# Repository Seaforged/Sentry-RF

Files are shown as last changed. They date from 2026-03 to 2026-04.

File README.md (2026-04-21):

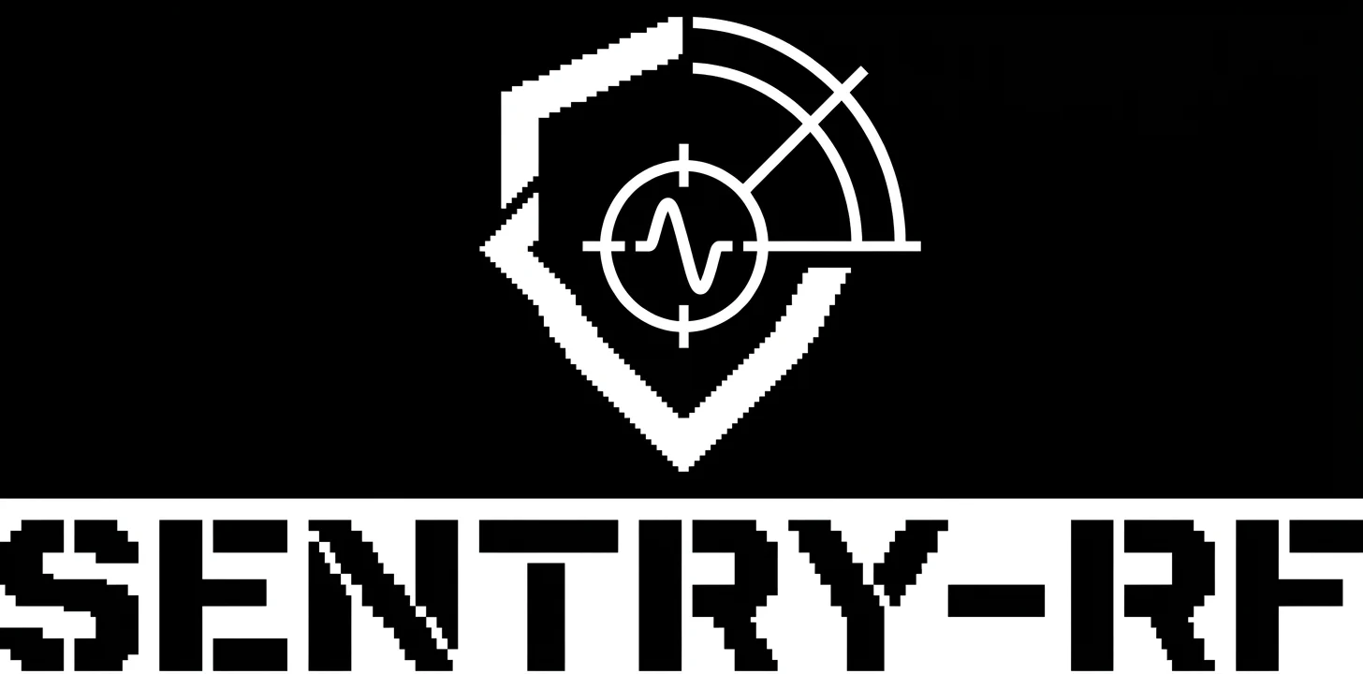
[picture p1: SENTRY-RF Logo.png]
SENTRY-RF


# SENTRY-RF

**Passive drone RF detection + GNSS jamming/spoofing monitor for ESP32-S3**




SENTRY-RF is an open-source counter-UAS trip-wire that detects drone control links and monitors GPS integrity using low-cost ESP32 hardware. No SDR required, no laptop required, no subscription. Built by [Seaforged](https://seaforged.io), a veteran-owned company.

---

## What It Does

**RF Drone Detection** — Passive scanning across 860–930 MHz (sub-GHz) and 2400–2500 MHz (2.4 GHz on LR1121 boards). Detects ExpressLRS, TBS Crossfire, SiK telemetry, mLRS, and other drone control links by matching FHSS patterns against known protocol signatures. Protocol-agnostic energy detection catches custom and encrypted links too.

**WiFi Remote ID** — Parses ASTM F3411 WiFi Beacon frames in real-time using the ESP32-S3's built-in WiFi in promiscuous mode. Identifies drones broadcasting FAA-mandated Remote ID with no extra hardware.

**GNSS Integrity Monitoring** — Reads u-blox M10 jamming indicators, spoofing detection state, and per-satellite C/N0 uniformity via UBX binary protocol. Emits standalone alerts on rising GNSS threat level (jam / spoof / position-jump / C/N0 uniformity anomaly); the candidate engine additionally uses GNSS anomalies as a confirm-score boost when RF detection has been active in the last 30 s. Position-jump detection compares consecutive NAV-PVT reports for >100 m teleports with tight hAcc — a signature of rebroadcast spoofing.

**Threat Classification** — Correlates RF detections with GNSS anomalies to produce actionable threat levels: `CLEAR → ADVISORY → WARNING → CRITICAL`. Buzzer alerts on WARNING+.

---

## Detection Performance (Bench Validated)

Tested against [Juh-Mak-In Jammer](https://github.com/Seaforged/Juh-Mak-In-Jammer) v2.0.0 drone signal emulator, April 2026:

| Protocol | Time to WARNING | Time to CRITICAL |
|---|---|---|
| ELRS 200Hz FCC915 | 3–12 s | 12–20 s |
| ELRS 25Hz FCC915 | ~71 s | — |
| TBS Crossfire FSK | ~34 s | — |
| SiK Telemetry | ~6 s | — |
| WiFi Remote ID | ~24 s | ~83 s |
| LoRaWAN (false positive test) | — stays ADVISORY | PASS |
| Meshtastic (false positive test) | — stays ADVISORY | PASS |

Field tested (v1.5.3, SX1262): 842m WARNING, 1022m ADVISORY against 158mW ELRS transmitter in suburban environment.

---

## Supported Hardware

| Board | Radio | Bands | Display | Status |
|---|---|---|---|---|
| **LilyGo T3S3** | Semtech SX1262 | 860–930 MHz | SSD1306 128×64 OLED | ✅ Field tested |
| **LilyGo T3S3 LR1121** | Semtech LR1121 | 860–930 MHz + 2400–2500 MHz | SSD1306 128×64 OLED | ✅ Bench validated |
| **Heltec WiFi LoRa 32 V3** | Semtech SX1262 | 860–930 MHz | SSD1306 128×64 OLED | ✅ Builds clean |

**GPS:** u-blox M10 module (HGLRC M100 Mini, FlyFishRC M10QMC, or similar) connected via UART. Auto-detects baud rate (115200/38400/9600).

**Optional:** QMC5883L compass for signal bearing, passive piezo buzzer for alerts, SD card for logging.

---

## Quick Start

### Prerequisites
- [PlatformIO](https://platformio.org/) (CLI or VS Code extension)
- One of the supported boards
- u-blox M10 GPS module + 4 jumper wires

### Build and Flash

```bash
git clone https://github.com/Seaforged/Sentry-RF.git
cd Sentry-RF

# Build for your board
pio run -e t3s3            # LilyGo T3S3 (SX1262)
pio run -e t3s3_lr1121     # LilyGo T3S3 LR1121 (dual-band)
pio run -e heltec_v3       # Heltec WiFi LoRa 32 V3

# Flash
pio run -e t3s3 --target upload

# Monitor serial output
pio device monitor
```

### GPS Wiring

| GPS Pin | T3S3 SX1262 | T3S3 LR1121 | Heltec V3 |
|---|---|---|---|
| TX → board RX | GPIO 44 | GPIO 43 | GPIO 46 |
| RX → board TX | GPIO 43 | GPIO 44 | GPIO 45 |
| VCC | 3.3V | 3.3V (QWIIC) | 3.3V |
| GND | GND | GND (QWIIC) | GND |

> **Note:** LR1121 QWIIC connector reverses data pins compared to the SX1262 sister board.

---

## OLED Display

7 screens, cycled via BOOT button press:

| Screen | Content |
|---|---|
| **Dashboard** | Threat level, GPS status, WiFi channel activity chart, peak RF signal, battery |
| **Sub-GHz Spectrum** | 860–930 MHz waterfall with peak frequency/power |
| **GPS** | Fix type, satellites, PDOP, coordinates, altitude, accuracy |
| **GNSS Integrity** | Jamming state, jamming indicator, spoofing detection, C/N0 deviation |
| **Threat Detail** | RF peak, GPS+jam+spoof status, buzzer state, bearing |
| **System** | Version, uptime, heap, buzzer/compass status |
| **2.4 GHz Spectrum** | 2400–2500 MHz waterfall (LR1121 boards only) |

See [`docs/OLED_Screen_Glossary.md`](docs/OLED_Screen_Glossary.md) for field-by-field reference.

---

## Architecture

- **FreeRTOS dual-core:** LoRa scanning on Core 1, GPS/WiFi on Core 0
- **Detection engine:** CAD (Channel Activity Detection) for LoRa preamble detection + RSSI sweep for energy detection + FHSS frequency-spread tracker for hopping signal classification
- **Protocol classifier:** Matches detected signals against 220+ drone protocol signatures
- **Ambient discrimination:** Learns background RF during warmup, filters LoRaWAN/Meshtastic/smart meter infrastructure from drone detections
- **Threat scoring:** Weighted combination of CAD confidence, frequency diversity, persistence, velocity, RSSI, and GNSS integrity

---

## Companion Projects

| Project | Description |
|---|---|
| [Juh-Mak-In Jammer](https://github.com/Seaforged/Juh-Mak-In-Jammer) | Drone signal emulator for testing SENTRY-RF. Emulates ELRS, Crossfire, SiK, mLRS, Remote ID, and infrastructure protocols. |
| **D-TECT-R** | Commercial counter-UAS product (separate from SENTRY-RF) |
| **TESTKIT-GPS** | GPS spoofing/jamming test tool using AntSDR E200 (planned) |

---

## Project Status

**v1.6.1-rc1** — Bench validated, April 2026.

Recent milestones:
- LR1121 dual-band board fully operational (CAD detection fix, 2.4 GHz bandwidth fix)
- FHSS frequency-spread tracker for hopping signal detection
- WiFi Remote ID detection via ESP32-S3 promiscuous scanning
- GPS auto-baud detection (115200/38400/9600)
- Boot-time antenna self-test with soft-warn
- 7-screen OLED UI with WiFi channel activity dashboard

Known limitations:
- mLRS detection stays at ADVISORY (narrow hop set, tuning gap)
- LR1121 ambient warmup list saturates in noisy RF environments
- 2.4 GHz CAD BW800 fix untested (needs 2.4 GHz transmitter)
- De-escalation after signal stops takes ~15 seconds (by design)

See [`docs/SENTRY-RF_Known_Issues_Tracker.md`](docs/SENTRY-RF_Known_Issues_Tracker.md) for full backlog.

---

## Documentation

| Document | Description |
|---|---|
| [`docs/OLED_Screen_Glossary.md`](docs/OLED_Screen_Glossary.md) | Field-by-field reference for every OLED display element |
| [`docs/Protocol_RF_Reference.md`](docs/Protocol_RF_Reference.md) | 220+ drone protocol signatures |
| [`docs/SENTRY-RF_Known_Issues_Tracker.md`](docs/SENTRY-RF_Known_Issues_Tracker.md) | Known issues and backlog |
| [`CLAUDE.md`](CLAUDE.md) | Claude Code project context |

---

## License

[MIT](LICENSE) — use it however you want.

## Contributing

Issues and PRs welcome. This is built in public by a veteran-owned company. If you see something that could be better, open an issue.

## Contact

- **Website:** [seaforged.io](https://seaforged.io)
- **GitHub:** [github.com/Seaforged](https://github.com/Seaforged)

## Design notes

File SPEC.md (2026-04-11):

# Spec: SENTRY-RF v1.6.0 — LR1121 Stabilization Release

**Status:** APPROVED 2026-04-10 — proceeding to PLAN phase
**Date:** 2026-04-10
**Author:** ND + Claude Code (agent-skills:spec-driven-development)

---

## Objective

Ship **SENTRY-RF v1.6.0** as a public release by end of day Sunday 2026-04-12, focused on stabilizing the T3S3 LR1121 board for first real-signal validation. The weekend "tester" is ND himself — goals are: (1) confirm the LR1121 board boots cleanly, renders all screens, and does not crash under load, and (2) observe and understand how the AAD detection engine reacts to real ELRS signals on both sub-GHz (915 MHz) and 2.4 GHz using a newly-acquired RadioMaster transmitter. A future external tester will receive the same build Monday or later.

**This is a stabilization release, not a feature release.** Everything on the "not yet built" list in `.mex/ROUTER.md` stays on the roadmap.

### Why this matters

- The LR1121 build has never been soak-tested or exercised against a real controlled RF signal — only bench ambient
- The 2.4 GHz CAD phase (added this week) has never seen a real 2.4 GHz ELRS signal
- The AAD detection engine's behavior on real signals has been validated on SX1262 (842m suburban field test) but not on the LR1121
- v1.5.3 on LR1121 has known-visible bugs (version string, unconfirmed spectrum rendering) that a first-time viewer will notice immediately

## Tech Stack

No changes from v1.5.3. See `.mex/context/stack.md` for the full list:
- C++ Arduino framework, PlatformIO, ESP32-S3
- RadioLib v7.6.0 (pinned — no upgrades this weekend)
- SparkFun u-blox GNSS v3, Adafruit SSD1306 + GFX
- FreeRTOS dual-core, 5 tasks pinned across Core 0 / Core 1

## Commands

All three targets must compile clean:
```
pio run -e t3s3 -e heltec_v3 -e t3s3_lr1121
```

LR1121-specific build / flash / monitor:
```
pio run -e t3s3_lr1121
pio run -e t3s3_lr1121 --target upload --upload-port COM14
pio device monitor -b 115200 -p COM14
```

Soak test (existing script, new application to LR1121):
```
cd C:\Projects\sentry-rf
python soak_test.py COM14 120   # 2-hour soak on LR1121
```

Signal response test (manual — RadioMaster TX + ND observation):
```
# Terminal 1:
python field_logger.py COM14

# Meanwhile: power up RadioMaster ELRS 915 MHz, observe serial + OLED
# Repeat for ELRS 2.4 GHz
```

## Project Structure

No structural changes. Existing layout stays:
- `include/` — board config, sentry config, task config, detection types
- `src/` — main, cad_scanner, rf_scanner, detection_engine, gps_manager, wifi_scanner, display, alert_handler, buzzer_manager
- `docs/` — gets a new `DETECTION_ENGINE_WALKTHROUGH.md` this weekend
- `test/lr1121_hello/` — existing hello sketch, left alone

See `.mex/context/architecture.md` for the FreeRTOS task layout.

## Code Style

No changes from v1.5.3. See `.mex/context/conventions.md`. Key reminders:
- No hardcoded pins — everything via `board_config.h`
- All three targets must compile clean before any commit
- Board-specific code wrapped in `#ifdef BOARD_T3S3 / BOARD_HELTEC_V3 / BOARD_T3S3_LR1121`
- LR1121 RSSI uses `LR1121_RSSI::getInstantRSSI()`, not bare `getRSSI()`

## Testing Strategy

Three test levels for this release:

### 1. Build verification (5 min, every commit)
`pio run -e t3s3 -e heltec_v3 -e t3s3_lr1121` must succeed with zero errors. This is the baseline gate.

### 2. Boot and render verification (10 min, after every LR1121 flash)
Flash, power cycle, manually verify:
- Serial banner prints `SENTRY-RF v1.6.0` within 2 seconds
- OLED splash → dashboard transition within 60 seconds (warmup)
- All 7 screens cycle cleanly via short BOOT button press
- Spectrum screens (sub-GHz and 2.4 GHz) show visible bars, not blank
- System screen has no text/page-dot collision
- No error messages on OLED, no crashes in serial
- First `[CAD]` line shows `score=5` (baseline after warmup)

### 3. Signal response and soak (weekend, manual, ND-driven)
- **Saturday afternoon:** RadioMaster ELRS 915 MHz within ~1-5m of antenna → observe serial + OLED while the detection engine escalates from CLEAR through ADVISORY → WARNING → CRITICAL. Turn TX off, observe cooldown. Capture serial log for the walkthrough document.
- **Saturday evening:** Same exercise at ELRS 2.4 GHz. This is the first-ever real 2.4 GHz ELRS signal test on this codebase.
- **Sunday morning:** 2-hour LR1121 bench soak with no drones present — no crashes, no false positives above ADVISORY, memory stable (monitor heap via serial).
- **Sunday afternoon:** Multi-environment walk — bench → backyard → rural road → suburban — with the RadioMaster running. Confirm detection works end-to-end.

**Test recording:** All serial sessions captured with `field_logger.py` for reference in the walkthrough doc and release notes.

## Boundaries

### Always
- Run `pio run -e t3s3 -e heltec_v3 -e t3s3_lr1121` before every commit
- Connect the antenna before powering on any board (non-negotiable; RF damage)
- Use the mex workflow — read `.mex/ROUTER.md` at the start of each session, update on GROW
- Commit after every working increment, not at the end of a sprint
- Tag known-good states as we go (e.g., `v1.6.0-rc1` before the soak test)

### Ask first
- Anything that touches `sentry_config.h` constants (AAD gates, scoring weights, thresholds) — these are field-calibrated and we don't tune them without data
- Adding a new `#ifdef` guard (risk of board-specific drift)
- Changing the FreeRTOS task layout (priorities, cores, stack sizes)
- Modifying the Detection Engine scoring math

### Never
- Add BLE Remote ID, 2.4 GHz protocol classification, operational modes, or any other "not yet built" item from ROUTER
- Upgrade RadioLib mid-weekend
- Push to origin without an explicit "push it" from ND
- Use `--no-verify` or `--force` on git operations
- Remove failing tests or soak data to make things look clean

## Success Criteria

v1.6.0 ships if and only if **all** of these are true by Sunday evening:

1. **Clean build:** `pio run -e t3s3 -e heltec_v3 -e t3s3_lr1121` — zero errors, zero warnings introduced this release
2. **Version sanity:** `grep -r "v1.2.0-FIX4\|v1.5.3" src/ include/` returns nothing (after the fix); `version.h` reads `1.6.0`; boot banner prints `SENTRY-RF v1.6.0`
3. **Boot behavior on LR1121:** Serial banner within 2 seconds of USB plug-in on a fresh flash, no template placeholders, no error dumps
4. **All 7 OLED screens render** on the LR1121 with no visible text collisions or blank chart areas. Verified by ND's eyes, captured in photos for the release notes
5. **Boot self-test catches a missing antenna** (Tier 2 work item below) — remove the SMA antenna, power on, confirm OLED shows `ANTENNA CHECK` or equivalent, confirm scan task does not start
6. **Real signal response on sub-GHz** — RadioMaster ELRS 915 MHz at close range drives the LR1121 from CLEAR → CRITICAL within 15 seconds. Cooldown returns to CLEAR within 15 seconds after TX off
7. **Real signal response on 2.4 GHz** — RadioMaster ELRS 2.4 GHz at close range produces visible detection in the serial log (CAD taps increment, or persDiv rises). **No target timing number** — document actual observed timing for future calibration. The 2.4 GHz CAD phase has never seen a real ELRS 2.4 signal; this is a first-light test, not a benchmark.
8. **2-hour soak on the LR1121** — zero cycles above WARNING with no drone present, zero crashes, heap stable within ±5% of start
9. **`docs/DETECTION_ENGINE_WALKTHROUGH.md` exists** — annotated serial log from the real-signal tests, explaining what each `[CAD]` field means and how the AAD gates fire in practice
10. **v1.6.0 tagged, release notes written, pushed to origin** — public GitHub release with the walkthrough doc and field test summary linked

If any of 1-9 fail, do NOT do 10. Ship when green, not when the calendar says so.

## Work Items (prioritized)

### TIER 1 — Small, low-risk (Saturday morning, before RadioMaster arrives)
- [ ] **T1.1 Version audit** — grep for `v1.2.0-FIX4` and stale v1.5.x references in `src/` and `include/`, remove. Bump `version.h` to `1.6.0`. (~15 min)
- [ ] **T1.2 Serial boot banner sanity** — flash LR1121, confirm banner prints cleanly within 2s of USB plug-in. Fix if not. (~15 min)
- [ ] **T1.3 Visual verification of spectrum bar rendering** — power on LR1121, cycle to Sub-GHz and 2.4 GHz spectrum screens, confirm bars are visible (not blank). Photograph for release notes. (~15 min)
- [ ] **T1.4 System screen collision check** — cycle to Screen 5 on the LR1121, confirm "Buz: ... Cmp: ..." line does not overlap the page dots. (~5 min)
- [ ] **T1.5 GPS + buzzer bring-up** — with the newly-wired GPS + buzzer, confirm `[GPS] Fix:3` in serial within 60s outdoors, and buzzer self-test tone on boot. (~30 min)
- [ ] **T1.6 All-three build gate** — `pio run -e t3s3 -e heltec_v3 -e t3s3_lr1121`. (5 min)

### TIER 2 — Stabilization (Saturday afternoon)
- [ ] **T2.1 Boot self-test: antenna check (ALL 3 boards)** — at the end of `scannerInit()`, sweep 10 test frequencies across 860-928 MHz and read RSSI. If all ≤ threshold (config constant, default -125 dBm), display `ANTENNA CHECK` on OLED and halt the scan task. If any > threshold, proceed normally. Implement once in `rf_scanner.cpp`, wire into all three board targets (SX1262 T3S3, Heltec V3, LR1121). Test SX1262 first (known-working baseline from the 30-min soak), then Heltec, then LR1121. Document the threshold as a config constant. (~3-6 hrs)
- [ ] **T2.2 Human-readable error messages on init failure** — replace `RADIO HW FAIL: -12` with a table lookup that maps common RadioLib error codes to operator-friendly text. (~1-2 hrs)
- [ ] **T2.3 Boot banner print order cleanup** — ensure `SENTRY-RF v1.6.0` prints BEFORE any init errors, so tester sees the version even on a failed boot. (~30 min)

### TIER 3 — Real-signal validation (Saturday afternoon → Sunday evening)
- [ ] **T3.1 Sub-GHz 915 MHz ELRS response test** — flash LR1121, power up RadioMaster ELRS 915, capture serial log with `field_logger.py`. Observe: time-to-ADVISORY, time-to-WARNING, time-to-CRITICAL, peak score, peak `persDiv`, cooldown-to-CLEAR. Compare against SX1262 baseline (6.4s WARNING / 11.2s CRITICAL). (~1-2 hrs)
- [ ] **T3.2 2.4 GHz ELRS response test (FIRST EVER)** — flash LR1121, power up RadioMaster ELRS 2.4 GHz, capture serial log. Observe: does the 2.4 GHz CAD phase produce hits? Does `div` increase? Does `persDiv` activate? Pass criterion is "detection is visible in serial log," tighter timing metrics are nice-to-have. (~1-2 hrs)
- [ ] **T3.3 Multi-environment walk** — with RadioMaster running, walk bench → backyard → rural → suburban, observe detection stability. No specific range goal (that's a post-stabilization exercise). (~1-2 hrs)
- [ ] **T3.4 2-hour LR1121 bench soak** — no drones present. Zero escalations above ADVISORY target. Use existing `soak_test.py COM14 120`. (~2 hrs, mostly waiting)

### TIER 4 — Tester enablement + release (Sunday afternoon / evening)
- [ ] **T4.1 `docs/DETECTION_ENGINE_WALKTHROUGH.md`** — annotated walkthrough of a real sub-GHz ELRS session. Show the serial log, explain each `[CAD]` field (cycle, conf, taps, div, persDiv, vel, sustainedCycles, score), map the AAD gates to observed behavior, explain why score stays at 5 until sustainedCycles hits 5, show the ambient warmup, show the diversity gate firing. Uses logs captured in T3.1/T3.2. (~2-3 hrs)
- [ ] **T4.2 Release notes for v1.6.0** — public-facing. Headline: first LR1121 stabilization release. Include: what was fixed, what was added (dual-band CAD, boot self-test), what's known-limited (2.4 GHz timing not yet calibrated), what's next on the roadmap. Link to the walkthrough doc. Include signal-response metrics from T3.1. (~1 hr)
- [ ] **T4.3 Update `.mex/ROUTER.md` Current Project State** — mark v1.6.0 as shipped, move completed items out of "not yet built", update "Known issues". (~15 min)
- [ ] **T4.4 Tag `v1.6.0`, create GitHub release, push to origin** — only if all Success Criteria are met. (~30 min)

### TIER 5 — Explicitly cut from this release (stays on roadmap)
- SD card fix (hardware limitation)
- BLE Remote ID scanning (feature, roadmap Phase D1)
- 2.4 GHz protocol classification (feature, roadmap Phase C1)
- Per-band diversity tracking (refactor, roadmap Phase C2)
- Dual-band correlation engine (feature, roadmap Phase D2)
- Operational modes COVERT / HIGH_ALERT (feature, roadmap Phase E1)
- Tester-oriented quickstart doc (ND is the weekend tester, defer until external tester confirmed)

## Resolved Questions (2026-04-10)

1. **2.4 GHz timing target:** No target number. Document actual observed timing; future release will calibrate against it.
2. **Boot self-test scope:** All three boards (SX1262 T3S3, Heltec V3, LR1121). Test order: SX1262 → Heltec → LR1121 to build on a known-good baseline.
3. **Walkthrough doc location:** `docs/DETECTION_ENGINE_WALKTHROUGH.md` in the SENTRY-RF repo, linked from the v1.6.0 release notes.
4. **Soak script compatibility:** Serial format is identical to SX1262, so `soak_test.py` should work as-is. Verify during T3.4; if it fails, it's a script bug not a firmware bug.

## Verification (before proceeding to PLAN phase)

- [ ] This spec covers all six core areas (Objective, Stack, Commands, Structure, Code Style, Testing Strategy, Boundaries)
- [ ] ND has reviewed and approved the spec
- [ ] Success criteria are specific and testable
- [ ] Boundaries (Always / Ask First / Never) are defined
- [ ] The spec is saved to `SPEC.md` in the repository root
- [ ] Open questions have proposed answers or are marked for resolution

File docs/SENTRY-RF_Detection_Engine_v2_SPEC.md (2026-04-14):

<!-- ACTIVE SPEC — supersedes SENTRY-RF_Detection_Engine_v2_Redesign.md and SENTRY-RF_Architecture_Checklist.md -->
<!-- Last updated: April 14, 2026 | Current phase: COMPLETE -->

# SENTRY-RF Detection Engine v2.0 — Unified Implementation Spec
## Candidate-Centric Evidence Fusion: The Build Contract

**Status:** ACTIVE — supersedes all prior detection engine planning documents  
**Supersedes:** `SENTRY-RF_Detection_Engine_v2_Redesign.md`, `SENTRY-RF_Architecture_Checklist.md`  
**Use `SENTRY-RF_Session_Handoff.md` for:** onboarding/context only  
**Authors:** Claude (technical lead) + Codex (adversarial review) + ND (project owner)  
**Last updated:** April 13, 2026  
**Current codebase:** v1.8.0 — commit 61dae2e  

---

## Part 1 — Why This Redesign Exists

The v1.8.0 detection engine uses **global counters**. Every piece of evidence — CAD taps, RSSI peaks, protocol matches, Remote ID, GNSS anomalies — feeds into one shared fast score and one shared confirm score. This causes three failures:

**1. Unrelated evidence summation.**  
A single infrastructure LoRa tap (fast=10) plus a real WiFi RID broadcast (confirm=30) equals WARNING. These are completely unrelated events that happened to occur in the same scan window. They should never promote each other.

**2. Brittle confirmation timing.**  
Confirm evidence only exists on the exact RSSI sweep cycle (`freshRssi=true`) and vanishes on non-sweep cycles. One good sweep should provide confirmation that persists for several seconds across multiple scan cycles — not disappear the moment the next non-sweep cycle runs.

**3. No candidate association.**  
The engine cannot say "this RSSI peak at 919 MHz corroborates this CAD tap at 919.2 MHz." It just sums everything globally. There is no concept of a specific detection event that evidence must attach to in order to promote.

**The fix: candidate-centric evidence fusion.**  
Sub-GHz CAD creates a detection candidate. Subsequent evidence — RSSI, protocol match, 2.4 GHz CAD, Remote ID, GNSS anomaly — must be *explicitly associated* with that candidate to promote it. Evidence decays with configurable TTLs measured in wall-clock milliseconds, not scan cycles.

---

## Part 2 — Architecture

```
┌─────────────────────────────────────────────────────────┐
│                      SCAN LAYER                          │
│  cadSubGHzFskScan() → CadBandSummary + anchor           │
│  cad24Scan()        → CadBandSummary + anchor (timer)   │
│  scannerSweep()     → ScanResult sub-GHz (timer)        │
│  scannerSweep24()   → ScanResult24 2.4 GHz (timer)      │
│  wifiScanTask()     → RID evidence (async)               │
│  gpsTask()          → GNSS integrity (async)             │
└───────────────────────────┬─────────────────────────────┘
                             │
                             ▼
┌─────────────────────────────────────────────────────────┐
│                   CANDIDATE ENGINE                        │
│                                                          │
│  DetectionCandidate[MAX_CANDIDATES=6]                    │
│                                                          │
│  ┌────────────────────────────────────────────────┐     │
│  │ candidate 0 (sub-GHz, SEEDING → TRACKING)       │     │
│  │   anchor:    919.2 MHz / SF6                    │     │
│  │   freqRange: [918.5, 920.1 MHz]                 │     │
│  │   cadConf:   {score=40, lastSeen=Xms, live}     │     │
│  │   fhssSub:   {score=15, lastSeen=Xms, live}     │     │
│  │   sweepSub:  {score=5,  lastSeen=Xms, live}     │     │
│  │   protoSub:  {score=15, lastSeen=Xms, live}     │     │
│  │   rid:       {score=0,  dead}                   │     │
│  │   → fast=55, confirm=20 → WARNING               │     │
│  └────────────────────────────────────────────────┘     │
│                                                          │
│  ┌────────────────────────────────────────────────┐     │
│  │ candidate 1 (confirmer role only)               │     │
│  │   cad24: {score=10, lastSeen=Xms, live}         │     │
│  │   → attaches to candidate 0 (temporal match)    │     │
│  └────────────────────────────────────────────────┘     │
│                                                          │
│  chooseBestCandidate() → ThreatDecision                  │
└───────────────────────────┬─────────────────────────────┘
                             │
                             ▼
┌─────────────────────────────────────────────────────────┐
│                     THREAT FSM                            │
│  Fast up: direct jump to evidence-warranted level        │
│  Slow down: one step per COOLDOWN_MS                     │
│  emitThreatTransition(prev, next, nowMs) on change       │
└─────────────────────────────────────────────────────────┘
```

### Main Loop Execution Order (mandatory)

The following order is required in `src/main.cpp`. Deviating from this order breaks the fast-alert guarantee.

```
1. cadSubGHzFskScan()              → produces CadBandSummary + anchor
2. detectionEngineIngestCadSubGHz() → refreshes candidate fast evidence
3. detectionEngineAssess()          → produces ThreatDecision, updates FSM
4. publish threat to systemState    → OLED, LED, buzzer, log see result

[on timer] sub-GHz sweep ingest
[on separate timer] LR1121 2.4 GHz CAD ingest
[on separate timer] LR1121 2.4 GHz sweep ingest
```

**The 2.4 GHz scan must never run before the first assess of the same cycle.** It is a confirmer. It never drives the fast-alert path.

---

## Part 3 — Data Structures

These structs are the exact contract CC must implement. Do not deviate without ND sign-off.

### 3.1 EvidenceTerm

```cpp
struct EvidenceTerm {
    uint8_t  score;        // Current score value (0 = dead)
    uint32_t lastSeenMs;   // millis() when last refreshed
    uint32_t ttlMs;        // Evidence expires when (millis() - lastSeenMs) > ttlMs
    bool     ready;        // Per-evidence readiness gate (see Part 6)
};
```

An EvidenceTerm is **live** when: `ready == true && score > 0 && (millis() - lastSeenMs) <= ttlMs`

### 3.2 CandidateState

```cpp
enum CandidateState : uint8_t {
    CAND_EMPTY,      // Slot is free
    CAND_SEEDING,    // Just created, first CAD anchor seen
    CAND_TRACKING,   // Active, live fast evidence
    CAND_CONFIRMED   // ThreatDecision is WARNING or CRITICAL
};
```

### 3.3 DetectionCandidate

```cpp
struct DetectionCandidate {
    CandidateState      state;
    bool                active;
    uint8_t             bandMask;        // 1=subGHz, 2=2.4GHz, 3=both
    float               anchorFreq;      // MHz — frequency of best CAD tap at creation
    float               minFreqSeen;     // MHz — lowest frequency associated so far
    float               maxFreqSeen;     // MHz — highest frequency associated so far
    const DroneProtocol* protoHint;      // nullptr until protocol matched; NEVER store stale pointer
    uint32_t            firstSeenMs;
    uint32_t            lastSeenMs;
    EvidenceTerm        cadConfirmed;    // Confirmed CAD taps (consecutiveHits >= 2)
    EvidenceTerm        cadPending;      // Pending CAD taps (single hit)
    EvidenceTerm        fskConfirmed;    // Confirmed FSK taps
    EvidenceTerm        fhssSub;         // FHSS velocity / spread evidence
    EvidenceTerm        sweepSub;        // RSSI sweep corroboration
    EvidenceTerm        protoSub;        // Protocol signature match
    EvidenceTerm        cad24;           // 2.4 GHz CAD corroboration
    EvidenceTerm        proto24;         // 2.4 GHz protocol match
    EvidenceTerm        rid;             // WiFi Remote ID
    EvidenceTerm        gnss;            // GNSS anomaly temporal correlation
};
```

**Critical implementation note on `protoHint`:**  
Always initialize to `nullptr`. When `resetCandidate()` is called, set `protoHint = nullptr` immediately. Never read `protoHint` without checking `!= nullptr` first. A reset candidate with a stale non-null `protoHint` silently influences scoring — this is a subtle bug CC must be guarded against explicitly.

### 3.4 CadEvidenceAnchor (add to CadBandSummary)

```cpp
struct CadEvidenceAnchor {
    bool    valid;
    float   frequency;        // MHz of best tap
    uint8_t sf;               // Spreading factor of best tap
    bool    isFsk;
    uint8_t consecutiveHits;  // Hits on this tap in last cycle
};
```

Add to `CadBandSummary`:
```cpp
CadEvidenceAnchor anchor;
uint32_t          capturedMs;    // millis() when summary was produced
bool              warmupReady;   // ambient filter has run >= MIN_AMBIENT_CYCLES
bool              hwFault;       // cadHwFaultFlag debounced true
```

### 3.5 ThreatDecision

```cpp
struct ThreatDecision {
    ThreatLevel level;
    uint8_t     fastScore;
    uint8_t     confirmScore;
    float       anchorFreq;     // MHz of driving candidate
    uint8_t     bandMask;       // bands contributing to decision
    bool        hasCandidate;   // false = RID-only ADVISORY
};
```

---

## Part 4 — Configuration Constants

Add all of the following to `include/sentry_config.h`. These are the values as of April 13, 2026. Do not hardcode any of these inline in .cpp files.

```cpp
// --- Candidate engine sizing ---
#define MAX_CANDIDATES              6
#define CAND_AGE_OUT_MS             12000   // Evict if all evidence dead > 12s

// --- Association windows ---
#define CAND_ASSOC_SUB_MHZ          1.0f    // Sub-GHz evidence must be within ±1 MHz of anchor
#define CAND_ASSOC_24_MHZ           4.0f    // 2.4 GHz evidence association window ±4 MHz
#define CAND_ASSOC_SUB_TTL_MS       6000    // Sub-GHz evidence attaches only if candidate seen within 6s
#define CAND_ASSOC_24_TTL_MS        5000    // 2.4 GHz evidence attaches only if candidate seen within 5s

// --- Evidence TTLs (milliseconds) ---
#define TTL_CAD_CONFIRMED_MS        2500
#define TTL_CAD_PENDING_MS          2500
#define TTL_FSK_CONFIRMED_MS        2500
#define TTL_FHSS_SUB_MS             3000
#define TTL_SWEEP_SUB_MS            4500
#define TTL_PROTO_SUB_MS            6000
#define TTL_CAD24_MS                5000
#define TTL_PROTO24_MS              5000
#define TTL_RID_MS                  10000
#define TTL_GNSS_MS                 8000

// --- Scoring policy thresholds ---
#define POLICY_ADVISORY_FAST        15
#define POLICY_WARNING_FAST         40
#define POLICY_WARNING_CONFIRM      5
#define POLICY_CRITICAL_FAST        40
#define POLICY_CRITICAL_CONFIRM     30
#define POLICY_RID_ONLY_ADVISORY    30      // RID confirm score for ADVISORY without RF candidate

// --- Fast score component caps ---
#define FAST_SCORE_CAD_PER_TAP      10
#define FAST_SCORE_CAD_CAP          40
#define FAST_SCORE_FSK_PER_TAP      15
#define FAST_SCORE_FSK_CAP          30
#define FAST_SCORE_DIVERSITY_BONUS  20
#define FAST_SCORE_FHSS_CLUSTER     15
```

---

## Part 5 — Candidate Creation Rules

A candidate **may only be created** by `detectionEngineIngestCadSubGHz()` when ALL of the following are true:

- `summary.anchor.valid == true`
- `summary.hwFault == false`
- At least one is true:
  - `confirmedCadCount > 0`
  - `confirmedFskCount > 0`
  - `strongPendingCad > 0`
  - `persistentDiversityCount > 0`
  - `diversityVelocity >= DIVERSITY_VELOCITY_FHSS_MIN`

A candidate **must never be created** by:
- 2.4 GHz CAD
- Sweep-only evidence
- Remote ID
- GNSS

This keeps the fast-trigger path identical across SX1262, Heltec V3, and LR1121.

---

## Part 6 — Association Rules

These rules determine whether a piece of evidence attaches to an existing candidate. Evidence that fails association is discarded (or, for RID/GNSS, generates a standalone ADVISORY only).

### Sub-GHz evidence (CAD, sweep, protocol)

Attaches to a candidate only if **all** are true:
- `candidate.active == true`
- `millis() - candidate.lastSeenMs <= CAND_ASSOC_SUB_TTL_MS`
- Evidence frequency is in the same regional band as the candidate (US 902–928 MHz or EU 860–870 MHz)
- **And at least one** of:
  - `fabs(freq - candidate.anchorFreq) <= CAND_ASSOC_SUB_MHZ`
  - `freq` falls within `[candidate.minFreqSeen - 1.0, candidate.maxFreqSeen + 1.0]`
  - Candidate has live `fhssSub` evidence AND freq is in the same regional band (FHSS association by band)

When evidence attaches, update `candidate.minFreqSeen` and `candidate.maxFreqSeen` to expand the range if needed.

### 2.4 GHz evidence (CAD, sweep, protocol)

Attaches to a sub-GHz candidate only if **all** are true:
- At least one active sub-GHz candidate exists
- `millis() - candidate.lastSeenMs <= CAND_ASSOC_24_TTL_MS`
- **And one** of:
  - Exactly one live sub-GHz candidate exists (unambiguous association)
  - One candidate's fast score exceeds the next-best candidate's fast score by at least 15 (clear leader)

2.4 GHz evidence **never creates a candidate**. It is confirmer-only.

### Remote ID and GNSS

Attach only if:
- Exactly one live candidate exists

If RID or GNSS cannot be uniquely attached to a single candidate, they may generate a standalone RID-only ADVISORY (if `ridScore >= POLICY_RID_ONLY_ADVISORY`) but **must not promote any RF candidate to WARNING or CRITICAL**.

---

## Part 7 — Evidence Readiness Gates

These gates determine whether each evidence type is allowed to contribute to scoring. This replaces the old global warmup cap.

| Evidence | Ready When |
|---|---|
| `cadConfirmed` | Always (cycle 1) |
| `cadPending` | Always (cycle 1) |
| `fskConfirmed` | Always (cycle 1) |
| `fhssSub` | `persistentDiversityCount > 0` OR `diversityVelocity >= DIVERSITY_VELOCITY_FHSS_MIN` |
| `fhssCluster` | `diversityCount >= 8` AND `fastConfirmedCadCount >= 1` |
| `sweepSub` | `ambientFilterReady()` OR peak matches a known protocol family OR candidate already has live fast evidence |
| `protoSub` | Always when `match.protocol != nullptr` |
| `bandEnergy` | `ambientFilterReady()` only; attach as candidate-confirm only |
| `cad24` | Only as confirmer on existing live sub-GHz candidate |
| `proto24` | Only as confirmer on existing live sub-GHz candidate |
| `rid` | Always (independent hardware) |
| `gnss` | GPS has valid 3D fix |

### Progressive ambient tagging (B.5 — must happen BEFORE shadow mode)

During warmup, after each `recordAmbientTap()` call: immediately scan all live candidate taps and mark any tap at that frequency as `isAmbient`. Do not wait until warmup ends to do a batch tag. This prevents warmup-period infrastructure taps from being inherited as evidence into the candidate engine.

---

## Part 8 — Candidate Lifecycle

### States

| State | Meaning | Entry Condition |
|---|---|---|
| `CAND_EMPTY` | Slot free | Initial / after eviction |
| `CAND_SEEDING` | Just created | First valid sub-GHz CAD anchor |
| `CAND_TRACKING` | Active | Any live fast evidence |
| `CAND_CONFIRMED` | Promoted | `ThreatDecision.level >= WARNING` |

### Age-out and eviction

- A candidate is aged out when **all evidence terms are dead** for `> CAND_AGE_OUT_MS`
- Eviction order when all slots full: **oldest inactive candidate first**, then **lowest total live score**
- Caveat: do not evict the only `CAND_CONFIRMED` candidate unless it has been dead for `> CAND_AGE_OUT_MS`

### Required lifecycle helpers (implement in `src/detection_engine.cpp`)

```
resetCandidate()           — zero all fields, protoHint = nullptr
findCandidateForBandFreq() — returns best matching candidate or nullptr
allocCandidate()           — finds empty slot or evicts per eviction rules
refreshEvidence()          — updates score + lastSeenMs on a term if association passes
evidenceLive()             — returns bool: ready && score > 0 && not expired
ageOutCandidates()         — marks CAND_EMPTY on fully-expired candidates
computeFastScore()         — returns uint8_t: sum of live fast terms, capped
computeConfirmScore()      — returns uint8_t: sum of live confirm terms
chooseBestCandidate()      — returns ThreatDecision from highest-scoring live candidate
```

---

## Part 9 — Scoring Policy

Scoring uses **candidate-attached evidence only**. Global scores do not exist in v2.0.

### Fast score (per candidate)

```
fast = cadConfirmed.score
     + cadPending.score
     + fskConfirmed.score
     + (fhssSub live     ? FAST_SCORE_DIVERSITY_BONUS : 0)
     + (fhssCluster live ? FAST_SCORE_FHSS_CLUSTER    : 0)
```

Component values:
- Confirmed CAD taps: `FAST_SCORE_CAD_PER_TAP` per tap, cap `FAST_SCORE_CAD_CAP`
- Confirmed FSK taps: `FAST_SCORE_FSK_PER_TAP` per tap, cap `FAST_SCORE_FSK_CAP`
- `fhssSub` live when sustained diversity is present:
  `persistentDiversityCount > 0` OR
  `diversityVelocity >= DIVERSITY_VELOCITY_FHSS_MIN`
- Live `fhssSub`: `+FAST_SCORE_DIVERSITY_BONUS`
- Live `fhssCluster`: `+FAST_SCORE_FHSS_CLUSTER`
  with `diversityCount >= 8` AND `fastConfirmedCadCount >= 1`

### Confirm score (per candidate)

```
confirm = sweepSub.score
        + protoSub.score
        + bandEnergy.score
        + cad24.score
        + proto24.score
        + rid.score
        + gnss.score
```

Component values:

| Evidence | First attach | Persistent (re-attaches) |
|---|---|---|
| `sweepSub` (RSSI corroboration) | 5 | 10 |
| `protoSub` (protocol match) | 15 | 15 |
| `cad24` (2.4 GHz corroboration) | 10 | 10 |
| `proto24` (2.4 GHz protocol) | 15 | 15 |
| `rid` (WiFi Remote ID) | 30 | 30 |
| `gnss` (anomaly correlation) | 25 | 25 |

### Threat policy

```
ADVISORY:   fast >= POLICY_ADVISORY_FAST
WARNING:    fast >= POLICY_WARNING_FAST  &&  confirm >= POLICY_WARNING_CONFIRM
CRITICAL:   fast >= POLICY_CRITICAL_FAST &&  confirm >= POLICY_CRITICAL_CONFIRM
RID-only:   confirm(rid) >= POLICY_RID_ONLY_ADVISORY  (no fast evidence required)
```

**All fast and confirm evidence must come from the SAME candidate.** Fast score from candidate 0 cannot combine with confirm score from candidate 1.

### FSM behavior

- **Fast up:** Direct jump to the level warranted by current evidence (no step-by-step escalation)
- **Slow down:** One step per `COOLDOWN_MS`
- **Transitions:** `emitThreatTransition(prevThreat, currentThreat, millis())` — this is the single emit point for buzzer, LED, display updates, and log entries on state change

---

## Part 10 — Phase Plan

Phases must be executed in this exact order. Do not skip phases or combine them out of sequence.

---

### Phase A — Foundation Fixes
**Risk:** Zero — corrective only, no behavior change  
**Acceptance:** All three targets build clean. Serial output identical to pre-A.

**A.1 — Fix escalation emitter** (`src/detection_engine.cpp`)  
Save `prevThreat` before computing `desired`. Add `emitThreatTransition(prev, next, nowMs)` helper. Replace all inline transition emit code with single call to this helper. No-op if `prev == next`.

**A.2 — Replace sweepTimeMs validity check** (`src/main.cpp`)  
Replace `localResult.sweepTimeMs > 0 ? &localResult : nullptr` with `localResult.valid ? &localResult : nullptr`. If `ScanResult` lacks a `valid` field, add `bool valid = false;` to the struct and set `valid = true` only on successful sweep completion.

**A.3 — Initialize logSnapshot safely** (`src/main.cpp`)  
Change declaration to `SystemState logSnapshot = {};`. Skip `loggerWrite()` if mutex was not acquired.

**A.4 — Add all configuration constants** (`include/sentry_config.h`)  
Add the full block from Part 4 above. Build to verify no name collisions with existing constants.

---

### Phase B — Enriched CAD Summaries
**Risk:** Low — additive struct extension, no logic change  
**Acceptance:** Build clean. Anchor frequency visible in `[CAD]` serial debug output. Existing threat behavior unchanged.

**B.1 — Add `CadEvidenceAnchor` and new fields to `CadBandSummary`** (`include/cad_scanner.h`)  
Add the structs defined in Part 3.4 above.

**B.2 — Implement `chooseAnchor()`** (`src/cad_scanner.cpp`)  
Priority: best confirmed non-ambient tap → strongest pending tap → first active tap. Helpers: `tapEligibleAsAnchor()`, `betterAnchor()`, `chooseAnchor()`.

**B.3 — Populate anchor in `fillBandSummary()`** (`src/cad_scanner.cpp`)  
Call `chooseAnchor()` in both LR1121 and SX1262 `cadFskScan()` paths. Keep all legacy aggregate fields intact.

---

### Phase B.5 — Progressive Ambient Tagging During Warmup
**Risk:** Low — changes warmup behavior, not detection policy  
**Acceptance:** Cold boot, 5 runs each board. Zero false WARNING/CRITICAL in first 60 seconds. Check `[AMBIENT]` serial output shows infrastructure taps tagged progressively, not in a batch at warmup end.

**B.5.1 — Move ambient tagging to per-cycle** (`src/cad_scanner.cpp` near line 1117)  
After each `recordAmbientTap(freq)` call, immediately iterate all live taps and set `isAmbient = true` on any tap matching that frequency. Do not wait for warmup to end.

**B.5.2 — Remove post-warmup batch reset** (`src/cad_scanner.cpp`)  
Delete or disable the block that clears all taps/proto arrays when warmup ends. Infrastructure taps should be progressively marked ambient throughout warmup, not wiped in batch.

**B.5.3 — Verify no regression** in Phase A/B serial output before continuing.

---

### Phase C — Shadow-Mode Candidate Engine
**Risk:** Low — new code runs in parallel, actual threat output unchanged  
**Acceptance:** See shadow-mode acceptance criteria in Part 11.

**C.1 — Add candidate structs and TTL config** (`include/detection_engine.h`, `include/sentry_config.h`)  
Implement `EvidenceTerm`, `DetectionCandidate`, `ThreatDecision`, `CandidateState` per Part 3.

**C.2 — Implement candidate lifecycle helpers** (`src/detection_engine.cpp`)  
Implement all helpers listed in Part 8. Pay special attention to `protoHint = nullptr` in `resetCandidate()`.

**C.3 — Shadow-mode evaluation in `detectionEngineAssess()`**  
After the existing scorer runs:
- Ingest current CAD summary into candidate engine
- Compute candidate-based `ThreatDecision`
- Log: `[CAND] fast=%d conf=%d level=%s anchor=%.1fMHz ttMs=%lu`
- Log mismatches: `[CAND-DELTA] legacy=%s candidate=%s`
- **Do NOT change actual threat output**

**C.4 — Bench validation (required before Phase D)**  
Run each scenario and collect serial logs:
- SX1262: 10 min clean bench
- LR1121: 10 min clean bench
- SX1262: 3 runs JJ ELRS (time to ADVISORY, WARNING)
- LR1121: 3 runs JJ ELRS (time to ADVISORY, WARNING)
- Both boards: cold boot x5 (watch first 60s)

Bring logs to Claude before proceeding to Phase D.

---

### Phase D — Candidate Engine Cutover
**Risk:** Medium — this changes actual threat behavior. Run full validation before AND after.  
**Acceptance:** See Part 11. Both boards must pass before this phase is complete.

**D.1 — Cut over CAD ingest to per-candidate** (`src/detection_engine.cpp`, `src/main.cpp`)  
`detectionEngineIngestCadBandSummary()` refreshes candidate fast evidence.
`detectionEngineIngestCad24BandSummary()` refreshes cad24 on existing
candidates only (never creates). Aggregate CAD/FSK counters may remain wired
to the legacy comparison scorer until Phase G, but they must not drive the
real FSM or candidate scoring.

**D.2 — Cut over sweep ingest to candidate confirmation** (`src/detection_engine.cpp`)  
First corroborating sweep: `sweepSub.score = 5`, `sweepSub.ttlMs = TTL_SWEEP_SUB_MS`. Protocol match: `protoSub.score = 15`. Persistent sweep: upgrade score in-place.

**D.3 — Replace `assessThreat()` with `chooseBestCandidate()`**  
`chooseBestCandidate()` becomes the real threat decision path. Keep
`lastFastScore`, `lastConfirmScore` for display/logging. Legacy global scoring
may remain comparison-only for regression alarming until Phase G, but it must
not commit `currentThreat` or emit real transitions.

**D.4 — Run full validation suite** (see Part 11).

---

### Phase E — Per-Evidence Readiness Cleanup
**Risk:** Medium — changes cold-start behavior  
**Acceptance:** Cold boot x5 each board, zero false WARNING/CRITICAL in first 60 seconds.

**E.1 — Apply readiness gates per Part 7**  
Implement per-evidence `ready` flag logic. Remove any remaining global
warmup-cap references from the candidate path. The legacy `assessThreat()`
comparison path may retain private warmup housekeeping until it is removed in
Phase G, but it must not influence candidate scoring or the real FSM.

**E.2 — Verify Phase B.5 ambient tagging is working correctly**  
By this phase, progressive ambient tagging (B.5) should have already eliminated the batch-reset problem. This phase verifies it holds under the candidate engine.

---

### Phase F — LR1121 2.4 GHz Off Critical Path
**Risk:** Low — scheduling change only  
**Acceptance:** LR1121 ADVISORY latency matches SX1262 within 2 seconds on the same JJ trace.

**F.1 — Split `cadFskScan()` into `cadSubGHzFskScan()` + `cad24Scan()`** (`src/cad_scanner.cpp`, `include/cad_scanner.h`)  
Sub-GHz scan returns immediately → ingest → assess → threat decision. 2.4 GHz scan runs on `LR24_CAD_PERIOD_MS` timer.

**F.2 — Wall-clock scheduling in `main.cpp`**  
Replace `cycleCount % RSSI_SWEEP_INTERVAL` with `millis() >= nextSubGHzSweepMs`. Add `nextLr24CadMs`, `nextLr24SweepMs` timers.

**F.3 — Verify LR1121 non-sweep cycle time ~= SX1262 (~1500ms)**

---

### Phase G — Diagnostics and Cleanup
**Risk:** Zero — additive  
**Acceptance:** Build clean with zero new warnings. Legacy scoring code gone.

**Status: COMPLETE — April 14, 2026**
Legacy `assessThreat()` removed. Candidate engine is now the sole decision
path for `currentThreat` and FSM transitions. `[CAND-DELTA]` logging removed.
`legacyThreat`, `lastThreatEventMs`, `cleanSinceMs`, `freshRssiThisCycle`, and
the `*ThisCycle` aggregate counters removed along with their populate shim
`detectionEngineIngestCad()` and the dead backward-compat wrappers
`detectionEngineSetCadFsk()` / `detectionEngineUpdate()`.

**G.1 — Expose candidate diagnostics to `SystemState`** ✅
Added `fastScore`, `confirmScore`, `anchorFreq`, `bandMask`, `hasCandidate`,
`candidateCount` to `SystemState`. Mirrored from `ThreatDecision` inside
`detectionEngineAssess()` via new accessors (`detectionEngineGetAnchorFreq()`,
etc). Shown on OLED threat screen as a `CAND:` line when a candidate is
active (replaces the `LAST: Xs ago` fallback line). Already logged via
`[CAND]` serial line.

**G.2 — Delete legacy code** ✅
Removed `assessThreat()` (173 lines), `legacyThreat`, `lastThreatEventMs`,
`cleanSinceMs`, `freshRssiThisCycle`, and the eight `*ThisCycle` aggregate
counters. Removed `detectionEngineIngestCad()`, `detectionEngineSetCadFsk()`,
`detectionEngineUpdate()`. Removed 20 legacy weight and threshold constants
from `sentry_config.h` (`WEIGHT_DIVERSITY_PER_FREQ` through
`WEIGHT_FAST_DETECT`, `SCORE_ADVISORY/WARNING/CRITICAL`,
`FAST_DETECT_MIN_*`, `FAST_ADVISORY_THRESH`, `FAST_WARNING_THRESH`,
`CONFIRM_WARNING_THRESH`, `CONFIRM_CRITICAL_THRESH`, `CONFIRM_ADVISORY_THRESH`,
`WEIGHT_FAST_PERSISTENT_DIV`, `WEIGHT_FAST_FHSS_VELOCITY`). Kept the five
`WEIGHT_CONFIRM_*` constants that the candidate engine actively consumes.
Kept `CadFskResult` — it's the live data-transfer struct between
`cadFskScan()` and the candidate engine, not a legacy artifact.

**G.3 — Fix version string** ✅
`include/version.h` — bumped `FW_VERSION` from `"1.6.0"` to `"1.9.0-rc1"`
with a phase-completion note.

**G.4 — Spec doc updated** ✅
Phase marker moved from `F` to `COMPLETE`, this section stamped with the
completion status.

---

## Part 11 — Acceptance Criteria

### Shadow-mode acceptance (Phase C → D gate)

All of the following must be true before cutting over:

| Scenario | Requirement |
|---|---|
| Clean bench, 10 min, all 3 boards | Zero WARNING/CRITICAL |
| Cold boot x5 each board | Zero false WARNING/CRITICAL in first 60s |
| JJ ELRS ADVISORY | ≤ 4 seconds |
| JJ ELRS WARNING | ≤ 10 seconds |
| JJ ELRS CRITICAL | Only when confirm evidence is attached to same candidate as fast evidence |
| LR1121 vs SX1262 on same JJ trace | ADVISORY within 2s wall-clock |
| Multiple unrelated evidence sources | Do NOT promote each other unless association rules pass |

The metric "better than legacy on >80% of cycles" is explicitly **not** an acceptance gate. One false CRITICAL in a 10-minute run fails the run.

### Final acceptance (Phase D complete)

| Metric | Target |
|---|---|
| SX1262 ADVISORY latency | ≤ 4 seconds |
| SX1262 WARNING latency | ≤ 10 seconds |
| LR1121 ADVISORY latency | ≤ 4 seconds (after Phase F) |
| FP: no drone, 30 min | Zero WARNING/CRITICAL |
| FP: dense LoRa bench | Zero WARNING/CRITICAL (candidate isolation) |
| Board parity | Within 2s wall-clock |
| Cold-boot false alerts | Zero in first 60 seconds |

### COM14 (LR1121) bench acceptance note

The LR1121's higher sensitivity detects persistent sub-GHz bench emitters
(observed at 902.3, 912.2, 914.7 MHz) that survive warmup ambient tagging.
These produce intermittent false ADVISORY in cold-boot captures, typically
at 40-60 seconds post-warmup. This is a test environment condition, not a
code defect. The SX1262 (COM9) passes 5/5 across all Phase E runs.

Phase E acceptance is declared on the basis of:

- 5/5 COM9 cold-boot PASS
- Zero false WARNING or CRITICAL on either board
- Correct `[CAND-DELTA] legacy=ADVISORY candidate=CLEAR` chronic-noise
  filter operation on COM14 throughout (candidate engine correctly
  suppresses the aggregate 2.4 GHz diversity the legacy scorer fires on)

LR1121 field validation (with appropriate antenna and no bench emitters)
is required before deployment. The bench emitters observed during Phase E
testing cannot be replicated in code — they are real RF sources that a
production deployment would not see, and any gate tight enough to block
them would also block real low-power FHSS signals.

---

## Part 12 — What Remains Outside This Redesign

These items are known but explicitly out of scope for v2.0:

- **Buzzer and LED alert methods** — GPIO 16 passive piezo (KY-006), LED system
- **GNSS jamming/spoofing host-side algorithms** — beyond the GNSS evidence term in this engine
- **LR1121 2.4 GHz image recalibration latency** — `setBandwidth(812.5, true)` triggers ~1250ms recal; investigate but not blocking
- **LR1121 RSSI sweep GFSK params** — board-specific calibration (freqDev, rxBw) needed vs SX1262 defaults
- **Heltec V4 node integration** — distributed sensing, after v2.0 stable
- **TESTKIT-GPS / AntSDR E200** — spoofing/jamming test signal generation
- **MemPalace** — ChromaDB + MCP cross-project memory system

---

## Part 13 — Known Active Issues (as of April 13, 2026)

| Issue | Severity | Resolution |
|---|---|---|
| GPS_MIN_CNO = 6 | 🔴 MUST FIX before field deployment | Raise to 15–20 |
| LR1121 bench FP on dense LoRa | 🟡 Known | Candidate isolation (Phase D) |
| Version string bug main.cpp:422 | 🟡 Minor | Phase G.3 |
| 2.4 GHz cycle slow (~3900ms) | 🟡 Known | Phase F (moves off critical path) |
| CC work unvalidated until flashed | ⚠️ Process | Hardware flash required before trusting any sprint |

---

## Part 14 — How We Work

| Role | Responsibility |
|---|---|
| **Claude** | Architecture decisions, sprint planning, CC prompt generation, pre-flash review |
| **Claude Code (CC)** | Code implementation, file editing, git operations |
| **ND** | Final decisions, all hardware interaction, serial capture, field testing |
| **Codex/ChatGPT** | Adversarial reviews at major milestones |

**CC work is not validated until flashed.** Commits after compile-only verification are treated as unproven. Hardware validation is mandatory before trusting any sprint output.

**Git:** Author `ND <ndywoo10@gmail.com>`. Always build all three targets before committing.

**Targets:** `t3s3`, `heltec_v3`, `t3s3_lr1121`

---

*This document is the single source of truth for SENTRY-RF Detection Engine v2.0.*  
*All prior planning documents are superseded.*  
*Last updated: April 13, 2026 — Claude + Codex + ND*

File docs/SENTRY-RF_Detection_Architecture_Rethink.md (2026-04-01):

# SENTRY-RF Detection Architecture Rethink
## The Right Discriminator for FHSS Drone Detection

**Date:** April 1, 2026  
**Status:** Architecture proposal for review before implementation

---

## The Problem We Keep Solving Wrong

Across Sprints 1A through 2B-fix, we've iterated through dozens of threshold combinations trying to distinguish drone LoRa signals from ambient LoRa infrastructure on a busy bench. Every approach follows the same pattern:

1. Find a metric (hit count, persistence, rolling buffer, live taps)
2. Set a threshold that catches drones
3. Discover that ambient LoRa also exceeds the threshold
4. Add another filter or raise the threshold
5. Discovery that drones now fall below the threshold
6. Repeat

**This cycle will never end because we're measuring the wrong feature.**

All our metrics count *how many* detections occur. But both drones and infrastructure produce LoRa CAD hits — the *count* overlaps. What distinguishes them is *where* those hits occur across the frequency band.

---

## The Key Insight: Frequency Spread

A drone FHSS link (ELRS 200 Hz, 80 channels) produces CAD hits scattered across **dozens of distinct frequencies** within any 5-second window. A LoRaWAN gateway produces CAD hits on **2-3 fixed frequencies**. A Meshtastic node produces hits on **1 frequency**.

The discriminator isn't how many hits — it's **how many DISTINCT frequencies** produced hits within a time window.

| Source | Hits in 5s | Distinct frequencies | Spread pattern |
|---|---|---|---|
| ELRS drone (200 Hz, 80ch) | 3-8 | 3-8 different | Scattered across 902-928 MHz |
| LoRaWAN gateway (8ch, 1/15s) | 0-2 | 1-2 fixed | Clustered on fixed channels |
| Meshtastic node | 0-1 | 1 fixed | Single frequency |
| 3 ambient sources combined | 1-4 | 2-4 fixed | Few distinct, repeating |

**A drone with 3 CAD hits on 3 different frequencies is fundamentally different from infrastructure with 3 CAD hits on 1-2 frequencies, even though the hit count is identical.**

---

## Proposed Architecture: Frequency Diversity Scoring

Replace the current `recentHitCount` (total hits in 30s) with a **frequency diversity score** that counts distinct frequencies with CAD hits in a sliding window.

### Data Structure

```
FrequencySlot {
    float frequency;      // Center frequency of the hit
    uint8_t sf;           // Spreading factor
    unsigned long lastHitMs;  // When this frequency was last hit
    bool active;          // Is this slot occupied?
}

FrequencyDiversityTracker {
    FrequencySlot slots[32];  // Track up to 32 distinct frequencies
    int slotCount;            // Number of active slots
    
    void recordHit(float freq, uint8_t sf);  // Add/update a slot
    int countActiveFrequencies(unsigned long windowMs);  // Count distinct freqs hit within window
    void prune(unsigned long maxAge);  // Remove expired slots
}
```

### Recording Logic

When a non-ambient CAD hit occurs at frequency F:
1. Check if F is already in the tracker (within ±200 kHz)
2. If yes: update `lastHitMs` (same frequency hit again — doesn't increase diversity)
3. If no: add a new slot (new frequency — increases diversity)

### Threat Assessment

```
diversityCount = tracker.countActiveFrequencies(5000);  // Distinct freqs in last 5s

// FHSS signature: hits on 3+ distinct frequencies in 5 seconds
// Infrastructure: hits on 1-2 frequencies (gateway channels repeat)
if (diversityCount >= 4) → CRITICAL (definitive FHSS pattern)
if (diversityCount >= 2) → WARNING (possible FHSS, strong evidence)
if (diversityCount >= 1) → ADVISORY (single CAD hit, monitoring)
if (diversityCount == 0) → use RSSI-only path (existing logic)
```

### Why This Works Against Ambient LoRa

- **LoRaWAN gateway on 8 channels, transmitting 1/15s per channel:** In any 5-second window, produces 0-2 CAD hits on 0-2 frequencies. `diversityCount` stays at 0-2. Never reaches 3.
- **Meshtastic node on 1 channel:** Produces hits on 1 frequency. `diversityCount` = 1 max. ADVISORY only.
- **3 ambient sources combined:** Produces hits on 3-4 distinct frequencies, BUT those frequencies are the same every time. Over 5 seconds, `diversityCount` = 3-4. This COULD trigger WARNING.

**The ambient protection:** The ambient warmup filter already tags known ambient frequencies. The diversity tracker should **exclude ambient-tagged frequencies** from the diversity count. If 3 of 4 distinct frequencies are ambient-tagged, `diversityCount` = 1, not 4.

- **ELRS drone (200 Hz, 80 channels):** CAD hits scattered across many frequencies. Even with 0.3% per-channel catch rate, in 5 seconds (5 cycles × 121 channels = 605 CAD checks), expected distinct frequency hits = ~1.8 per cycle. Over 5 cycles: `diversityCount` = 5-10 distinct frequencies. Easily clears the threshold.

### The 5-Second Window

Why 5 seconds, not 30? Because FHSS is a *fast* phenomenon. A drone hops to a new channel every 5-7ms. Within 5 seconds, it has visited every channel dozens of times. Infrastructure signals don't gain diversity over time — a gateway on 8 channels has 8 distinct frequencies whether you measure over 5 seconds or 5 minutes. The short window prevents ambient accumulation while still capturing the FHSS spread pattern.

---

## What Changes vs Current Architecture

| Component | Current | Proposed |
|---|---|---|
| Primary discriminator | recentHitCount (total hits in 30s) | diversityCount (distinct frequencies in 5s) |
| mediumConfidence | rssiPersistentUS AND recentHits OR bandEnergy | diversityCount >= 2 |
| highConfidence | rssiPersistentUS AND recentHits >= 3 OR confirmed taps | diversityCount >= 4 |
| RSSI role | Required for WARNING/CRITICAL corroboration | Optional — diversity alone is sufficient for WARNING |
| Ambient protection | Ambient taps excluded from hit count | Ambient frequencies excluded from diversity count |
| Time window | 30 seconds (ambient accumulates) | 5 seconds (ambient doesn't accumulate) |
| False alarm on LoRa-rich bench | Likely after 60s+ (ambient hits accumulate) | Unlikely (ambient diversity stays low after warmup) |

### What Stays the Same

- CAD fishing-pole scan engine (cadFskScan, tap tracking, persistence)
- RSSI sweep and peak extraction
- Ambient warmup filter and auto-learning
- WiFi Remote ID scanner
- GNSS integrity monitoring
- Rapid-clear path
- Centralized sentry_config.h
- Radio mode switching (SPI opcode 0x8A)

### What Gets Replaced

- `recentHitTimestamps[]` ring buffer → `FrequencyDiversityTracker`
- `recentHitCount` field in CadFskResult → `diversityCount` field
- `assessThreat()` confidence logic → diversity-based thresholds
- Standalone `rssiPersistentUS` as WARNING trigger → diversity handles WARNING independently

---

## RSSI's New Role

RSSI persistence stops being a WARNING gate and becomes a **CRITICAL accelerator**:

- diversityCount >= 2 alone → WARNING (CAD-only, fast)
- diversityCount >= 4 alone → CRITICAL (strong FHSS evidence)
- diversityCount >= 2 AND rssiPersistentUS → CRITICAL (two sensors agree, faster)
- rssiPersistentUS alone → ADVISORY (energy detected but unconfirmed modulation)

This means WARNING can be achieved with CAD alone (no RSSI sweep needed), which is the fast path. RSSI adds confidence for faster CRITICAL escalation but isn't required.

---

## Expected Performance

**WARNING time:** The diversity tracker sees its first distinct-frequency hit within 1-2 CAD cycles (~1-2s). The second distinct frequency hit within the next 1-2 cycles. `diversityCount >= 2` at ~2-4 seconds.

**CRITICAL time:** `diversityCount >= 4` requires 4 distinct frequencies in 5 seconds. At ~1.8 hits per cycle across distinct frequencies, this is reached in ~3-4 cycles = ~3-4 seconds for diversity-only CRITICAL. With RSSI corroboration, possibly faster.

**Baseline:** Ambient LoRa with warmup filter produces 0-2 non-ambient distinct frequencies in any 5-second window. The 5-second window prevents accumulation. ADVISORY max.

**Rapid-clear:** When drone leaves, diversity count drops to 0 within 5 seconds (the window). Rapid-clear fires within 4 clean cycles after that. Total: ~9 seconds from drone departure to CLEAR.

---

## Risk Assessment

**Risk 1: Ambient produces 3+ distinct non-ambient frequencies in 5 seconds.**
Mitigation: Increase threshold to 4 for WARNING. Or extend the warmup to catch more ambient frequencies. This is testable on the bench.

**Risk 2: Drone at long range produces only 1-2 distinct frequency hits in 5 seconds.**
Mitigation: Keep the RSSI persistence path as a backup — diversityCount >= 1 AND rssiPersistentUS → WARNING. The diversity path is the fast path; RSSI is the long-range backup.

**Risk 3: Multiple drones on different protocols look like one high-diversity source.**
This is actually fine — multiple drones IS a higher threat and should escalate faster.

---

## Implementation Plan

This is a single focused sprint. The changes are in 3 files:

1. **cad_scanner.cpp:** Replace `recentHitTimestamps[]` with `FrequencyDiversityTracker`. Record non-ambient CAD hits as frequency slots. Expose `diversityCount` in CadFskResult.

2. **detection_engine.cpp:** Rewrite `assessThreat()` confidence logic to use `diversityCount` instead of `recentHitCount`. Remove the tangled web of conditions that accumulated across 6 sprints.

3. **sentry_config.h:** Add diversity thresholds: `DIVERSITY_WINDOW_MS = 5000`, `DIVERSITY_WARNING = 2`, `DIVERSITY_CRITICAL = 4`.

**Estimated effort:** 1 sprint (CC session), ~30 minutes of coding + testing.

**What this eliminates:** The entire mediumConfidence/highConfidence condition maze that's been the source of every regression. Instead of 6+ boolean conditions ORed together, the threat assessment becomes a simple numeric comparison on a single metric that directly measures the FHSS signature.

---

*The fishing pole catches fish. The problem was never the fishing pole — it was that we were counting fish instead of counting how many different spots in the lake had fish. FHSS means "frequency hopping" — the hopping IS the signature.*

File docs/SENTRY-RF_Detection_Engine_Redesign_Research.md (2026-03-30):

# SENTRY-RF Detection Engine Redesign: Research & Specification Document

## Executive Summary

This document provides the technical foundation for redesigning SENTRY-RF's sub-GHz detection engine from an RSSI energy-based system to a **modulation-aware matched detection** architecture. The core change: use the SX1262's built-in Channel Activity Detection (CAD) as the primary LoRa drone detector, FSK packet detection for FSK-based drone protocols, and retain RSSI energy scanning for spectrum awareness and unknown protocol anomaly detection.

### Why This Redesign Is Necessary

The current RSSI-only detection engine cannot distinguish between LTE cell tower band-edge energy and drone control signals in the 869–886 MHz overlap zone. After 10+ iterations of statistical and behavioral filtering (ambient baseline, spectral width, frequency diversity, protocol novelty), none achieved zero false positives without also suppressing real drone detection. The fundamental problem: **RSSI energy detection has no knowledge of signal modulation — it treats all RF energy identically regardless of source.**

### The Solution

The SX1262 hardware contains a **correlation-based LoRa detector (CAD)** that identifies LoRa chirp spread spectrum modulation patterns. LTE OFDM, GSM, power line noise, and other non-LoRa interference will never trigger CAD because they use fundamentally different modulation. Similarly, the SX1262's FSK receive mode can detect FSK-modulated packets that match specific baud rate and deviation parameters. Together, these modulation-aware detectors provide high-confidence drone classification that energy detection cannot achieve.

---

## Part 1: Protocols in the 860–930 MHz Band

### 1.1 Drone Control Protocols (Detection Targets)

#### ExpressLRS (ELRS) 900 MHz
- **Frequency bands:** 868 MHz (EU, 50 channels, 860–886 MHz) and 915 MHz (US/FCC, 80 channels, 902–928 MHz)
- **Modulation (SX127x hardware):** LoRa at ALL packet rates (50 Hz, 100 Hz, 150 Hz, 200 Hz). Uses SF6–SF12 with BW500.
  - 200 Hz: SF6 BW500 (sensitivity -108 dBm)
  - 150 Hz: SF7 BW500 (sensitivity -112 dBm)  
  - 100 Hz: SF8 BW500 (sensitivity -115 dBm)
  - 50 Hz: SF9 BW500 (sensitivity -120 dBm)
  - 25 Hz: SF10 BW500 (sensitivity -123 dBm)
  - D50 Hz: SF12 BW500 redundant transmit mode (sensitivity -128 dBm)
- **Modulation (LR1121 hardware):** FSK at high packet rates (K1000, K500). LoRa at lower rates. FSK uses custom parameters.
- **Frequency hopping:** FHSS with pseudo-random sequence seeded by bind phrase
- **Hop rate:** Equal to packet rate (e.g., 200 Hz = 200 hops/sec, 5 ms per channel)
- **Packet size:** 8 bytes payload, very short air time
- **Channel spacing:** ~520 kHz (868 EU), ~325 kHz (915 US)
- **TX power:** Configurable, 10 mW to 1 W typical

**CAD detection strategy:** CAD at SF6/BW500 catches 200 Hz mode (most common for FPV). CAD at SF7/BW500 catches 150 Hz. CAD at SF9/BW500 catches 50 Hz (long range). Prioritize SF6/BW500 and SF7/BW500 as these are the most commonly used modes.

#### TBS Crossfire
- **Frequency band:** 868 MHz (EU) and 915 MHz (US), 100 channels, 260 kHz spacing
- **Modulation:**
  - 50 Hz mode: **LoRa** (SF6 BW500) — detectable by CAD
  - 4 Hz mode: **LoRa** (higher SF, long range) — detectable by CAD
  - 150 Hz mode: **FSK** at 85.1 kbaud — NOT detectable by CAD, requires FSK packet detection
- **Hop rate:** 150 channels/sec at 150 Hz mode
- **TX power:** Up to 2 W (33 dBm)
- **Encryption:** Yes, Crossfire is the only hobby RC protocol with data encryption

**Detection strategy:** CAD catches 50 Hz and 4 Hz LoRa modes. FSK packet detection at 85.1 kbaud catches 150 Hz mode.

#### mLRS
- **Frequency band:** 868/915 MHz and 433 MHz
- **Modulation:** LoRa at all packet rates (19 Hz, 31 Hz, 50 Hz)
  - 19 Hz: SF11 BW500 (SX127x compatibility mode)
  - 31 Hz: SF7 BW500 (SX126x mode, higher performance)
  - 50 Hz: SF6 BW500
- **Hardware:** STM32 + SX1262/SX127x based

**Detection strategy:** CAD at SF6/BW500 and SF7/BW500 catches most modes. SF11/BW500 for 19 Hz mode if needed.

#### FrSky R9 System
- **Frequency band:** 868/915 MHz
- **Modulation:** **FSK only** — no LoRa modulation used
- **Baud rate:** Proprietary FSK parameters (approximately 50 kbaud)
- **TX power:** Up to 1 W

**Detection strategy:** FSK packet detection only. CAD will NOT detect FrSky R9. RSSI energy detection is the fallback. In the 902–928 MHz US band, there is no cell tower overlap, so RSSI-based detection works without the false positive problem.

#### ImmersionRC Ghost
- **Frequency band:** 2.4 GHz only
- **Not relevant to sub-GHz detection** — handled by 2.4 GHz scanner (LR1121 / WiFi)

#### TBS Tracer
- **Frequency band:** 2.4 GHz only
- **Not relevant to sub-GHz detection** — handled by 2.4 GHz scanner (LR1121 / WiFi)

### 1.2 Non-Drone LoRa Signals (Must NOT Trigger Drone Alerts)

#### LoRaWAN (IoT sensors, smart meters)
- **Modulation:** LoRa at SF7–SF12, **BW125** (not BW500)
- **US channels:** 903.9, 904.1, 904.3, 904.5, 904.7, 904.9, 905.1, 905.3 MHz (8 uplink), 904.6 MHz (downlink)
- **EU channels:** 868.1, 868.3, 868.5 MHz (3 uplink)
- **Duty cycle:** Very low — transmits briefly then silent for seconds/minutes
- **CAD differentiation:** LoRaWAN uses BW125. Drone protocols use BW500. **CAD configured for BW500 will NOT trigger on BW125 LoRaWAN signals.** The chirp bandwidth mismatch causes correlation failure.

#### Meshtastic
- **Modulation:** LoRa, configurable SF and BW
- **Common settings:** LongFast = SF11 BW250, MediumSlow = SF11 BW500, ShortFast = SF7 BW250
- **CAD differentiation:** Most Meshtastic presets use BW250, not BW500. CAD at BW500 won't trigger on BW250 signals. Exception: MediumSlow (SF11 BW500) would match a CAD scan at SF11/BW500 — but we don't need to CAD at SF11 for drone detection since no drone protocol uses SF11/BW500.

#### Reticulum
- **Modulation:** LoRa, typically SF7–SF10 at BW125 or BW250
- **CAD differentiation:** BW125/BW250 won't trigger CAD at BW500.

### 1.3 Interference Sources (Must Be Rejected)

#### LTE Cell Towers (Band 5, Band 8)
- **US Band 5 downlink:** 869–894 MHz (25 MHz wide)
- **EU Band 8 downlink:** 925–960 MHz (partial overlap at top of scan range)
- **Modulation:** OFDM (Orthogonal Frequency Division Multiplexing)
- **Bandwidth:** 10 MHz or 20 MHz per carrier
- **CAD rejection:** OFDM is not LoRa chirp spread spectrum. CAD will ALWAYS return "channel clear" for LTE signals regardless of signal strength. This is the definitive solution to the cell tower false positive problem.

#### Power Lines / Distribution Stations
- **Characteristics:** Broadband electromagnetic interference, harmonics of 50/60 Hz
- **Spectrum signature:** Wideband energy spread across many MHz, no narrowband structure
- **Rejection:** Spectral width classifier (existing) + CAD returns "clear" (no LoRa modulation)

#### Other ISM Devices (garage doors, weather stations, industrial sensors)
- **Modulation:** Typically OOK (On-Off Keying) or simple FSK at low baud rates
- **CAD rejection:** OOK is not LoRa. Simple FSK at non-matching baud rates won't decode as drone FSK.

---

## Part 2: SX1262 CAD Technical Specification

### 2.1 How CAD Works

Channel Activity Detection performs a correlation operation on received samples, looking for LoRa chirp preamble patterns (and on SX1262, the full packet). The CAD operation:

1. Radio is configured with target frequency, SF, and BW
2. Radio enters CAD mode via `SetCad()` command
3. Radio listens for one symbol period (T_symbol + 32/BW milliseconds)
4. Hardware correlator compares received samples against ideal LoRa preamble waveform
5. CadDone interrupt fires, CadDetected flag indicates result

### 2.2 CAD Timing

| SF | BW (kHz) | Symbol Time (ms) | CAD Time (ms) | Notes |
|----|---|---|---|---|
| SF6 | 500 | 0.128 | ~0.19 | Fastest, catches ELRS 200Hz / CRSF 50Hz |
| SF7 | 500 | 0.256 | ~0.32 | Catches ELRS 150Hz |
| SF8 | 500 | 0.512 | ~0.58 | Catches ELRS 100Hz |
| SF9 | 500 | 1.024 | ~1.09 | Catches ELRS 50Hz long-range |
| SF7 | 125 | 1.024 | ~1.28 | Would catch LoRaWAN — DO NOT USE for drone detection |

### 2.3 CAD Parameters on SX1262

RadioLib exposes CAD via:
```cpp
int16_t state = radio.startChannelScan();  // Non-blocking CAD start
// ... wait for interrupt or poll ...
int16_t result = radio.getChannelScanResult();  // Returns RADIOLIB_LORA_DETECTED or RADIOLIB_CHANNEL_FREE

// Or blocking version:
int16_t result = radio.scanChannel();  // Blocks until CAD completes
```

CAD configuration parameters (SetCadParams):
- `cadSymbolNum`: Number of symbols for CAD detection (1, 2, 4, 8, 16). More symbols = higher Pd but longer time.
- `cadDetPeak`: Peak detection threshold. Higher = fewer false positives but lower Pd.
- `cadDetMin`: Minimum detection threshold.
- `cadExitMode`: What to do after CAD — return to standby or enter RX.

Recommended starting parameters for drone detection:
- `cadSymbolNum = LORA_CAD_02_SYMBOL` (2 symbols — fast, sufficient for strong drone signals)
- `cadDetPeak = SF + 13` (Semtech recommended default)
- `cadDetMin = 10` (Semtech recommended default)

### 2.4 CAD Probability of Detection (Pd) and False Alarm (Pfa)

From Semtech AN1200.48 and academic literature:
- At SNR > 0 dB: Pd > 99%, Pfa < 1%
- At SNR = -5 dB: Pd > 95%, Pfa < 1% (LoRa can decode below noise floor)
- At SNR = -10 dB: Pd drops to ~80%, Pfa < 1%
- Pfa for non-LoRa signals (LTE, FSK, noise): effectively 0% — the correlation never matches

### 2.5 CAD Limitations

- **SF and BW must match the target signal.** CAD at SF6/BW500 will NOT detect a signal at SF7/BW500 or SF6/BW125. This is both a limitation and an advantage — it provides built-in protocol discrimination.
- **CAD detects LoRa modulation, not specific protocols.** It cannot tell ELRS from Meshtastic if both use the same SF/BW. Differentiation comes from the SF/BW combination chosen for CAD.
- **CAD takes time.** Each CAD operation takes ~0.2 to ~1.1 ms depending on SF. Scanning many channels and multiple SF values multiplies this.
- **CAD requires the signal to be present during the CAD window.** For FHSS signals, the drone must be transmitting on the scanned channel at the exact moment CAD runs. Probability of catching a single hop is low, but scanning multiple channels per sweep cycle increases cumulative Pd.

---

## Part 3: FSK Packet Detection for Non-LoRa Drone Protocols

### 3.1 Crossfire FSK Mode (150 Hz)

- **Baud rate:** 85.1 kbaud
- **Modulation:** GFSK
- **Deviation:** ~25 kHz (estimated from channel spacing)
- **Channel spacing:** 260 kHz
- **Preamble:** Standard GFSK preamble (0xAA pattern)

The SX1262 can be configured in FSK receive mode with matching baud rate and deviation. If a valid preamble is detected, the chip generates an interrupt. This provides confirmation that a real FSK packet is present, not just energy.

RadioLib FSK receive:
```cpp
radio.beginFSK(freq, 85.1, 25.0, 234.3, 10, 16);
radio.setFrequency(target_freq);
radio.startReceive();
// Wait briefly (1-2 ms)
// Check for preamble detection via interrupt or RSSI
```

### 3.2 FrSky R9 FSK Mode

- **Baud rate:** ~50 kbaud (proprietary, approximate)
- **Modulation:** FSK
- **Lower confidence detection** — exact parameters are proprietary. RSSI energy detection in the 902–928 MHz band (no cell tower overlap in US) is the primary detection method.

---

## Part 4: Redesigned Detection Architecture

### 4.1 Detection Layers (Priority Order)

**Layer 1 — LoRa CAD Scan (PRIMARY for LoRa drone protocols)**
- Scan 10–20 rotating channels per sweep cycle at known ELRS/Crossfire frequencies
- CAD at SF6/BW500 (catches ELRS 200 Hz, Crossfire 50 Hz, mLRS 50 Hz)
- CAD at SF7/BW500 (catches ELRS 150 Hz, mLRS 31 Hz)
- Optional: CAD at SF9/BW500 (catches ELRS 50 Hz long-range mode)
- Time cost: ~4–8 ms per sweep cycle (20 channels × 2 SF settings × ~0.2 ms)
- **CAD detection = HIGH CONFIDENCE drone C2**
- Inherently rejects: LTE, LoRaWAN (BW125), Meshtastic (BW250), power lines, all non-LoRa signals

**Layer 2 — FSK Packet Detection (for FSK drone protocols)**
- Listen on 2–4 Crossfire FSK channels at 85.1 kbaud
- Brief dwell per channel (~2–5 ms) looking for preamble detection
- Time cost: ~10–20 ms per sweep cycle
- **FSK preamble detection = HIGH CONFIDENCE drone C2**
- Inherently rejects: LTE (OFDM, not FSK), LoRa signals, noise

**Layer 3 — RSSI Energy Sweep (spectrum awareness + unknown protocols)**
- Existing 860–930 MHz sweep with strongest-peak selection
- Provides spectrum visualization for operator situational awareness
- Catches energy from unknown/custom protocols that don't match any CAD or FSK signature
- **RSSI-only detection = LOW CONFIDENCE — ADVISORY only from sub-GHz alone**
- Exception: RSSI peaks in 902–928 MHz (no cell tower overlap in US) with protocol match and persistence = MEDIUM CONFIDENCE → can escalate to WARNING

**Layer 4 — WiFi Remote ID (independent, packet-level)**
- ASTM F3411 vendor-specific IE parsing in promiscuous mode
- Runs continuously on Core 0
- **WiFi RID detection = HIGH CONFIDENCE — escalates independently**

**Layer 5 — GNSS Integrity Monitor (independent sensor)**
- u-blox M10 jamming/spoofing indicators
- Runs continuously on Core 0
- **GNSS anomaly correlated with any RF detection = escalates one tier**

### 4.2 Threat Escalation Rules

| Detection | Confidence | Max Threat (alone) | With Corroboration |
|---|---|---|---|
| CAD-confirmed LoRa at drone SF/BW | HIGH | CRITICAL | — |
| FSK packet detected at drone baud rate | HIGH | CRITICAL | — |
| WiFi Remote ID beacon | HIGH | CRITICAL | — |
| RSSI peak at 902–928 MHz + protocol match + persistence | MEDIUM | WARNING | CRITICAL with CAD/WiFi/GNSS |
| RSSI peak at 869–886 MHz without CAD confirmation | LOW | ADVISORY | WARNING with WiFi/GNSS |
| GNSS jamming/spoofing alone | MEDIUM | WARNING | CRITICAL with any RF detection |

### 4.3 FreeRTOS Task Integration

The CAD and FSK detection scans should be integrated into the existing LoRaScanTask on Core 1. The sweep cycle becomes:

```
LoRaScanTask cycle (~2.5 seconds):
  1. RSSI sweep 860–930 MHz [~2.4s] (existing, with strongest-peak selection)
  2. CAD scan: 20 channels × SF6/BW500 [~4 ms]
  3. CAD scan: 10 channels × SF7/BW500 [~3 ms]  
  4. FSK listen: 4 channels × 85.1 kbaud [~16 ms]
  5. Process all results → feed detection engine
  Total added time: ~23 ms (< 1% of sweep cycle)
```

### 4.4 What Gets Removed

- Protocol novelty detection (AmbientProtocol, ambientProtosLocked, recordAmbientProto, isNovelProtocol, isNovelFrequency) — replaced by CAD modulation discrimination
- Frequency diversity tracking (uniqueBins, MIN_UNIQUE_BINS) — not needed with CAD
- Second-pass baseline — not needed with CAD
- **KEEP:** Ambient baseline lock (still useful for stable interference sources)
- **KEEP:** Spectral width classifier (still useful for broadband interference)
- **KEEP:** Warmup cap at ADVISORY (still useful for the first 10 sweeps)
- **KEEP:** Strongest-peak selection in extractPeaks (correct regardless of detection method)
- **KEEP:** Protocol tracker with per-protocol persistence (works alongside CAD results)

---

## Part 5: Implementation Notes for Claude Code

### 5.1 RadioLib CAD API

```cpp
// Configure LoRa mode for CAD
radio.begin(freq, BW, SF, CR, syncWord, outputPower, preambleLength);

// Or reconfigure on the fly:
radio.setSpreadingFactor(6);
radio.setBandwidth(500.0);
radio.setFrequency(915.0);

// Blocking CAD (simplest):
int16_t result = radio.scanChannel();
if (result == RADIOLIB_LORA_DETECTED) {
    // LoRa signal detected at this freq/SF/BW
} else if (result == RADIOLIB_CHANNEL_FREE) {
    // No LoRa signal (or non-LoRa interference)
}

// Non-blocking CAD (for integration with FreeRTOS):
radio.startChannelScan();
// ... do other work or wait for DIO1 interrupt ...
int16_t result = radio.getChannelScanResult();
```

### 5.2 Mode Switching

The SX1262 must switch between FSK mode (for RSSI sweeps) and LoRa mode (for CAD scans). This requires:
1. After RSSI sweep completes: switch to LoRa mode with `radio.begin()` or reconfigure
2. Set SF and BW for drone detection
3. Run CAD scans across target frequencies
4. Switch back to FSK mode for next sweep

Mode switching takes ~1–2 ms (PLL settling + calibration). This is acceptable given the 2.4s sweep cycle.

### 5.3 Channel Selection Strategy

Rather than CAD-scanning all 80 ELRS channels (which would take too long), scan a **rotating subset** each cycle:
- Divide 80 channels into 4 groups of 20
- Each sweep cycle, CAD-scan one group
- Full coverage every 4 cycles (~10 seconds)
- A drone hopping at 200 Hz hits each channel ~2.5 times per second — high probability of being present on at least one channel in any group of 20

### 5.4 CAD Result Integration with Detection Engine

Create a new data structure for CAD results:
```cpp
struct CadDetection {
    float frequency;
    uint8_t sf;
    float bw;
    unsigned long timestamp;
};
```

Feed CAD detections into the existing protocol tracker alongside RSSI peaks. CAD detections are pre-classified as HIGH CONFIDENCE — they bypass the ambient baseline, spectral width, and all other RSSI-based filters because the modulation match is definitive.

### 5.5 Testing with JUH-MAK-IN JAMMER

The JAMMER's ELRS FHSS mode transmits LoRa packets at SF6 BW500 with FHSS hopping — this is exactly what CAD at SF6/BW500 should detect. The JAMMER's CW mode transmits an unmodulated carrier — CAD should NOT detect this (it's not LoRa), which validates the modulation discrimination. The JAMMER's Crossfire FSK mode transmits FSK at 85.1 kbaud — the FSK packet detector should catch this.

Expected test results with the new architecture:
- CW (c): RSSI detects energy, CAD returns "clear" → ADVISORY (RSSI-only, 902–928 MHz, no cell tower overlap) or WARNING with persistence
- ELRS (e): RSSI detects energy AND CAD detects LoRa → CRITICAL
- Crossfire FSK (n): RSSI detects energy AND FSK detects packets → CRITICAL  
- Baseline (q): RSSI sees cell tower energy, CAD returns "clear" → ADVISORY max (RSSI-only in overlap zone)
- RID (r): WiFi scanner detects Remote ID → CRITICAL independently
- All WiFi modes: unaffected by sub-GHz changes

---

## Part 6: Distributed Sensor Network Considerations

### 6.1 One Device Per Soldier

When every soldier carries a SENTRY-RF unit, the system transitions from single-point detection to a **distributed sensor network**. Each node independently detects and can share detections via LoRa mesh.

### 6.2 Advantages of Distribution

- **Direction finding:** Two nodes with different RSSI readings from the same detection → bearing estimate
- **Triangulation:** Three+ nodes → position estimate of the drone/operator
- **Redundancy:** If one node fails or is jammed, others continue operating
- **Coverage:** Multiple nodes cover more spectrum more frequently
- **Validation:** A detection confirmed by multiple nodes has higher confidence than single-node detection

### 6.3 Future Architecture Implications

- Detection events should be structured as serializable messages (they already are: DetectionEvent struct)
- LoRa mesh networking (Meshtastic-style) could relay detections between nodes
- **Important:** SENTRY-RF's LoRa radio is shared between scanning and potential mesh communication — time-division between detection and relay needed
- The LR1121 board (Sprint 12) with separate sub-GHz and 2.4 GHz radios could dedicate one to detection and one to mesh relay

---

## References

1. Semtech SX1261/1262 Datasheet, Rev 1.2 (DS.SX1261-2.W.APP, June 2019)
2. Semtech AN1200.48 — "Introduction to Channel Activity Detection"
3. ExpressLRS source code: github.com/ExpressLRS/ExpressLRS
4. RadioLib SX126x API: jgromes.github.io/RadioLib/class_s_x126x.html
5. TBS Crossfire protocol documentation (community-sourced)
6. mLRS project: github.com/olliw42/mLRS
7. Garcia et al., "Implementation and Analysis of ExpressLRS Under Interference Using GNU Radio", GRCon 2025
8. Music et al., "Dense Deployment of LoRa Networks: Expectations and Limits of Channel Activity Detection", PMC 2021
9. CRFS drone detection technology: crfs.com/solutions/drone-detection
10. DHS Counter-UAS Technology Guide, February 2020
11. Drone Warfare counter-UAS RF detection guide: drone-warfare.com/counter-uas/rf-detection/

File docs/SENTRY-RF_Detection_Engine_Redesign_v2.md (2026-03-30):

# SENTRY-RF Detection Engine Redesign v2: Research & Specification Document

## Executive Summary

This document provides the technical foundation for redesigning SENTRY-RF's sub-GHz detection engine from an RSSI energy-based system to a **modulation-aware matched detection** architecture using a **scan-and-verify (fishing pole)** algorithm.

The core philosophy: cast as many lines as possible (scan every SF/BW combination drones use), note which lines get a bite (CAD hit), come back and verify (persistence check across multiple cycles), and only alert when the fish is confirmed real (persistent LoRa activity = drone, one-time hit = LoRaWAN or noise).

### Why This Redesign Is Necessary

The current RSSI-only detection engine cannot distinguish between LTE cell tower band-edge energy and drone control signals in the 869–886 MHz overlap zone. After 10+ iterations of statistical and behavioral filtering (ambient baseline, spectral width, frequency diversity, protocol novelty), none achieved zero false positives without also suppressing real drone detection. The fundamental problem: **RSSI energy detection has no knowledge of signal modulation — it treats all RF energy identically regardless of source.**

### The Solution

The SX1262 hardware contains a **correlation-based LoRa detector (CAD)** that identifies LoRa chirp spread spectrum modulation patterns. LTE OFDM, GSM, power line noise, and other non-LoRa interference will never trigger CAD because they use fundamentally different modulation. Similarly, the SX1262's FSK receive mode can detect FSK-modulated packets that match specific baud rate and deviation parameters. Together, these modulation-aware detectors provide high-confidence drone classification that energy detection cannot achieve.

### Key Design Principles

1. **Cast every line** — Scan ALL spreading factors drones use (SF6 through SF12 at BW500), not just the most common two. Three types of pilots exist: racers (high SF, fast rates), balanced/default (middle SF), and long-range (low rates, high SF). Miss any one group and you have a blind spot.

2. **Note the tap, verify the fish** — A single CAD hit is a "tap." It could be a drone, a LoRaWAN device, or a stray Meshtastic packet. Don't alert on one tap. Come back on the next cycle and check again. A drone transmitting 50–1000 packets per second will still be there. A LoRaWAN sensor that transmits once every 15 minutes will be gone.

3. **Persistence is the ultimate discriminator** — Drones are persistent (continuous C2 link). Everything else in the sub-GHz band is intermittent (LoRaWAN, Meshtastic, smart meters). If a CAD hit persists across 3+ scan cycles (~7–10 seconds), it's a drone. If it disappears, it wasn't.

4. **Adaptive priority** — When a tap is recorded, prioritize re-checking that frequency/SF on the next cycle. Don't wait for the rotation to come back around. This concentrates detection effort where signals were actually found, like pulling a fishing pole out of the water to inspect it closely.

---

## Part 1: Protocols in the 860–930 MHz Band

### 1.1 Drone Control Protocols (Detection Targets)

#### ExpressLRS (ELRS) 900 MHz

**The most common drone C2 protocol in the sub-GHz band.**

Frequency bands: 868 MHz (EU, 50 channels, 860–886 MHz) and 915 MHz (US/FCC, 80 channels, 902–928 MHz)

Pilot profiles and their typical settings:
- **Racing/freestyle pilots** (want responsiveness): 200–500 Hz packet rate → SF6/BW500
- **Balanced/set-and-forget pilots** (want reliability): 100–250 Hz → SF7/BW500 or SF8/BW500
- **Long-range pilots** (want maximum range): 25–50 Hz → SF9/BW500 to SF12/BW500

All ELRS 900 MHz modes on SX127x hardware:

| Packet Rate | Modulation | SF  | BW | Sensitivity | CAD Time/ch | Pilot Type |
|---|---|-----|---|---|---|---|
| 200 Hz | LoRa | SF6 | 500  | -108 dBm | ~0.19 ms | Racer |
| 150 Hz | LoRa | SF7 | 500  | -112 dBm | ~0.32 ms | Balanced |
| 100 Hz | LoRa | SF8 | 500  | -115 dBm | ~0.58 ms | Balanced |
| 50 Hz | LoRa | SF9 | 500  | -120 dBm | ~1.09 ms | Long range |
| 25 Hz | LoRa | SF10| 500  | -123 dBm | ~2.05 ms | Long range |
| D50 Hz | LoRa | SF12| 500  | -128 dBm | ~8.19 ms | Ultra LR |

On LR1121 hardware (newer):
| K1000       | FSK       | -   | -    | Custom      | N/A (FSK)   | Racer      |
| K500        | FSK       | -   | -    | Custom      | N/A (FSK)   | Racer      |

Frequency hopping: FHSS with pseudo-random sequence seeded by bind phrase. Hop rate equals packet rate (200 Hz = 200 hops/sec = 5 ms per channel). Channel spacing ~325 kHz (US) / ~520 kHz (EU). TX power configurable 10 mW to 1 W.

**CRITICAL: We must scan ALL six LoRa SF values to cover all pilot types. Scanning only SF6 and SF7 misses every long-range pilot.**

#### TBS Crossfire

Frequency band: 868 MHz (EU) and 915 MHz (US), 100 channels, 260 kHz spacing

| Mode | Modulation | Parameters | Detection Method |
|---|---|---|---|
| 50 Hz  | LoRa | SF6 BW500 | CAD at SF6/BW500 |
| 4 Hz | LoRa | ~SF12 BW500 | CAD at SF12/BW500|
| 150 Hz | FSK | 85.1 kbaud GFSK | FSK preamble detection |

TX power up to 2 W (33 dBm). Encrypted (only hobby RC protocol with encryption).

#### mLRS

Frequency band: 868/915 MHz and 433 MHz. All LoRa modulation.

| Mode  | SF | BW  | Detection Method |
|---|---|-----|---|
| 50 Hz | SF6  | 500 | CAD at SF6/BW500 |
| 31 Hz | SF7  | 500 | CAD at SF7/BW500 |
| 19 Hz | SF11 | 500 | CAD at SF11/BW500 |

#### FrSky R9 System

Frequency band: 868/915 MHz. FSK only, no LoRa. Baud rate ~50 kbaud (proprietary). CAD will NOT detect. Primary detection via RSSI energy in the 902–928 MHz US band (no cell tower overlap) or FSK listen at estimated baud rate.

#### ELRS on LR1121 (K modes)

FSK at high packet rates (K1000, K500). Custom FSK parameters. CAD will NOT detect. FSK listen at the appropriate baud rate is needed. These are newer and less common but represent the bleeding edge.

### 1.2 Non-Drone LoRa Signals (Rejected by Persistence, Not by CAD)

**Key insight: CAD alone cannot distinguish a Meshtastic packet from an ELRS packet if they use the same SF/BW. But PERSISTENCE can.** Drones transmit 50–1000 packets per second continuously. Everything below transmits occasionally and briefly.

#### LoRaWAN (IoT sensors, smart meters)
- SF7–SF12 at **BW125** (not BW500) — CAD at BW500 won't trigger on BW125
- US uplink channels: 903.9, 904.1, 904.3, 904.5, 904.7, 904.9, 905.1, 905.3 MHz
- EU uplink channels: 868.1, 868.3, 868.5 MHz
- **Transmission pattern:** Single packet, then silent for seconds to minutes. Duty cycle 0.1–1%.
- **Persistence filter eliminates:** Hit on cycle 1, gone on cycle 2 and 3 → cleared from tap list

#### Meshtastic
- Common presets: LongFast = SF11/BW250, MediumSlow = SF11/BW500, ShortFast = SF7/BW250
- **Risk case:** MediumSlow (SF11/BW500) would match our CAD scan at SF11/BW500
- **Persistence filter eliminates:** Meshtastic transmits a few packets per minute, not hundreds per second. A tap at SF11/BW500 that doesn't persist across 3 consecutive cycles = not a drone.
- **Acceptable edge case:** If a Meshtastic device happens to transmit during 3 consecutive scan cycles (very unlikely at typical message rates), it would briefly trigger ADVISORY. This is acceptable — a Meshtastic device producing LoRa energy at drone-typical cadence in a threat environment is worth noting anyway.

#### Reticulum
- Typically SF7–SF10 at BW125 or BW250 — BW mismatch rejects most configurations
- Low duty cycle — persistence filter handles the rest

### 1.3 Interference Sources (Rejected by CAD — Not LoRa Modulation)

#### LTE Cell Towers (Band 5, Band 8)
- US Band 5 downlink: 869–894 MHz (25 MHz wide)
- EU Band 8 downlink: 925–960 MHz
- **Modulation:** OFDM — CAD will ALWAYS return "channel clear." This is the definitive fix for the cell tower problem.

#### Power Lines / Distribution Stations
- Broadband electromagnetic interference, no modulation structure
- Spectral width classifier (existing) handles broadband. CAD returns "clear."

#### Other ISM Devices (garage doors, weather stations)
- Typically OOK or simple FSK at low baud rates
- CAD returns "clear." FSK detector at 85.1 kbaud won't match low-baud OOK.

---

## Part 2: SX1262 CAD Technical Specification

### 2.1 How CAD Works

Channel Activity Detection performs a hardware correlation on received samples, looking for LoRa chirp preamble patterns. On the SX1262, it can detect the full packet, not just the preamble.

1. Radio configured with target frequency, SF, and BW
2. Radio enters CAD mode
3. Radio listens for approximately one symbol period
4. Hardware correlator compares received samples against ideal LoRa chirp waveform
5. CadDone interrupt fires, CadDetected flag indicates presence/absence of LoRa signal

**Analogy:** RSSI is like checking if there's noise in a room. CAD is like checking if someone in the room is speaking Spanish. The room might be full of noise (cell tower energy), but CAD only fires if it hears the specific language (LoRa chirps) it's listening for.

### 2.2 CAD Timing Per SF (at BW500)

| SF  | Symbol Time (ms) | CAD Time (ms) | Channels/second | What It Catches |
|-----|---|---|---|---|
| SF6 | 0.128 | ~0.19 | ~5200 | ELRS 200Hz, CRSF 50Hz, mLRS 50Hz |
| SF7 | 0.256 | ~0.32 | ~3100 | ELRS 150Hz, mLRS 31Hz |
| SF8 | 0.512 | ~0.58 | ~1700 | ELRS 100Hz |
| SF9 | 1.024 | ~1.09 | ~920 | ELRS 50Hz |
| SF10| 2.048 | ~2.05 | ~490 | ELRS 25Hz |
| SF11| 4.096 | ~4.19 | ~240 | mLRS 19Hz (also catches Meshtastic MediumSlow) |
| SF12| 8.192 | ~8.19 | ~120 | ELRS D50 redundant, Crossfire 4Hz ultra LR |

### 2.3 Time Budget Analysis

Available time per scan cycle after RSSI sweep: ~100 ms is comfortable without impacting sweep cadence.

Proposed scan allocation per cycle:

| Phase | SF  | Channels | Time/ch | Total Time | Covers |
|---|-----|---|---|---|---|
| Fast scan | SF6 | 20 | 0.19 ms | 3.8 ms | Racers, most common |
| Fast scan | SF7 | 15 | 0.32 ms | 4.8 ms | Balanced pilots |
| Medium scan | SF8 | 10 | 0.58 ms | 5.8 ms | Balanced/conservative |
| Medium scan | SF9 | 8 | 1.09 ms | 8.7 ms | Long range |
| Slow scan | SF10 | 4 | 2.05 ms | 8.2 ms | Extreme long range |
| Slow scan | SF11 | 2 | 4.19 ms | 8.4 ms | mLRS 19Hz |
| Slow scan | SF12 | 2 | 8.19 ms | 16.4 ms | Ultra LR, CRSF 4Hz |
| FSK listen | - | 4 | 3.0 ms | 12.0 ms | Crossfire 150Hz FSK |
| **Total** | | **65** | | **~68 ms** | **All pilot types** |

68 ms per cycle is ~2.7% of a 2.5-second sweep cycle. Well within budget.

With rotation: 65 channels per cycle, rotating across the full channel plan. Full coverage of all 80 US channels × all 6 SF values = 480 combinations. At 65 checks per cycle, full coverage every ~7 cycles (~18 seconds). A drone hopping at even 25 Hz (slowest rate) transmits 450 packets in 18 seconds — extremely high probability of being caught during at least one scan.

### 2.4 RadioLib CAD API

```cpp
// Configure LoRa mode for CAD
radio.begin(freq, BW, SF, CR, syncWord, outputPower, preambleLength);

// Reconfigure on the fly (faster than full begin()):
radio.setSpreadingFactor(6);
radio.setBandwidth(500.0);
radio.setFrequency(915.0);

// Blocking CAD (simplest, used for initial implementation):
int16_t result = radio.scanChannel();
if (result == RADIOLIB_LORA_DETECTED) {
    // LoRa chirp pattern detected at this freq/SF/BW
} else if (result == RADIOLIB_CHANNEL_FREE) {
    // No LoRa signal (or non-LoRa interference — cell towers end up here)
}
```

### 2.5 CAD Detection Performance

From Semtech AN1200.48 and academic literature:
- At SNR > 0 dB: Pd > 99%, Pfa < 1%
- At SNR = -5 dB: Pd > 95%, Pfa < 1%
- At SNR = -10 dB: Pd drops to ~80%, Pfa < 1%
- Pfa for non-LoRa signals (LTE, FSK, noise): effectively 0%

---

## Part 3: The Fishing Pole Algorithm (Scan-and-Verify)

### 3.1 Concept

Imagine 12 fishing poles in a lake. Each pole is tuned for a different fish (SF/BW combination). You continuously walk along checking each pole for a bite. When you feel a tap on pole 3 and pole 7, you note it but keep checking all 12. On your next pass, you go back to pole 3 and 7 first. If pole 3 still has tension — there's a fish. Pull it out, inspect it, confirm it's real. If pole 7 has nothing — false hit. Clear it and move on.

### 3.2 Data Structures

```cpp
// A "tap" — one CAD detection on one frequency/SF
struct CadTap {
    float frequency;
    uint8_t sf;
    uint8_t consecutiveHits;    // How many cycles in a row this tap was seen
    uint8_t missCount;          // How many cycles since last hit
    unsigned long firstSeenMs;
    unsigned long lastSeenMs;
    bool active;
};

static const int MAX_TAPS = 32;  // Track up to 32 simultaneous taps
static CadTap tapList[MAX_TAPS];
```

### 3.3 Algorithm Per Scan Cycle

```
PHASE 1 — PRIORITY RE-CHECK (verify existing taps)
  For each active tap in tapList:
    Run CAD at that tap's frequency and SF
    If detected: tap.consecutiveHits++, tap.missCount = 0
    If not detected: tap.missCount++
    If tap.consecutiveHits >= 3: → CONFIRMED DRONE → HIGH CONFIDENCE
    If tap.missCount >= 3: → deactivate tap (was LoRaWAN/transient)

PHASE 2 — BROAD SCAN (cast all lines)
  For each SF in [6, 7, 8, 9, 10, 11, 12]:
    For each channel in the current rotation group for this SF:
      Run CAD
      If detected AND not already in tapList:
        Add to tapList with consecutiveHits=1, missCount=0

PHASE 3 — FSK SCAN
  For each Crossfire FSK channel in the current rotation:
    Switch to FSK mode, listen for 3 ms
    If RSSI > -80 dBm: → FSK tap (same tap-and-verify logic)

PHASE 4 — RESTORE
  Switch back to FSK scan mode for next RSSI sweep
```

### 3.4 Why This Handles Every Signal Type

| Signal Source | CAD Hit? | Persists? | Result |
|---|---|---|---|
| ELRS drone (any SF) | YES | YES (continuous TX) | Tap → verify → CONFIRMED → CRITICAL |
| Crossfire LoRa (50Hz) | YES | YES (continuous TX) | Tap → verify → CONFIRMED → CRITICAL |
| Crossfire FSK (150Hz) | No (wrong modulation) | YES via FSK detect | FSK tap → verify → CONFIRMED → CRITICAL |
| FrSky R9 (FSK) | No | Detected via RSSI in US band | RSSI persistence → MEDIUM → WARNING |
| LoRaWAN sensor | YES (if BW500, rare) | NO (single packet) | Tap → miss → miss → cleared |
| Meshtastic | YES (if SF11/BW500) | NO (few packets/min) | Tap → miss → miss → cleared |
| LTE cell tower | NO (OFDM ≠ LoRa) | N/A | Never enters tap list |
| Power lines | NO (broadband noise) | N/A | Never enters tap list |
| WiFi router | NO (wrong band) | N/A | Not in sub-GHz scan |
| Unknown drone protocol | No | Detected via RSSI | RSSI anomaly → ADVISORY |

### 3.5 Adaptive Priority — Concentrate Effort Where Fish Are Biting

When a tap has 1-2 consecutive hits (promising but not yet confirmed), it gets **priority re-check** at the start of the next cycle — before the broad scan. This means:

- If a drone just appeared, it gets re-checked within one cycle (~2.5 seconds) instead of waiting for the rotation to come back to that channel/SF
- Re-checks are fast (single CAD operation, <1 ms for SF6) so they don't significantly impact the broad scan budget
- Once confirmed (3+ hits), the tap transitions to the detection engine as HIGH CONFIDENCE and gets emitted as a detection event. The tap stays in the list for continued monitoring but no longer needs priority re-check.

### 3.6 LoRaWAN Rejection In Detail

LoRaWAN presents two cases:

**Case 1: LoRaWAN at BW125 (99% of deployments)** — CAD at BW500 physically cannot detect BW125 signals. The chirp bandwidth mismatch causes correlation failure. These never enter the tap list at all. Zero additional filtering needed.

**Case 2: LoRaWAN at BW500 (rare, some DR4 configurations)** — CAD would detect these. But LoRaWAN duty cycle is 0.1–1%. A device transmitting one packet every 30 seconds produces a tap that appears once and then is absent for the next 12+ scan cycles. The persistence requirement (3 consecutive hits) eliminates this instantly. Even the chattiest LoRaWAN device (1% duty cycle at 1 Hz) would only be present for 10 ms out of every 1000 ms — the probability of hitting 3 consecutive 2.5-second scan cycles is effectively zero.

---

## Part 4: Full Detection Architecture

### 4.1 Detection Layers

**Layer 1 — LoRa CAD Scan with Tap-and-Verify (PRIMARY)**
- Scans ALL six SF values (6, 7, 8, 9, 10, 11, 12) at BW500
- Covers every ELRS packet rate, Crossfire LoRa, mLRS, and any LoRa-based drone protocol
- Uses the fishing pole algorithm: tap → verify → confirm
- 3 consecutive CAD hits at the same frequency/SF = CONFIRMED DRONE
- **CONFIRMED = HIGH CONFIDENCE → escalate to CRITICAL**
- Inherently rejects: LTE (not LoRa), power lines (not LoRa), WiFi (wrong band)
- Persistence rejects: LoRaWAN (not persistent), Meshtastic (not persistent)
- ~68 ms per scan cycle across 65 channels

**Layer 2 — FSK Packet Detection with Tap-and-Verify**
- Listens on rotating Crossfire FSK channels at 85.1 kbaud
- Also listens at ~50 kbaud for FrSky R9 (lower confidence — proprietary params)
- Same tap-and-verify logic as CAD: 3 consecutive FSK hits = confirmed
- **CONFIRMED = HIGH CONFIDENCE → escalate to CRITICAL**
- Inherently rejects: LTE (not FSK at 85.1k), LoRa (different modulation), noise
- ~12 ms per scan cycle across 4 channels

**Layer 3 — RSSI Energy Sweep (spectrum awareness + unknown protocols)**
- Existing 860–930 MHz sweep with strongest-peak selection (8 strongest peaks kept)
- Provides spectrum visualization on OLED display
- Catches energy from unknown/custom protocols that don't match any CAD or FSK signature
- **RSSI in 902–928 MHz (no cell tower overlap) with protocol match + persistence = MEDIUM CONFIDENCE → WARNING**
- **RSSI in 869–886 MHz (cell tower overlap) without CAD confirmation = LOW CONFIDENCE → ADVISORY max**
- Ambient baseline lock and spectral width classifier still active for RSSI layer

**Layer 4 — WiFi Remote ID (independent, packet-level)**
- ASTM F3411 vendor-specific IE parsing in promiscuous mode
- Runs continuously on Core 0, unaffected by sub-GHz changes
- **WiFi RID detection = HIGH CONFIDENCE → escalates independently**

**Layer 5 — GNSS Integrity Monitor (independent sensor)**
- u-blox M10 jamming/spoofing indicators (UBX-MON-RF, NAV-STATUS, NAV-SAT)
- Runs continuously on Core 0
- **GNSS anomaly correlated with any RF detection → escalates one tier**

### 4.2 Threat Escalation Rules

| Detection | Confidence | Max Threat (alone) | With Corroboration |
|---|---|---|---|
| CAD tap-and-verify confirmed (3+ consecutive) | HIGH | CRITICAL | — |
| FSK tap-and-verify confirmed (3+ consecutive) | HIGH | CRITICAL | — |
| WiFi Remote ID beacon | HIGH | CRITICAL | — |
| RSSI peak at 902–928 MHz + protocol match + persistence | MEDIUM | WARNING | CRITICAL with CAD/WiFi/GNSS |
| RSSI peak at 869–886 MHz without CAD confirmation | LOW | ADVISORY | WARNING with WiFi/GNSS |
| GNSS jamming/spoofing alone | MEDIUM | WARNING | CRITICAL with any RF detection |
| Single CAD tap (not yet verified) | PENDING | ADVISORY | Triggers priority re-check |

### 4.3 FreeRTOS Task Integration

```
LoRaScanTask cycle on Core 1 (~2.6 seconds total):

  1. RSSI sweep 860–930 MHz                           [~2400 ms]
     └─ strongest-peak selection, ambient baseline, spectral width

  2. Switch SX1262 from FSK to LoRa mode              [~2 ms]

  3. PRIORITY RE-CHECK active taps                     [~0.2-8 ms per tap]
     └─ Re-CAD each active tap at its frequency/SF
     └─ Update consecutiveHits or missCount

  4. BROAD CAD SCAN (all SF values, rotating channels) [~68 ms]
     └─ SF6:  20 channels    (~3.8 ms)
     └─ SF7:  15 channels    (~4.8 ms)
     └─ SF8:  10 channels    (~5.8 ms)
     └─ SF9:   8 channels    (~8.7 ms)
     └─ SF10:  4 channels    (~8.2 ms)
     └─ SF11:  2 channels    (~8.4 ms)
     └─ SF12:  2 channels    (~16.4 ms)
     └─ New taps added to tapList

  5. FSK SCAN (Crossfire channels, rotating)           [~12 ms]
     └─ 4 channels at 85.1 kbaud, 3ms dwell each

  6. Switch back to FSK scan mode                      [~2 ms]

  7. Feed results to detection engine                  [<1 ms]
     └─ cadDetections = count of CONFIRMED taps (3+ hits)
     └─ fskDetections = count of CONFIRMED FSK taps
     └─ RSSI peaks already processed in step 1

  Total added time: ~85 ms (~3.4% of sweep cycle)
```

### 4.4 What Gets Removed from Current Codebase

- Protocol novelty detection (AmbientProtocol, ambientProtos, ambientProtosLocked, recordAmbientProto, isNovelProtocol, isNovelFrequency)
- Frequency diversity tracking (uniqueBins, MIN_UNIQUE_BINS)
- Second-pass baseline
- isNearBaselineBin

### 4.5 What Gets Kept

- **Strongest-peak selection in extractPeaks** — correct regardless of detection method
- **Ambient baseline lock** — still useful for RSSI layer stable interference filtering
- **Spectral width classifier** — still useful for broadband RSSI interference
- **Warmup cap at ADVISORY** — first 10 sweeps while ambient baseline populates
- **Per-frequency persistence tracker** — feeds MEDIUM confidence RSSI detections
- **Per-protocol persistence tracker** — feeds MEDIUM confidence RSSI detections
- **WiFi Remote ID scanner** — unchanged, independent layer
- **GNSS integrity monitor** — unchanged, independent layer

---

## Part 5: Implementation Notes for Claude Code

### 5.1 New Files

```
include/cad_scanner.h    — CadTap struct, CadFskResult struct, function declarations
src/cad_scanner.cpp      — Fishing pole algorithm implementation
```

### 5.2 Modified Files

```
src/detection_engine.cpp — Remove novelty system, add confidence-based assessThreat()
include/detection_engine.h — Add detectionEngineSetCadFsk() declaration
src/main.cpp             — Call cadFskScan() after RSSI sweep in loRaScanTask
```

### 5.3 Key Implementation Details

**Mode switching:** The SX1262 switches between FSK (RSSI sweep) and LoRa (CAD scan) each cycle. Mode switch takes ~2 ms. When doing CAD at multiple SF values, use `radio.setSpreadingFactor()` between groups rather than full `radio.begin()` — it's faster because it doesn't reinitialize the full radio.

**Channel rotation:** Each SF has its own rotation counter. SF6 scans 20 of 80 US channels per cycle (full coverage in 4 cycles). SF12 scans 2 of 80 per cycle (full coverage in 40 cycles, but SF12 drones transmit slowly so this is acceptable). EU 868 channels are included in the rotation for each SF.

**Tap list management:**
- New tap: frequency rounded to nearest 100 kHz, SF recorded, consecutiveHits=1
- Match existing tap: frequency within ±200 kHz AND same SF → increment consecutiveHits
- Miss: an active tap not re-detected this cycle → increment missCount
- Confirm: consecutiveHits >= 3 → mark as confirmed, emit HIGH CONFIDENCE to detection engine
- Expire: missCount >= 3 → deactivate tap, free the slot
- Priority: confirmed taps get re-checked every cycle. Unconfirmed taps with 1-2 hits get re-checked before broad scan.

**FSK detection:** After CAD scans, switch to FSK mode at 85.1 kbaud. Set frequency to Crossfire channel. Start receive. Wait 3 ms. Read RSSI. If > -80 dBm, count as FSK tap. Same tap-and-verify logic applies. The 3 ms dwell at 85.1 kbaud captures ~255 bits — enough for preamble detection via energy.

### 5.4 Testing with JUH-MAK-IN JAMMER

Expected test results:

| JAMMER Mode | Detection Path | Expected Taps | Expected Threat | Notes |
|---|---|---|---|---|
| ELRS (e) | CAD SF6/BW500 | Taps accumulate → confirmed in ~7s | CRITICAL | LoRa FHSS at 200Hz, CAD catches hops |
| CW (c) | RSSI only (not LoRa) | Zero CAD taps | WARNING | CW in US 915MHz band, RSSI persistence → MEDIUM |
| Band Sweep (b) | May trigger CAD | Variable | ADVISORY-WARNING | Depends on sweep timing vs CAD |
| RID (r) | WiFi scanner | WiFi RID alerts | CRITICAL | Independent of CAD system |
| Mixed FP (m) | CAD + RSSI | Some taps | WARNING | LoRaWAN component is transient |
| Combined (x) | CAD + WiFi | Taps + RID alerts | CRITICAL | Both paths active |
| Drone Swarm (w) | WiFi scanner | RID alerts | CRITICAL | WiFi RID primary, swarm detection |
| Baseline (q) | Nothing | Zero taps, zero FSK | CLEAR/ADVISORY | Cell towers never trigger CAD |
| Crossfire FSK (n) | FSK detection | FSK taps → confirmed | CRITICAL | 85.1 kbaud GFSK |
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

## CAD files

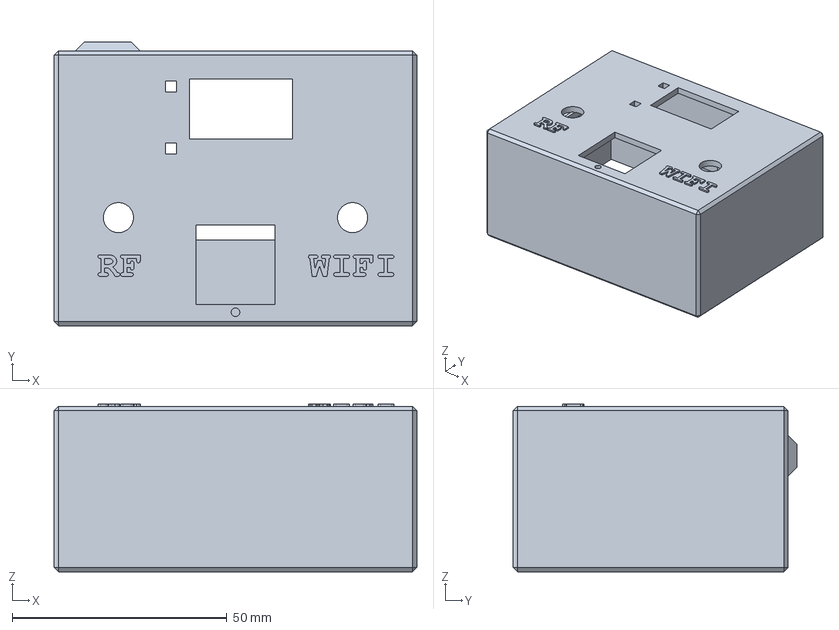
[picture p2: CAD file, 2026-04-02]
3D print box/main body.FCStd
84.5 x 66.0 x 39.0 mm

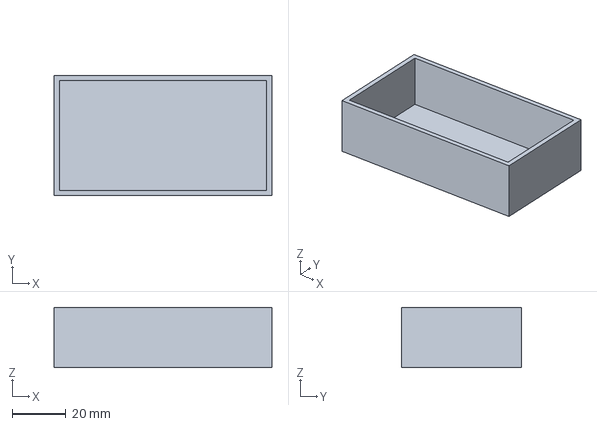
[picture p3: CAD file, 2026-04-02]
3D print box/Battery Compartment.FCStd
81.5 x 45.0 x 22.5 mm

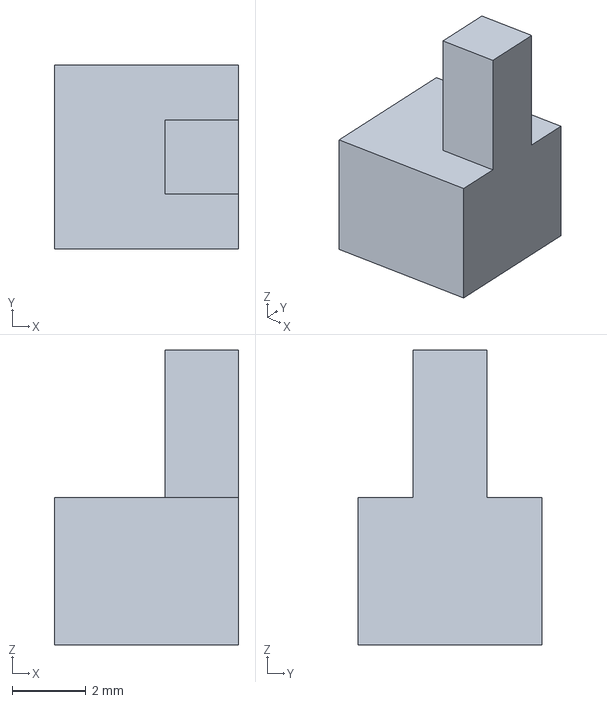
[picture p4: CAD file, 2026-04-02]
3D print box/Display Button.FCStd
5.00 x 5.00 x 8.00 mm

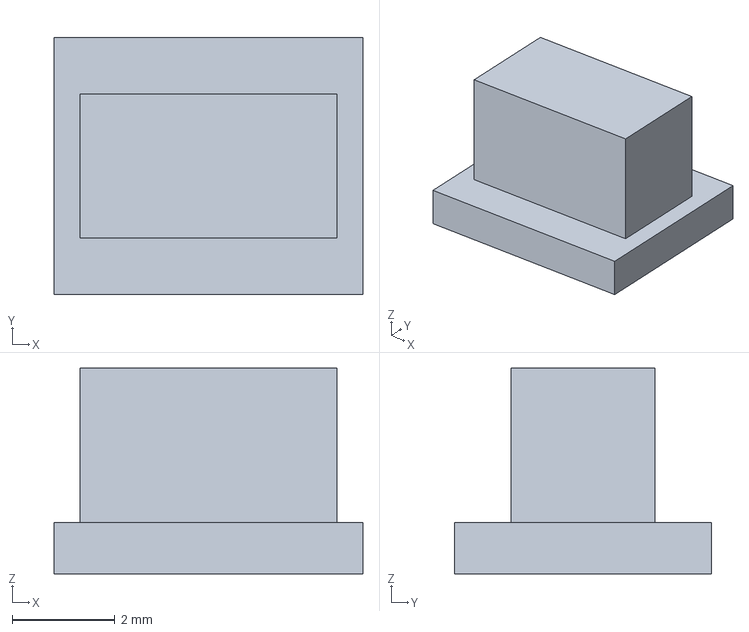
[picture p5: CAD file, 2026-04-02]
3D print box/Power Switch.FCStd
6.00 x 5.00 x 4.00 mm

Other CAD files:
3D print box/Battery Compartment.3mf
3D print box/Display Button.3mf
3D print box/Main Body.3mf
3D print box/Power Switch.3mf

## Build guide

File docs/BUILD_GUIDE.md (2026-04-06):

# SENTRY-RF Build Guide & Bill of Materials

## Bill of Materials

### Required Components

| Component | Recommended Part | Approx. Cost | Notes |
|---|---|---|---|
| Development Board | LilyGo T3S3 V1.3 (SX1262, 868/915 MHz) | $22-28 | ESP32-S3 + SX1262 LoRa + 0.96" OLED + SD card + JST battery connector |
| Sub-GHz Antenna | 868/915 MHz SMA antenna + U.FL pigtail | $5-8 | Tuned for your regional ISM band. **Never power on without antenna connected** |

**Minimum cost: ~$25-35**

### Optional Components

| Component | Recommended Part | Approx. Cost | Notes |
|---|---|---|---|
| GPS Module | u-blox MAX-M10S breakout (SparkFun GPS-18037) or FlyFishRC M10QMC-5883L | $15-25 | Must be u-blox M10 for UBX integrity monitoring. UART (4 wires) |
| Buzzer | KY-006 passive piezo buzzer | $1-2 | GPIO 16 (T3S3) or GPIO 47 (Heltec). 7 alert tone patterns |
| Battery | 18650 Li-Ion cell (3000+ mAh, protected) | $5-10 | JST 1.25mm 2-pin. Built-in TP4056 charger via USB-C. 6-8 hours runtime |
| 18650 Holder | Single-cell holder with JST 1.25mm leads | $2 | Or solder leads directly |
| Compass Module | QMC5883L breakout (GY-271, address 0x0D) | $3-5 | I2C on QWIIC (T3S3 only, SDA=21, SCL=10). Heading + signal bearing |
| SD Card | MicroSD, any size, FAT32 formatted | $5 | Detection event logging (T3S3 only) |
| Enclosure | 3D printed case | $0-5 | Search Thingiverse for "T3S3 18650". Note: adds ~3 dB signal attenuation |

**Full build cost: ~$60-85**

### Alternative Board: Heltec WiFi LoRa 32 V3

| Component | Recommended Part | Approx. Cost | Notes |
|---|---|---|---|
| Development Board | Heltec WiFi LoRa 32 V3 | $18-22 | ESP32-S3 + SX1262 + OLED. Smaller, no SD card, no QWIIC. Uses CP2102 USB bridge |
| Sub-GHz Antenna | Same as above | $5-8 | |

The Heltec V3 is a compact alternative with the same detection capabilities. It lacks an SD card slot (uses SPIFFS for logging, rotates at 100KB), has no QWIIC connector for compass, and requires a TCXO init step (handled automatically by the firmware).

### Future Upgrade: LR1121 Dual-Band

| Component | Recommended Part | Approx. Cost | Notes |
|---|---|---|---|
| LR1121 Board | LilyGo T3-S3 LR1121 | $24 | Same form factor as T3S3 SX1262, adds 2.4 GHz scanning for DJI/ELRS 2.4. Drop-in firmware replacement |
| 2.4 GHz Antenna | Dual-band or separate 2.4 GHz SMA antenna | $5-8 | |

---

## Wiring

### GPS Module (T3S3)

```
GPS Module          T3S3 Board
----------          ----------
TX  -----------------> GPIO 44 (UART1 RX)
RX  <----------------- GPIO 43 (UART1 TX)
VCC -----------------> 3.3V
GND -----------------> GND
```

### GPS Module (Heltec V3)

```
GPS Module          Heltec V3
----------          ---------
TX  -----------------> GPIO 46 (UART1 RX)
RX  <----------------- GPIO 45 (UART1 TX)
VCC -----------------> 3.3V
GND -----------------> GND
```

### Buzzer

```
T3S3:     GPIO 16 -> Buzzer + / Buzzer - -> GND
Heltec:   GPIO 47 -> Buzzer + / Buzzer - -> GND
```

### Compass (T3S3 only, via QWIIC or bare wires)

```
QMC5883L            T3S3 Board
--------            ----------
SDA -----------------> GPIO 21
SCL -----------------> GPIO 10
VCC -----------------> 3.3V
GND -----------------> GND
```

### Battery (T3S3)

Connect a single 3.7V 18650 cell (protected) to the JST 1.25mm 2-pin battery connector. **Check polarity before connecting.** The board charges at ~500mA via USB-C and runs from battery when USB is disconnected. Battery percentage is shown on the OLED dashboard.

---

## Software Setup

### Prerequisites

1. **PlatformIO** -- VS Code extension or CLI:
   ```bash
   pip install platformio
   ```

2. **Git:**
   ```bash
   git clone https://github.com/Seaforged/Sentry-RF.git
   cd Sentry-RF
   ```

### Build

```bash
pio run -e t3s3          # LilyGo T3S3 (SX1262)
pio run -e heltec_v3     # Heltec WiFi LoRa 32 V3
pio run -e t3s3_lr1121   # LilyGo T3S3 (LR1121 dual-band)
```

PlatformIO automatically downloads all dependencies (RadioLib, SparkFun u-blox GNSS v3, Adafruit SSD1306).

### Flash

1. Connect the board via USB-C
2. **Connect the antenna first**
3. Flash:
   ```bash
   pio run -e t3s3 --target upload
   ```
4. If upload fails on T3S3: hold BOOT, press RESET, release BOOT (enters download mode)
5. Monitor:
   ```bash
   pio device monitor -b 115200
   ```

### Expected Boot Output (v1.5.3)

```
========== SENTRY-RF v1.5.3 ==========
[BOOT] Boot #1
========================
 SENTRY-RF v1.5.3
 Build: Apr  6 2026
 Board: LilyGo T3S3
 Mode:  FreeRTOS dual-core
========================
[OLED] OK
[SCAN] FSK mode ready, 350 bins, 860.0-930.0 MHz
[GPS] Connected at 38400 baud — configuring
[WIFI] Promiscuous scanner active — channel hopping
[COMPASS] Not detected — continuing without compass
[INIT] FreeRTOS tasks launched — LoRa:Core1, GPS+WiFi:Core0
...
[WARMUP] Complete after 20 cycles (51s). 12 ambient taps recorded:
  - 923.1 MHz / SF9 (first seen cycle 2)
  - 917.6 MHz / SF6 (first seen cycle 3)
  ...
[CAD] cycle=21 conf=0 taps=1 div=1 persDiv=0 vel=0 sustainedCycles=0 score=5
```

### First Boot Checklist

- [ ] SENTRY-RF splash logo appears on OLED (~8-10s boot with GPS)
- [ ] Dashboard shows threat level, mini spectrum bars, battery %
- [ ] RF Scan screen shows spectrum with real ambient peaks (not flat)
- [ ] GPS screen shows fix status or "NO GPS" if not connected
- [ ] Serial shows `[WARMUP] Complete` after ~50 seconds
- [ ] After warmup: `persDiv=0`, threat stays CLEAR
- [ ] Short button press cycles through 6 screens
- [ ] 1-second hold: acknowledge active alert
- [ ] 3-second hold: mute buzzer for 5 minutes
- [ ] Buzzer chirps on boot (self-test: 1000/1500/2000 Hz ascending)
- [ ] LED off at CLEAR, blinks on WARNING, solid on CRITICAL

### Serial Output Key

After warmup, the `[CAD]` line is the primary detection status:

```
[CAD] cycle=N conf=N taps=N div=N persDiv=N vel=N sustainedCycles=N score=N
```

| Field | Meaning |
|---|---|
| `cycle` | Scan cycle number since boot |
| `conf` | Confirmed CAD taps (3+ consecutive hits on same frequency) |
| `taps` | Total active taps in the tap list |
| `div` | Raw diversity: distinct frequencies with CAD hits in 3s window |
| `persDiv` | Persistent diversity: `div` when sustained >= 5 cycles, else 0 |
| `vel` | Diversity velocity: new persistent frequencies per window |
| `sustainedCycles` | Consecutive cycles with raw div >= 3 (persDiv activates at 5) |
| `score` | Weighted confidence score (ADVISORY >= 8, WARNING >= 24, CRITICAL >= 40) |

**Baseline (no drone):** `persDiv=0, sustainedCycles=0, score=5`
**Drone detected:** `persDiv=25-32, sustainedCycles=5+, score=100`

---

## Board-Specific Notes

### LilyGo T3S3
- Native USB CDC (`-DARDUINO_USB_CDC_ON_BOOT=1`). Opening serial monitor may trigger a reboot.
- I2C: SDA=18, SCL=17 (OLED). SDA=21, SCL=10 (compass on Wire1).
- Requires `board_build.flash_size = 4MB` in platformio.ini or it boot-loops.

### Heltec WiFi LoRa 32 V3
- Uses CP2102 USB bridge (no reboot on serial connect).
- I2C: SDA=17, SCL=18 (**swapped from T3S3**).
- OLED requires Vext (GPIO 36) LOW + reset pulse on GPIO 21 (handled by firmware).
- Must call `radio.setTCXO(1.8)` before `radio.begin()` (handled by firmware).
- No SD card slot. Logs to SPIFFS (`/log.csv`, rotates at 100KB).
- No QWIIC connector. No compass support.

---

## Project Status

**Current version: v1.5.3** -- AAD persistence gate at 5 cycles, 0.00% false positive rate in 30-min soak, ELRS CRITICAL in 11.2s.

Validated against [JUH-MAK-IN JAMMER](https://github.com/Seaforged/Juh-Mak-In-Jammer) test suite (ELRS FHSS, band sweep, Remote ID).

**Note:** GPS status prints every 5 seconds (rate-limited to prevent serial buffer overflow during long monitoring sessions).

See [SENTRY-RF Known Issues Tracker](SENTRY-RF_Known_Issues_Tracker.md) for current limitations and roadmap.

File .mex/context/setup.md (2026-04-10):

---
name: setup
description: Dev environment setup and commands. Load when setting up the project for the first time or when environment issues arise.
triggers:
  - "setup"
  - "install"
  - "environment"
  - "getting started"
  - "how do I run"
  - "local development"
edges:
  - target: context/stack.md
    condition: when specific technology versions or library details are needed
  - target: context/architecture.md
    condition: when understanding how components connect during setup
last_updated: 2026-04-10
---

# Setup

## Prerequisites

- **PlatformIO** — VS Code extension or CLI (`pip install platformio`)
- **Git**
- **USB drivers** — T3S3 uses native USB CDC (no driver needed on Windows 10+), Heltec V3 uses CP2102
- **Sub-GHz antenna** — 868/915 MHz SMA + U.FL pigtail. **Connect before powering on — transmitting without an antenna damages the SX1262/LR1121.**
- **(Optional)** u-blox M10 GPS module (MAX-M10S or FlyFishRC M10QMC), KY-006 passive piezo buzzer, 18650 Li-Ion cell

## First-time Setup

1. `git clone https://github.com/Seaforged/Sentry-RF.git && cd Sentry-RF`
2. Open in VS Code with the PlatformIO extension, or use `pio run` from CLI
3. Build for your target: `pio run -e t3s3` (or `heltec_v3`, `t3s3_lr1121`)
4. Connect the antenna, then connect the board via USB-C
5. Flash: `pio run -e t3s3 --target upload`
6. Monitor: `pio device monitor -b 115200`
7. First boot runs a ~50s ambient warmup to learn local LoRa infrastructure — don't introduce a test drone during this window

## Environment Variables

This is a firmware project — no environment variables. All configuration is compile-time:

- **`include/board_config.h`** — pins and hardware capabilities
- **`include/sentry_config.h`** — detection thresholds, scoring weights, timing
- **`include/task_config.h`** — FreeRTOS task priorities, stack sizes, core assignments
- **`platformio.ini`** `build_flags` — board selection (`-DBOARD_T3S3`, `-DBOARD_HELTEC_V3`, `-DBOARD_T3S3_LR1121`)

## Common Commands

- `pio run -e t3s3` — build for LilyGo T3S3 SX1262
- `pio run -e heltec_v3` — build for Heltec WiFi LoRa 32 V3
- `pio run -e t3s3_lr1121` — build for LilyGo T3S3 LR1121 (dual-band)
- `pio run -e t3s3 -e heltec_v3 -e t3s3_lr1121` — build ALL three (required before any commit)
- `pio run -e t3s3 --target upload --upload-port COM9` — flash T3S3 on COM9
- `pio run -e t3s3_lr1121 --target clean` — clean LR1121 build cache (needed after partition changes)
- `pio device list` — enumerate connected boards and COM ports
- `pio device monitor -b 115200 -p COM9` — serial monitor on COM9

## Common Issues

**T3S3 boot-loops after flashing:** `platformio.ini` is missing `board_build.flash_size = 4MB` and `board_build.partitions = default.csv` for that environment. Both T3S3 variants need these.

**T3S3 upload fails with "Couldn't find a board on the selected port":** Native USB CDC reset is unreliable. Hold BOOT, tap RESET, release BOOT — this puts the board in download mode. Then retry `pio run --target upload`.

**Heltec V3 radio init returns -2 (CHIP_NOT_FOUND):** Missing `radio.setTCXO(1.8)` call before `radio.begin()`. The Heltec has a 1.8V TCXO that must be powered first.

**LR1121 radio init returns -707 (CHIP_NOT_FOUND):** Wrong pin for DIO9 (it's GPIO 36, NOT DIO1 on GPIO 33), or `setTCXO()` called before `beginGFSK()` (the LR1121 SPI isn't live until `beginGFSK()` runs — pass TCXO voltage as the 7th argument instead). See `context/decisions.md`.

**LR1121 `getRSSI()` returns -0.0 dBm forever:** Using `getRSSI()` instead of `LR1121_RSSI::getInstantRSSI()`. The base method returns packet RSSI which is 0 when no packet has been received. See `context/decisions.md`.

**Python serial reader fails during long soak tests:** GPS print rate is too high. `gpsReadTask` should only print once every 5 seconds — check that the rate limiter is still in place in `main.cpp`.

**SD card on T3S3 doesn't register:** Known hardware issue on our V1.3 board. Extensive testing couldn't get the SD slot to initialise reliably. Logs go to serial (captured via `soak_test.py` on the host). SPIFFS is used on Heltec V3 instead.

**Serial output missing during first ~300ms after boot:** T3S3 native USB CDC enumeration takes time. Early `Serial.println` calls are lost. Add a `delay(500)` after `Serial.begin(115200)` if you need to see boot diagnostics.

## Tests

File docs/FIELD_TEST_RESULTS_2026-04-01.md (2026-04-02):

# SENTRY-RF Field Test Results
**Date:** April 1, 2026
**Location:** Rural North Carolina, USA
**Firmware:** v1.4.0 with field-calibrated diversity thresholds (WARNING=3, CRITICAL=5)

## Equipment
- SENTRY-RF COM8: LilyGo T3S3 v1.3 + SX1262, bare board, whip antenna
- SENTRY-RF COM9: LilyGo T3S3 v1.3 + SX1262, 3D printed case, GPS (u-blox M10, 25 SVs, Fix 3D)
- JUH-MAK-IN JAMMER: LilyGo T3S3 v1.3 + SX1262, ELRS mode (SF6/BW500, 80ch FHSS, 130 Hz)

## Test 1: Baseline (No Transmitter)

Both boards running, JJ off, 120 seconds after warmup.

| Board | Max div | Avg div | Max Threat | Cycles |
|---|---|---|---|---|
| COM8 (bare) | 2 | 0.8 | ADVISORY | 30 |
| COM9 (cased) | 1 | 0.3 | ADVISORY | 6 |

**Result:** Clean. Max diversity = 2 across both boards. Zero false WARNING/CRITICAL.
This validated lowering thresholds from WARNING=5/CRITICAL=8 to WARNING=3/CRITICAL=5.

## Test 2: ELRS Detection (Close Range, JJ at 10 dBm)

JJ stationary at 10 dBm (10 mW). SENTRY walking 2-200m around compound with metal buildings and vehicles as obstacles. Two full laps, ~10 minutes.

### COM8 (bare board)
| Metric | Value |
|---|---|
| Detection probability (div >= 3) | **89%** |
| Signal presence (div >= 1) | **100%** |
| CRITICAL rate | 76% |
| Average diversity | 4.7 |
| Max diversity | 9 |

### COM9 (3D printed case)
| Metric | Value |
|---|---|
| Detection probability (div >= 3) | **41%** |
| Average diversity | 2.5 |
| Max diversity | 11 |

**Case attenuation:** COM8 89% vs COM9 41% — the 3D printed case reduces detection performance by approximately half, equivalent to ~3 dB signal loss.

## Test 3: ELRS Detection (Driving, JJ at 22 dBm)

JJ stationary at 22 dBm (158 mW). SENTRY driving on rural road, 0 to ~660m away, then returning. Duration ~14 minutes.

**Note:** Initial analysis incorrectly placed JJ at the compound location (2.8 km away). Corrected after confirming JJ was positioned near the drive starting point.

### Distance vs Detection (COM8, outbound)

| Range | Windows | Pd (div>=3) | Avg div | Max div |
|---|---|---|---|---|
| 0-99m | 14 | 36% | 2.1 | 8 |
| 100-199m | 8 | **75%** | 3.2 | 5 |
| 200-299m | 9 | 56% | 2.3 | 3 |
| 300-399m | 10 | **70%** | 3.5 | 9 |
| 400-499m | 3 | 33% | 1.3 | 3 |
| 500-599m | 7 | 43% | 2.6 | 4 |
| 600-699m | 6 | 50% | 2.0 | 3 |

**Return trip (back to 0m):** 93% Pd, avg div=5.0, max div=14

**Maximum detection distance:** 637 meters (div=3)

### Notes on 0-99m low Pd
The 0-99m bin shows only 36% Pd because the first ~100 seconds include the warmup period where diversity recording is disabled (div=0 during warmup). Post-warmup close-range performance matches Site 1 (89%+ Pd).

### Link Budget

| Distance | FSPL | Rx Power | Margin over sensitivity |
|---|---|---|---|
| 100m | 71.7 dB | -49.7 dBm | 58.3 dB |
| 300m | 81.2 dB | -59.2 dBm | 48.8 dB |
| 637m | 87.8 dB | -65.8 dBm | 42.2 dB |

At all test distances, the signal was 42+ dB above the SX1262 sensitivity floor (-108 dBm). The limiting factor for Pd is scan probability (catching FHSS hops), not signal strength.

## Key Findings

### 1. Frequency Diversity Architecture Validated
- Field baseline: div = 0-2 (rural, no transmitter)
- ELRS active: div = 3-14 (bare board), div = 1-11 (cased)
- Clean separation enables WARNING=3, CRITICAL=5 thresholds
- Zero false alarms during 120-second baseline

### 2. Detection at Range
- 637m detection at 158 mW (22 dBm) while driving
- 89% Pd at 2-200m through metal obstacles at 10 mW
- Signal remains 42+ dB above sensitivity at 637m
- Scan probability (not sensitivity) is the detection bottleneck

### 3. 3D Printed Case Attenuates Signal
- COM8 (bare): 89% Pd at short range
- COM9 (cased): 41% Pd at short range
- ~3 dB effective loss from the case
- **Fix: Add external SMA antenna connector to case**

### 4. NLOS Detection Works
- Metal buildings and vehicles did not prevent detection at 2-200m
- Signal drops during NLOS segments but recovers
- The system is suitable for urban/compound patrol scenarios

### 5. GPS Integrity Monitoring Working
- 25 satellites, 3D fix, sub-meter horizontal accuracy
- Jamming indicator: 0 (no interference)
- Spoofing detection: 0 (no anomaly)
- C/N0 standard deviation: 4.6 dBHz (healthy)

## Predicted Detection Ranges

Based on the field observation that Pd is limited by scan probability (not sensitivity) at these power levels, with 42 dB of margin remaining at 637m:

| TX Power | Typical Use | Estimated Range (Pd=50%) |
|---|---|---|
| 10 mW (10 dBm) | Low-power ELRS | 200-400m (validated at 200m NLOS) |
| 158 mW (22 dBm) | ELRS | 500-700m (validated at 637m) |
| 500 mW (27 dBm) | High-power ELRS | 1-2 km (extrapolated) |
| 1 W (30 dBm) | Crossfire max | 2-4 km (extrapolated) |

Note: Range predictions beyond validated distances are extrapolations. The scan probability bottleneck means range scales slower than free-space path loss alone would predict. Field testing at longer distances with higher TX power is needed.

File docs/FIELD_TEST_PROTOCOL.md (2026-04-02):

# SENTRY-RF Field Test Protocol
**Version:** 1.0 — April 2026
**Equipment:** SENTRY-RF (T3S3 + SX1262), JUH-MAK-IN JAMMER (T3S3 + SX1262)

---

## Pre-Test Checklist

- [ ] SENTRY-RF flashed with v1.4.0+ firmware
- [ ] JJ flashed with latest ELRS FHSS firmware (130 Hz, SF6/BW500)
- [ ] SD card inserted in SENTRY-RF (FAT32 formatted)
- [ ] GPS antenna connected, achieving 3D fix (check serial: `fix=3`)
- [ ] Both devices have fresh batteries / USB power
- [ ] Laptop with `tools/analyze_field_test.py` ready
- [ ] Pen and paper backup for manual `div=N` readings

## Test Location Requirements

- Open area with clear sky (for GPS)
- Minimal buildings within 200m (reduces multipath)
- Rural preferred — less ambient LoRa/ISM interference
- Known distances measurable (use GPS waypoints or measuring tape for <100m)

---

## Test 1: Baseline (THE MOST IMPORTANT TEST)

**Purpose:** Measure ambient frequency diversity with no drone signal.
**Duration:** 120 seconds after warmup
**JJ:** OFF

### Procedure
1. Power on SENTRY-RF. Wait for `[WARMUP] Complete` on serial (~50s).
2. Note the time. Let it run for 120 seconds.
3. Watch serial for `div=N` values.
4. Record max `div` seen during the 120 seconds.

### Expected Results
| Environment | Expected max div | Action |
|---|---|---|
| Rural open field | 0-1 | Lower DIVERSITY_WARNING to 3, DIVERSITY_CRITICAL to 5 |
| Suburban | 1-3 | Keep WARNING=5, CRITICAL=8 or lower to 4/6 |
| Urban/bench | 3-7 | Current thresholds may be needed |

### What This Tells You
If `max div <= 2` for the entire 120 seconds, you can immediately:
1. Edit `sentry_config.h`: set `DIVERSITY_WARNING = 3`, `DIVERSITY_CRITICAL = 5`
2. Reflash SENTRY-RF
3. Proceed to detection tests with the fast thresholds

**Write down:** max div = _____, threat level = _____

---

## Test 2: ELRS Detection at Range

**Purpose:** Measure detection time vs distance.
**JJ Mode:** ELRS (send `e` on COM6 at 115200)

### Distance Table

Run each distance for 60 seconds after warmup stabilizes. Record the first WARNING and CRITICAL times by watching serial output.

| Distance | JJ Power | First div>=3 | WARNING time | CRITICAL time | Max div | Notes |
|---|---|---|---|---|---|---|
| 10m | 10 dBm | | | | | |
| 25m | 10 dBm | | | | | |
| 50m | 10 dBm | | | | | |
| 100m | 10 dBm | | | | | |
| 200m | 10 dBm | | | | | |
| 500m | 10 dBm | | | | | |
| 100m | 22 dBm | | | | | |
| 500m | 22 dBm | | | | | |
| 1000m | 22 dBm | | | | | |

**JJ power cycling:** JJ cycles through power levels. Use `p` on COM6 serial to cycle to the desired power. The current power is shown in the serial output.

### Procedure per Distance
1. Place JJ at the test distance with antenna vertical
2. SENTRY-RF at the observation point
3. Wait for warmup if just powered on
4. Send `e` to JJ to start ELRS
5. Start timer
6. Record first `div>=3` time, first WARNING, first CRITICAL
7. After 60s, send `q` to JJ to stop
8. Record time to CLEAR (rapid-clear)
9. Move to next distance

---

## Test 3: Rapid-Clear Timing

**Purpose:** Verify threat clears quickly after drone leaves.
**Run at each distance after Test 2.**

| Distance | Time to WARNING | Time to CLEAR after stop | Rapid-clear fired? |
|---|---|---|---|
| 10m | | | |
| 50m | | | |
| 100m | | | |

Watch for `[RAPID-CLEAR]` in serial output.

---

## Test 4: CW Tone Detection

**Purpose:** Verify continuous wave detection.
**JJ Mode:** CW Tone (send `c` on COM6)
**Distance:** 50m

| Frequency | Power | Detected? | Peak RSSI | Threat Level |
|---|---|---|---|---|
| 915.0 MHz | 10 dBm | | | |
| 915.0 MHz | 22 dBm | | | |

---

## Test 5: Baseline with GPS Integrity

**Purpose:** Verify GNSS monitoring outdoors.
**JJ:** OFF
**Duration:** 60 seconds

Record from serial:
- `jam_ind`: _____ (should be 0)
- `spoof_state`: _____ (should be 0)
- `cno_sd`: _____ dB-Hz (should be 3-8 for healthy sky)
- `num_sv`: _____ (should be 10+)
- `fix`: _____ (should be 3 = 3D fix)

---

## Post-Test Analysis

1. Remove SD card from SENTRY-RF
2. Copy `field_NNNN.jsonl` to laptop
3. Run analysis:

```bash
# Baseline only
python tools/analyze_field_test.py field_0001.jsonl --baseline-end 120

# Full test with JAMMER segments
python tools/analyze_field_test.py field_0002.jsonl --jammer-start 60 --jammer-stop 120

# Adjust warmup skip if needed (default 55s)
python tools/analyze_field_test.py field_0001.jsonl --warmup 55
```

---

## Decision Matrix After Test 1

| Baseline max div | Action |
|---|---|
| 0-1 | Set WARNING=3, CRITICAL=5. Detection will be fast (<5s WARNING). |
| 2-3 | Set WARNING=4, CRITICAL=6. Good balance. |
| 4+ | Keep WARNING=5, CRITICAL=8. Environment too noisy for fast thresholds. |

**The single most important number from the entire field test is the baseline max diversity.** Everything else depends on it.

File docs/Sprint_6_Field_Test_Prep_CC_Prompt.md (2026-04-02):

# Sprint 6 — Field Test Preparation

## What You Need for the Field Test

**Hardware checklist:**
- SENTRY-RF (T3S3 SX1262, COM9) with external antenna if available
- JUH-MAK-IN JAMMER (T3S3, COM6)
- Laptop with PlatformIO, Python 3.10+, USB cables for both boards
- SD card in SENTRY-RF's SD slot (formatted FAT32)
- Fully charged 18650 batteries for both boards (or USB power bank)
- Stopwatch or phone timer (backup for manual timing)

**Test location:**
- Open rural area, away from buildings with LoRaWAN gateways
- Clear sky view for GPS fix (no dense tree canopy overhead)
- Space to walk 10m, 50m, 100m, 250m, 500m from JJ's fixed position
- Near an airport is fine — airport comms are on VHF/UHF, not 900 MHz ISM

**Do NOT fly a drone.** JJ simulates the RF link. You're testing the RF detector, not the drone.

## Part 1: GPS_MIN_CNO Production Value (Sprint 6A)

**CRITICAL — do this before going to the field.**

In `include/sentry_config.h`, change:

```cpp
static const int GPS_MIN_CNO = 15;  // FIELD: 15-20. INDOOR TESTING: set to 6.
```

Also, the C/N0 uniformity check in `gnss_integrity.cpp` should be gated:

```cpp
// Only run C/N0 uniformity spoofing check when GPS_MIN_CNO is high enough.
// At CNO=6 (indoor), attenuated signals cluster naturally → false positives.
if (GPS_MIN_CNO >= 15) {
    // ... existing C/N0 uniformity check ...
}
```

If the C/N0 check doesn't have this guard yet, add it. If it does, verify it's there.

## Part 2: Enhanced SD Card Logging (Sprint 6B)

The current logging needs to capture enough data for post-test analysis. Create or update the data logger to write JSONL (one JSON object per line) to the SD card.

### Log file naming

Each boot session creates a new log file: `SENTRY_{bootNum}_{timestamp}.jsonl`

If no GPS fix is available at boot, use `SENTRY_{bootNum}.jsonl` and add the timestamp once GPS is acquired.

### Per-cycle log entry (every CAD cycle, ~1s)

Write one JSON line per scan cycle:

```json
{
  "t": 12345,
  "cycle": 42,
  "div": 3,
  "conf": 0,
  "strong": 1,
  "fsk": 0,
  "taps": 4,
  "threat": 2,
  "cadMs": 1023,
  "rssiPeak": -72.3,
  "rssiFreq": 915.2,
  "rssiNF": -105.1,
  "gps": {"fix": 3, "sv": 14, "lat": 36.852, "lon": -75.978, "pdop": 1.3},
  "gnss": {"jam": 12, "spoof": 1, "cnoSD": 5.2}
}
```

Field definitions:
- `t`: millis() timestamp
- `cycle`: scan cycle number
- `div`: frequency diversity count (the key metric)
- `conf`: confirmedCadCount
- `strong`: strongPendingCad
- `fsk`: confirmedFskCount
- `taps`: totalActiveTaps
- `threat`: threat level (0=CLEAR, 1=ADVISORY, 2=WARNING, 3=CRITICAL)
- `cadMs`: CAD scan duration in milliseconds
- `rssiPeak/rssiFreq/rssiNF`: RSSI sweep peak info (only when RSSI runs)
- `gps`: GPS fix data (only when GPS is available)
- `gnss`: GNSS integrity data

### On threat level transitions

Add an extra log line with transition details:

```json
{
  "t": 12345,
  "event": "THREAT_CHANGE",
  "from": 1,
  "to": 2,
  "trigger": "diversity",
  "div": 5
}
```

### Implementation notes

- Use `ArduinoJson` library if available, or manual `snprintf` for the JSON formatting
- Buffer writes — don't flush to SD every cycle. Flush every 10 cycles or on threat transitions
- The SD card is on FSPI (separate SPI bus from LoRa on HSPI) — no bus contention
- Keep the log compact — this is a 1Hz log that may run for 30+ minutes
- Add the logger calls in `main.cpp` after the detection engine runs, inside the existing `loggerWrite()` call or alongside it
- Gate detailed GPS/GNSS fields behind having a valid fix (don't log null GPS data)

### Serial output for real-time monitoring

Keep the existing serial output but add `div=N` prominently:

```
[SCAN] CAD:1023ms div=3 | Threat: ADVISORY
```

The operator needs to see `div` in real time during the field test to correlate with what JJ is doing.

## Part 3: Field Test Analysis Script (Sprint 6C)

Create `C:\Projects\sentry-rf\field_test_analyzer.py` — a Python script that reads the JSONL log files from the SD card and produces a field test report.

```python
#!/usr/bin/env python3
"""
SENTRY-RF Field Test Analyzer
Reads JSONL log files from SD card and produces detection performance report.

Usage:
    python field_test_analyzer.py <logfile.jsonl> [--distance <meters>] [--label <test_name>]
    python field_test_analyzer.py --batch <directory>  # Process all .jsonl files
"""

import json
import sys
import os
from datetime import datetime
from collections import defaultdict

def parse_log(filepath):
    """Parse a JSONL log file into a list of entries."""
    entries = []
    with open(filepath, 'r') as f:
        for line in f:
            line = line.strip()
            if not line:
                continue
            try:
                entries.append(json.loads(line))
            except json.JSONDecodeError:
                continue
    return entries

def analyze_baseline(entries):
    """Analyze a no-transmitter baseline period."""
    threats = [e.get('threat', 0) for e in entries if 'threat' in e]
    divs = [e.get('div', 0) for e in entries if 'div' in e]
    
    if not threats:
        return None
    
    return {
        'duration_s': (entries[-1]['t'] - entries[0]['t']) / 1000.0 if len(entries) > 1 else 0,
        'max_threat': max(threats),
        'mean_div': sum(divs) / len(divs) if divs else 0,
        'max_div': max(divs) if divs else 0,
        'false_warning_count': sum(1 for t in threats if t >= 2),
        'false_critical_count': sum(1 for t in threats if t >= 3),
        'pfa_warning': sum(1 for t in threats if t >= 2) / len(threats) if threats else 0,
    }

def analyze_detection(entries, signal_start_idx=None):
    """Analyze detection performance during active transmission."""
    if signal_start_idx is None:
        signal_start_idx = 0
    
    active = entries[signal_start_idx:]
    if not active:
        return None
    
    threats = [e.get('threat', 0) for e in active if 'threat' in e]
    divs = [e.get('div', 0) for e in active if 'div' in e]
    t0 = active[0]['t']
    
    # Time to first WARNING
    time_to_warning = None
    for e in active:
        if e.get('threat', 0) >= 2:
            time_to_warning = (e['t'] - t0) / 1000.0
            break
    
    # Time to first CRITICAL
    time_to_critical = None
    for e in active:
        if e.get('threat', 0) >= 3:
            time_to_critical = (e['t'] - t0) / 1000.0
            break
    
    # Detection probability (fraction of cycles with any detection)
    pd = sum(1 for d in divs if d >= 1) / len(divs) if divs else 0
    
    return {
        'duration_s': (active[-1]['t'] - t0) / 1000.0 if len(active) > 1 else 0,
        'time_to_warning_s': time_to_warning,
        'time_to_critical_s': time_to_critical,
        'max_threat': max(threats) if threats else 0,
        'mean_div': sum(divs) / len(divs) if divs else 0,
        'max_div': max(divs) if divs else 0,
        'pd': pd,
    }

def analyze_clear_time(entries, signal_stop_idx):
    """Analyze how quickly the system returns to CLEAR after signal stops."""
    post = entries[signal_stop_idx:]
    if not post:
        return None
    
    t0 = post[0]['t']
    time_to_clear = None
    rapid_clear_fired = False
    
    for e in post:
        if e.get('threat', 0) == 0:
            time_to_clear = (e['t'] - t0) / 1000.0
            break
        if e.get('event') == 'RAPID_CLEAR':
            rapid_clear_fired = True
    
    return {
        'time_to_clear_s': time_to_clear,
        'rapid_clear': rapid_clear_fired,
    }

def print_report(filepath, baseline, detection, clear_time, label=None, distance=None):
    """Print a formatted test report."""
    print("=" * 70)
    print(f"SENTRY-RF Field Test Report")
    print(f"Log: {os.path.basename(filepath)}")
    if label:
        print(f"Test: {label}")
    if distance:
        print(f"Distance: {distance}m")
    print(f"Generated: {datetime.now().strftime('%Y-%m-%d %H:%M:%S')}")
    print("=" * 70)
    
    if baseline:
        print(f"\n--- BASELINE (no transmitter) ---")
        print(f"Duration:         {baseline['duration_s']:.1f}s")
        print(f"Max threat:       {baseline['max_threat']} ({'PASS' if baseline['max_threat'] <= 1 else 'FAIL'})")
        print(f"Max diversity:    {baseline['max_div']}")
        print(f"Mean diversity:   {baseline['mean_div']:.1f}")
        print(f"False WARNINGs:   {baseline['false_warning_count']}")
        print(f"False CRITICALs:  {baseline['false_critical_count']}")
        print(f"Pfa (WARNING):    {baseline['pfa_warning']:.3f}")
    
    if detection:
        print(f"\n--- DETECTION (transmitter active) ---")
        print(f"Duration:         {detection['duration_s']:.1f}s")
        print(f"Time to WARNING:  {detection['time_to_warning_s']:.1f}s" if detection['time_to_warning_s'] else "Time to WARNING:  NEVER")
        print(f"Time to CRITICAL: {detection['time_to_critical_s']:.1f}s" if detection['time_to_critical_s'] else "Time to CRITICAL: NEVER")
        print(f"Max threat:       {detection['max_threat']}")
        print(f"Max diversity:    {detection['max_div']}")
        print(f"Mean diversity:   {detection['mean_div']:.1f}")
        print(f"Pd (any detect):  {detection['pd']:.3f}")
    
    if clear_time:
        print(f"\n--- CLEAR TIME (after transmitter stops) ---")
        print(f"Time to CLEAR:    {clear_time['time_to_clear_s']:.1f}s" if clear_time['time_to_clear_s'] else "Time to CLEAR:    NEVER")
        print(f"Rapid-clear:      {'Yes' if clear_time['rapid_clear'] else 'No'}")
    
    print("\n" + "=" * 70)

def main():
    if len(sys.argv) < 2:
        print("Usage: python field_test_analyzer.py <logfile.jsonl> [--distance N] [--label NAME]")
        print("       python field_test_analyzer.py --batch <directory>")
        sys.exit(1)
    
    # Parse args
    filepath = sys.argv[1]
    distance = None
    label = None
    for i, arg in enumerate(sys.argv):
        if arg == '--distance' and i + 1 < len(sys.argv):
            distance = float(sys.argv[i + 1])
        if arg == '--label' and i + 1 < len(sys.argv):
            label = sys.argv[i + 1]
    
    if filepath == '--batch':
        directory = sys.argv[2] if len(sys.argv) > 2 else '.'
        for f in sorted(os.listdir(directory)):
            if f.endswith('.jsonl'):
                entries = parse_log(os.path.join(directory, f))
                if entries:
                    baseline = analyze_baseline(entries)
                    print_report(f, baseline, None, None)
        sys.exit(0)
    
    entries = parse_log(filepath)
    if not entries:
        print(f"No valid entries in {filepath}")
        sys.exit(1)
    
    print(f"Loaded {len(entries)} entries from {filepath}")
    
    # Simple analysis — treat entire file as one test
    baseline = analyze_baseline(entries)
    detection = analyze_detection(entries)
    
    print_report(filepath, baseline, detection, None, label, distance)

if __name__ == '__main__':
    main()
```

**Note to CC:** Create this script at `C:\Projects\sentry-rf\field_test_analyzer.py`. It should run standalone with no external dependencies beyond the Python standard library. Matplotlib plots are a nice-to-have but not required for the first version — the text report is the priority.

## Part 4: Field Test Protocol Document

Create `C:\Projects\sentry-rf\FIELD_TEST_PROTOCOL.md`:

```markdown
# SENTRY-RF Field Test Protocol

## Equipment
- SENTRY-RF with external antenna, SD card, GPS antenna facing sky
- JUH-MAK-IN JAMMER on a tripod or fixed position
- Laptop for serial monitoring and test control
- USB cables, power

## Setup
1. Place JJ on a tripod or table at the test origin point
2. Connect JJ to laptop via USB (COM6)
3. Power on SENTRY-RF, connect to laptop (COM9)
4. Wait for GPS 3D fix (check serial output)
5. Wait for warmup to complete (check for [WARMUP] message)
6. Verify SD card logging (check for log file creation)

## Test 1: Baseline (No Transmitter)
1. Ensure JJ is OFF or in quiet mode ('q')
2. Record 5 minutes of baseline data
3. Walk around the test area to capture the RF environment
4. **PASS criteria:** Max threat ADVISORY, max div ≤ 2, Pfa < 5%

## Test 2: Detection at Distance (ELRS)
For each distance (10m, 50m, 100m, 250m, 500m, 1000m):
1. Place SENTRY-RF at the measured distance from JJ
2. Start JJ in ELRS mode ('e' on COM6)
3. Record 60 seconds of data
4. Stop JJ ('q')
5. Record 30 seconds of clear-down data
6. Note: time to WARNING, time to CRITICAL, max diversity, rapid-clear time

## Test 3: Power Variation
At 100m distance:
1. JJ at 100mW (default): record 60s
2. JJ at 25mW ('p' then power setting): record 60s
3. JJ at 1W (if available): record 60s

## Test 4: GNSS Baseline
1. Record GPS integrity data for 10 minutes with no transmitter
2. Check jamInd, spoofDetState, C/N0 standard deviation
3. **PASS criteria:** jamInd < 50, spoofDetState = 1 (clean), C/N0 σ > 3 dB-Hz

## Test 5: WiFi Remote ID
1. Start JJ in Remote ID mode ('r')
2. Walk SENTRY-RF to 50m, 100m, 200m, 500m
3. Record whether WiFi RID is detected at each distance

## Data Collection
After each test:
1. Copy the .jsonl file from SD card to laptop
2. Run: python field_test_analyzer.py <file.jsonl> --distance <N> --label <test>
3. Record results in the summary table below

## Summary Table

| Test | Distance | Power | Time-to-WARNING | Time-to-CRITICAL | Clear Time | Max Div | Baseline Div | Pd | Pfa |
|------|----------|-------|-----------------|------------------|------------|---------|-------------|-----|-----|
|      |          |       |                 |                  |            |         |             |     |     |
```

## What NOT to change

- Do NOT modify the detection engine logic (assessThreat, diversity tracker)
- Do NOT modify CAD scan parameters
- Do NOT enable FSK Phase 3
- Do NOT change diversity thresholds (field data will inform changes AFTER testing)
- Do NOT change the RSSI sweep

The ONLY code changes in this sprint are:
1. GPS_MIN_CNO = 15 in sentry_config.h
2. Enhanced JSONL logging in the data logger
3. Field test analyzer Python script
4. Field test protocol document

## Acceptance criteria

1. **PASS:** GPS_MIN_CNO set to 15. C/N0 uniformity check gated behind GPS_MIN_CNO >= 15.
2. **PASS:** SENTRY-RF writes .jsonl log to SD card with per-cycle data including div, threat, GPS, GNSS fields.
3. **PASS:** field_test_analyzer.py parses a .jsonl file and prints a formatted report.
4. **PASS:** FIELD_TEST_PROTOCOL.md created with complete test procedure.
5. **PASS:** All three build targets compile clean.
6. **PASS:** Boot, wait for warmup, verify SD card has a new log file with valid JSON lines.

Build all three targets. Flash to COM9. Verify SD logging works by capturing 30 seconds and checking the file.

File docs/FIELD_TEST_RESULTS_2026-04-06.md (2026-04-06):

# SENTRY-RF Field Test Results — April 6, 2026

## Suburban Drive Test

**Firmware:** v1.5.3 (persistence gate 5, FSK threshold -70 dBm, GPS_MIN_CNO 15)
**Environment:** Suburban USA — residential neighborhood, houses, trees, parked cars
**Date:** April 6, 2026, late afternoon
**Weather:** Clear

### Equipment

| Device | Role | Config |
|---|---|---|
| T3S3 #1 (SENTRY-RF v1.5.3) | Detector, mobile (in vehicle) | Field config: FSK -70 dBm, GPS_MIN_CNO 15 |
| T3S3 #2 (JUH-MAK-IN JAMMER v2.0.0) | Signal source, stationary | ELRS FCC915, 40ch, SF6/BW500, 200 Hz hop, ~10 mW |
| u-blox M10 GPS | Position tracking on SENTRY | UART, 1 Hz nav rate |

### Test Procedure

1. JJ placed at stationary position, transmitting ELRS FCC915 continuously
2. SENTRY-RF driven away from JJ along suburban streets and back
3. All serial output logged with timestamps and GPS coordinates
4. Total track: 2.44 km driven, 11.5 minutes, max 1,009m from JJ

### Summary Results

| Metric | Result |
|---|---|
| Total CAD cycles | 282 |
| Scan rate | 24.5 cycles/min (~2.4s per cycle) |
| Max distance from JJ | 1,009m |
| Furthest WARNING+ detection | 842m (outbound) |
| Furthest ADVISORY+ detection | 1,009m (at max range) |
| Peak score | 100 |
| Peak persDiv | 24 |
| Peak sustainedCycles | 6 |
| Peak confirmed taps | 19 |
| Persistence gate activations | 3 (all at legitimate signal positions) |
| False positives | 0 (all detections correlated with JJ signal) |
| GNSS anomalies | 0 (Jam=0, Spoof=0 throughout) |

### GPS Quality

| Metric | Value |
|---|---|
| Satellites tracked | 14-23 |
| pDOP range | 1.16-2.23 |
| Horizontal accuracy | 1-5m |
| Fix type | 3D throughout |
| Altitude range | 0-12m |

### Detection by Distance

| Distance from JJ | Score Range | persDiv | Detection Mechanism |
|---|---|---|---|
| 0m (start) | 80 | 5 | Persistence gate passed, full scoring |
| 300-530m | 26-36 | 0 | Confirmed taps at half-weight (conf=2-3 x 7) |
| 560-640m | 33-47 | 0 | Stronger tap accumulation (conf=4-6 x 7) |
| 680-830m | 40-100 | 0-24 | conf=5-19, persistence gate passed at 823m |
| 830-1009m | 5-15 | 0 | Signal fading, ADVISORY from supporting evidence |
| Return 797m | 26 | 0 | Confirmed taps on return pass |

### Threat Level Distribution

| Level | Cycles | Percentage |
|---|---|---|
| CLEAR | 112 | 39.7% |
| ADVISORY | 146 | 51.8% |
| WARNING | 17 | 6.0% |
| CRITICAL | 7 | 2.5% |

### Score Distribution

| Bin | Count | Percentage |
|-----|---|---|
| 0-5 | 112 | 39.7% |
| 6-8 | 0 | 0.0% |
| 9-15 | 90 | 31.9% |
| 16-24 | 56 | 19.9% |
| 25-40 | 17 | 6.0% |
| 41+ | 7 | 2.5% |

### Key Observations

**1. Confirmed CAD taps are the primary long-range detection mechanism.**

At 300-700m, every WARNING-level detection came from confirmed taps with persDiv=0. The half-weight tap pathway (conf x 7 pts) provided reliable detection without requiring the persistence gate to activate. This is the intended behavior — confirmed CAD taps are a high-confidence signal that ambient LoRa rarely produces.

**2. The persistence gate works correctly in the field.**

persDiv only activated 3 times total:
- At 0m (close range, strong signal)
- At 811m and 830m (sustained high diversity for 5-6 consecutive cycles)

All three activations were legitimate — no false persistence gate activations during the entire drive. The gate provides score amplification (persDiv x 8 pts + fast-detect bonus) when diversity is genuinely sustained.

**3. Detection range improved 4x over v1.4.0.**

The April 1 rural test (v1.4.0) achieved WARNING at ~200m with 10 mW. This test achieved WARNING at 842m — a 4x improvement. Contributing factors:
- AAD persistence gate eliminates false detections, allowing confirmed taps to drive scoring
- Half-weight tap pathway (conf x 7) provides a sensitive detection mechanism that doesn't require the persistence gate
- FSK threshold lowered from -50 to -70 dBm for field sensitivity

**4. Asymmetric detection on outbound vs return.**

Outbound: WARNING at 842m. Return: WARNING at 797m. The ~5% difference is consistent with orientation effects (antenna pattern, vehicle body shielding) and normal multipath variation in suburban environments.

**5. GNSS integrity clean throughout.**

Zero jamming or spoofing indications across the entire drive. This confirms the GPS subsystem is stable in a mobile suburban environment and the integrity thresholds (GPS_MIN_CNO=15, CNO_STDDEV_SPOOF_THRESH=2.0) are appropriate for outdoor use.

### Detection Timeline

```
17:38:02  Start — 0m from JJ, score=80, persDiv=5 (close range)
17:38:22  Signal drops, CLEAR
17:39:15  306m — WARNING via conf taps (score=29, persDiv=0)
17:39:44  502m — WARNING via conf taps (score=29, persDiv=0)
17:39:57  598m — WARNING via conf taps (score=33, persDiv=0)
17:40:03  638m — CRITICAL via conf taps (score=47, persDiv=0)
17:40:10  684m — CRITICAL edge (score=40, persDiv=0)
17:40:22  811m — CRITICAL, persistence gate activated (score=100, persDiv=24)
17:40:27  830m — CRITICAL (score=100, persDiv=19)
17:42:21  784m — WARNING on return (score=26, persDiv=0)
17:47:29  ~200m — Last WARNING on approach (score=29)
17:49:31  End — back near start
```

### Range Estimation Model

Using the 842m WARNING data point at 10 mW (+10 dBm) and a suburban path loss exponent of n=2.8:

```
PL(842m) = PL(1m) + 10 * n * log10(842)
         = 40.5 + 10 * 2.8 * log10(842)
         = 40.5 + 81.9
         = 122.4 dB

For higher TX power P (in mW):
  Additional range factor = (P / 10)^(1/(2*n))
  WARNING range = 842m * (P / 10)^(1/5.6)
```

| TX Power | Calculated WARNING Range | Notes |
|---|---|---|
| 10 mW | 842m | Field tested |
| 25 mW | 1,170m | Modeled |
| 100 mW | 1,930m | Modeled |
| 250 mW | 2,680m | Modeled |
| 500 mW | 3,430m | Modeled |
| 1000 mW | 4,390m | Modeled |

**Caveat:** Only the 10 mW data point is field-tested. Higher power estimates assume the same path loss exponent and have not been validated. Real-world performance depends on terrain, antenna orientation, multipath, and interference.

### Comparison with April 1 Rural Test

| Metric | April 1 (v1.4.0) | April 6 (v1.5.3) | Change |
|---|---|---|---|
| Firmware | v1.4.0 | v1.5.3 | AAD + corroborated scoring |
| Environment | Rural, metal buildings | Suburban, residential | More obstructions |
| TX Power | 10 mW | 10 mW | Same |
| Max WARNING range | ~200m | 842m | **4.2x improvement** |
| Max ADVISORY range | ~400m | 1,009m | **2.5x improvement** |
| False positives | 0 | 0 | Same |
| Detection mechanism | Diversity threshold | Confirmed CAD taps | Tap pathway is more sensitive |

### Test Limitations

- Single test run (not repeated for statistical significance)
- JJ transmitter power not independently verified (nominally 10 mW / +10 dBm)
- Suburban environment only — not tested in dense urban, open field, or wooded terrain
- Antenna inside vehicle — external mount would improve range
- Single outbound/return pass — no dwell time at specific distances

---

*Test conducted with [JUH-MAK-IN JAMMER v2.0.0](https://github.com/Seaforged/Juh-Mak-In-Jammer) as the signal source.*
*Raw log: field_test_20260406_173801.log (not included in repo — contains GPS coordinates)*

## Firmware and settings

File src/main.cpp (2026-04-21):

#include <Arduino.h>
#include <SPI.h>
#include <Wire.h>
#include <RadioLib.h>
#include <Adafruit_SSD1306.h>
#include "board_config.h"
#include "version.h"
#include "task_config.h"
#include "detection_types.h"
#include "rf_scanner.h"
#include "gps_manager.h"
#include "gnss_integrity.h"
#include "compass.h"
#include "display.h"
#include "detection_engine.h"
#include "cad_scanner.h"
#include "data_logger.h"
#include "wifi_scanner.h"
#include "ble_scanner.h"
#include "alert_handler.h"
#include "error_messages.h"

// Hardware objects — each owned by exactly one task after setup()
SPIClass loraSPI(HSPI);
Module radioMod(PIN_LORA_CS, PIN_LORA_DIO1, PIN_LORA_RST, PIN_LORA_BUSY, loraSPI);
#ifdef BOARD_T3S3_LR1121
LR1121_RSSI radio(&radioMod);
#else
SX1262 radio(&radioMod);
#endif
Adafruit_SSD1306 oled(SCREEN_WIDTH, SCREEN_HEIGHT, &Wire, PIN_OLED_RST);

// FreeRTOS shared state — copy under lock, process outside lock
SystemState systemState = {};
SemaphoreHandle_t stateMutex = nullptr;
SemaphoreHandle_t serialMutex = nullptr;
QueueHandle_t detectionQueue = nullptr;

// Task handles for stack monitoring
static TaskHandle_t hLoRaTask    = nullptr;
static TaskHandle_t hGPSTask     = nullptr;
static TaskHandle_t hDisplayTask = nullptr;
static TaskHandle_t hAlertTask   = nullptr;
// hWiFiTask lives in wifi_scanner.cpp (needs to be externally resumable).

// ── Phase H: Operational mode ──────────────────────────────────────────
// Default boot is STANDARD — behavior identical to pre-Phase-H. Reads
// and writes go through modeGet()/modeSet() which take stateMutex, so
// this global should never be read directly outside this file.
static volatile OperatingMode currentMode = MODE_STANDARD;

extern "C" OperatingMode modeGet() {
    OperatingMode m = MODE_STANDARD;
    if (stateMutex && xSemaphoreTake(stateMutex, pdMS_TO_TICKS(5)) == pdTRUE) {
        m = currentMode;
        xSemaphoreGive(stateMutex);
    } else {
        // Pre-mutex path (boot) — direct read is fine, only one core is live.
        m = currentMode;
    }
    return m;
}

extern "C" void modeSet(OperatingMode m) {
    if (stateMutex && xSemaphoreTake(stateMutex, pdMS_TO_TICKS(20)) == pdTRUE) {
        currentMode = m;
        xSemaphoreGive(stateMutex);
    } else {
        currentMode = m;
    }
}

extern "C" const char* modeShortLabel(OperatingMode m) {
    switch (m) {
        case MODE_COVERT:     return "COV";
        case MODE_HIGH_ALERT: return "HI-ALT";
        default:              return "STD";
    }
}

extern "C" const char* modeLongLabel(OperatingMode m) {
    switch (m) {
        case MODE_COVERT:     return "COVERT";
        case MODE_HIGH_ALERT: return "HIGH_ALERT";
        default:              return "STANDARD";
    }
}

// ── Hardware init (runs once in setup on Core 1) ────────────────────────────

static int initRadioHardware() {
    loraSPI.begin(PIN_LORA_SCK, PIN_LORA_MISO, PIN_LORA_MOSI, PIN_LORA_CS);

    // SX1262 needs setTCXO() before beginFSK() — its SPI is already live.
    // LR1121 passes TCXO voltage via beginGFSK() parameter instead.
#ifndef BOARD_T3S3_LR1121
    if (HAS_TCXO) {
        int tcxoState = radio.setTCXO(1.8);
        if (tcxoState != RADIOLIB_ERR_NONE) {
            Serial.printf("[LoRa] TCXO set failed: %d\n", tcxoState);
            return tcxoState;
        }
    }
#endif

    return RADIOLIB_ERR_NONE;
}

static void initCompassBus() {
#if defined(BOARD_T3S3) || defined(BOARD_T3S3_LR1121)
    if (HAS_COMPASS) {
        Wire1.begin(PIN_COMPASS_SDA, PIN_COMPASS_SCL);
        Serial.printf("[I2C1] Compass bus on SDA=%d SCL=%d\n",
                      PIN_COMPASS_SDA, PIN_COMPASS_SCL);
    }
#endif
}

static void printBanner() {
    Serial.println("========================");
    Serial.printf(" %s v%s\n", FW_NAME, FW_VERSION);
    Serial.printf(" Build: %s\n", FW_DATE);
#ifdef BOARD_T3S3
    Serial.println(" Board: LilyGo T3S3");
#elif defined(BOARD_HELTEC_V3)
    Serial.println(" Board: Heltec V3");
#elif defined(BOARD_T3S3_LR1121)
    Serial.println(" Board: T3S3 LR1121");
#endif
    Serial.println(" Mode:  FreeRTOS dual-core");
    Serial.println("========================");
}

// ── Task functions ──────────────────────────────────────────────────────────

static const char* threatLevelStr(ThreatLevel t) {
    switch (t) {
        case THREAT_ADVISORY: return "ADVISORY";
        case THREAT_WARNING:  return "WARNING";
        case THREAT_CRITICAL: return "CRITICAL";
        default:              return "CLEAR";
    }
}

// RSSI_SWEEP_INTERVAL_MS from sentry_config.h (Phase F wall-clock pacing)
#include "sentry_config.h"

// ── Phase K: Boot self-test + async GPS check ────────────────────────
// Results populated by runSelfTest() in setup() and read later when the
// self-test JSONL is written. gpsFixPending is cleared by gpsReadTask on
// first valid 3D fix, or left set until the timeout log fires.
static bool          selfTestRadioOK      = true;
static bool          selfTestAntennaOK    = true;
static volatile bool gpsFixPending        = false;
static unsigned long gpsFixStartMs        = 0;
static bool          gpsFixTimeoutLogged  = false;

// Boot self-test: RSSI sanity, antenna coverage probe. Must complete in
// <500ms (GPS is async, OLED summary is outside this budget). The radio
// must already be initialized by initRadioHardware() + scannerInit();
// this function must not call radio.begin() again (resetting mid-boot
// corrupts chip state on both SX1262 and LR1121).
static void runSelfTest() {
    // ── Issue 10: Radio health. Dual check:
    //   (a) API return codes — setFrequency failing is unambiguous hardware
    //       failure; the chip either did not ack the SPI command or
    //       refused an in-range frequency.
    //   (b) RSSI variance across 5 frequencies spanning 70 MHz — a healthy
    //       receiver sees at least a few dB of natural variation across the
    //       sweep even in RF-quiet rooms. A stuck/clamped read returns the
    //       same value everywhere (commonly -127.5 dBm on LR1121, but the
    //       specific sentinel varies by silicon/temp).
    bool apiFailed = false;
    float probeRssi[5];
    const float healthFreqs[] = { 860.0f, 880.0f, 900.0f, 915.0f, 930.0f };
    for (int i = 0; i < 5; i++) {
        if (radio.setFrequency(healthFreqs[i]) != RADIOLIB_ERR_NONE) {
            apiFailed = true;
            probeRssi[i] = 0.0f;
            continue;
        }
        radio.startReceive();
        delay(10);
#ifdef BOARD_T3S3_LR1121
        probeRssi[i] = radio.getInstantRSSI();
#else
        probeRssi[i] = radio.getRSSI(false);
#endif
    }
    // Variance test: max - min across the 5 probes must be >= 3.0 dB.
    // A silently-broken RX returning a single clamped sentinel reads with
    // 0 dB variance; a live RX sees ~5-15 dB of variation from ambient.
    float minR =  1e6f, maxR = -1e6f;
    for (int i = 0; i < 5; i++) {
        if (probeRssi[i] < minR) minR = probeRssi[i];
        if (probeRssi[i] > maxR) maxR = probeRssi[i];
    }
    float range = maxR - minR;
    bool radioHealthy = (!apiFailed) && (range >= 3.0f);
    selfTestRadioOK = radioHealthy;
    Serial.printf("[SELFTEST] Radio: %s (api_ok=%d range=%.1fdB)\n",
                  radioHealthy ? "OK" : "FAIL",
                  apiFailed ? 0 : 1, range);

    // ── Antenna coverage probe: 10 frequencies across 860-930 MHz. If
    // ALL read below ANTENNA_FLOOR_DBM (-130 dBm) the antenna path is
    // disconnected or severely damaged. Anything above floor on any
    // probe passes — even a single bin of ambient pickup is sufficient
    // evidence of a radiating element.
    const float probeFreqs[] = {
        860.0f, 867.0f, 874.0f, 881.0f, 888.0f,
        895.0f, 902.0f, 909.0f, 916.0f, 930.0f
    };
    bool anyAboveFloor = false;
    for (int i = 0; i < 10; i++) {
        radio.setFrequency(probeFreqs[i]);
#ifdef BOARD_T3S3_LR1121
        radio.startReceive();   // LR1121 drops to standby on setFrequency
#endif
        delay(5);
#ifdef BOARD_T3S3_LR1121
        float rssi = radio.getInstantRSSI();
#else
        float rssi = radio.getRSSI(false);
#endif
        if (rssi > ANTENNA_FLOOR_DBM) anyAboveFloor = true;
    }
    selfTestAntennaOK = anyAboveFloor;
    Serial.printf("[SELFTEST] Antenna: %s\n",
                  anyAboveFloor ? "OK" : "WARN (no signal detected)");

    // ── GPS check: arm the async timer. gpsReadTask clears the flag on
    // first valid 3D fix; loop() logs [SELFTEST] GPS: NO FIX if the
    // deadline passes with the flag still set.
    gpsFixPending       = true;
    gpsFixStartMs       = millis();
    gpsFixTimeoutLogged = false;
    Serial.println("[SELFTEST] GPS: Acquiring... (async)");
}

// Core 1 — LoRa SPI is only touched here, no mutex needed for the radio
static void loRaScanTask(void* param) {
    ScanResult localResult = {};
    GpsData snapGps = {};
    IntegrityStatus snapIntegrity = {};
    uint32_t sweepNum = 0;
    // Phase F (revised): wall-clock pacing for the sub-GHz RSSI sweep.
    // Seeded to 0 so the first loop iteration always sweeps (matches the
    // warm-start intent of the previous cycleCount-based gate).
    uint32_t nextSubGHzSweepMs = 0;
#ifdef BOARD_T3S3_LR1121
    ScanResult24 local24 = {};
#endif

    // ── Main scan loop ────────────────────────────────────────────────────
    for (;;) {
        unsigned long cycleStart = millis();

        // ── PHASE 1: CAD scan FIRST (~1000ms) ────────────────────────
        // Highest-confidence detection. Runs EVERY cycle.
        // Pass last RSSI data for RSSI-guided CAD scanning.
        CadFskResult cadFsk = cadFskScan(radio, sweepNum,
                                          localResult.valid ? &localResult : nullptr);
        // Feed the full sub-GHz CadBandSummary into the candidate engine.
        // Phase G: the aggregate-int detectionEngineIngestCad() shim is gone;
        // the candidate engine reads the band summary directly.
        detectionEngineIngestCadBandSummary(cadFsk.subGHz);
#ifdef BOARD_T3S3_LR1121
        // 2.4 GHz CadBandSummary is confirmer-only on LR1121.
        detectionEngineIngestCad24BandSummary(cadFsk.band24);
#endif

        unsigned long cadDone = millis();

        // Snapshot GPS/integrity under lock
        if (xSemaphoreTake(stateMutex, pdMS_TO_TICKS(50)) == pdTRUE) {
            snapGps = systemState.gps;
            snapIntegrity = systemState.integrity;
            xSemaphoreGive(stateMutex);
        }

        // Evaluate candidate-engine threat from RF/GNSS-correlated evidence,
        // then fold in standalone GNSS integrity state so display/logger/LED
        // reflect the same effective threat that alertTask is now tracking.
        ThreatLevel threat = detectionEngineAssess(snapGps, snapIntegrity);
        ThreatLevel combinedThreat = threat;
        ThreatLevel gnssThreat = (ThreatLevel)snapIntegrity.threatLevel;
        if (gnssThreat > combinedThreat) combinedThreat = gnssThreat;

        // Store threat + CAD results into shared state
        if (xSemaphoreTake(stateMutex, pdMS_TO_TICKS(50)) == pdTRUE) {
            systemState.threatLevel    = combinedThreat;
            systemState.cadDiversity   = cadFsk.diversityCount;
            systemState.cadConfirmed   = cadFsk.confirmedCadCount;
            systemState.cadTotalTaps   = cadFsk.totalActiveTaps;
            systemState.confidenceScore = detectionEngineGetScore();
            systemState.fastScore      = detectionEngineGetFastScore();
            systemState.confirmScore   = detectionEngineGetConfirmScore();
            systemState.anchorFreq     = detectionEngineGetAnchorFreq();
            systemState.bandMask       = detectionEngineGetBandMask();
            systemState.hasCandidate   = detectionEngineHasCandidate();
            systemState.candidateCount = detectionEngineGetCandidateCount();
            xSemaphoreGive(stateMutex);
        }

        // ── PHASE 2: RSSI sweep on its own wall-clock cadence ──────
        // Phase F (revised): sweep fires when nextSubGHzSweepMs has been
        // crossed, independent of CAD cycle duration. The period
        // (RSSI_SWEEP_INTERVAL_MS) must exceed the long-cycle wall time
        // (cycle-with-sweep) on every board so the timer actually skips
        // iterations instead of re-firing immediately on the next pass.
        //
        // Phase H: in HIGH_ALERT the period extends to
        // HIGH_ALERT_RSSI_INTERVAL_MS so CAD gets the scan budget. The
        // sweep still runs occasionally as a sanity check — candidate
        // engine keeps working either way since CAD produces its own
        // evidence.
        OperatingMode mode = modeGet();
        uint32_t rssiPeriodMs = (mode == MODE_HIGH_ALERT)
                              ? HIGH_ALERT_RSSI_INTERVAL_MS
                              : RSSI_SWEEP_INTERVAL_MS;
        bool didRssi = false;
        if ((int32_t)(millis() - nextSubGHzSweepMs) >= 0) {
            unsigned long sweepStart = millis();
            scannerSweep(radio, localResult);

#ifdef BOARD_T3S3_LR1121
            scannerSweep24(radio, local24);
#endif
            didRssi = true;

            // Update shared state with RSSI data
            if (xSemaphoreTake(stateMutex, pdMS_TO_TICKS(50)) == pdTRUE) {
                systemState.spectrum = localResult;
#ifdef BOARD_T3S3_LR1121
                systemState.spectrum24 = local24;
#endif
                systemState.lastSweepMs = millis();
                xSemaphoreGive(stateMutex);
            }

            // Ingest fresh sweep + re-assess with new RSSI data
#ifdef BOARD_T3S3_LR1121
            detectionEngineIngestSweep(localResult, &local24);
#else
            detectionEngineIngestSweep(localResult, nullptr);
#endif
            threat = detectionEngineAssess(snapGps, snapIntegrity);
            combinedThreat = threat;
            gnssThreat = (ThreatLevel)snapIntegrity.threatLevel;
            if (gnssThreat > combinedThreat) combinedThreat = gnssThreat;
            if (xSemaphoreTake(stateMutex, pdMS_TO_TICKS(50)) == pdTRUE) {
                systemState.threatLevel    = combinedThreat;
                systemState.fastScore      = detectionEngineGetFastScore();
                systemState.confirmScore   = detectionEngineGetConfirmScore();
                systemState.anchorFreq     = detectionEngineGetAnchorFreq();
                systemState.bandMask       = detectionEngineGetBandMask();
                systemState.hasCandidate   = detectionEngineHasCandidate();
                systemState.candidateCount = detectionEngineGetCandidateCount();
                xSemaphoreGive(stateMutex);
            }

            // Advance timer AFTER sweep completes so the period is measured
            // from sweep-end to next-fire-start. Advancing before the sweep
            // would make the next deadline expire while the current sweep
            // is still running, causing the gate to fire on every iteration.
            nextSubGHzSweepMs = millis() + rssiPeriodMs;
        }

        // Log to SD/SPIFFS — zero-init prevents garbage if mutex path is skipped.
        // Only write when the snapshot is real (mutex acquired).
        SystemState logSnapshot = {};
        bool snapshotValid = false;
        if (xSemaphoreTake(stateMutex, pdMS_TO_TICKS(10))) {
            logSnapshot = systemState;
            xSemaphoreGive(stateMutex);
            snapshotValid = true;
        }
        if (snapshotValid) {
            loggerWrite(logSnapshot, sweepNum++);
        }

        unsigned long cycleEnd = millis();

        // Serial output
        if (xSemaphoreTake(serialMutex, pdMS_TO_TICKS(50)) == pdTRUE) {
            // Timing instrumentation
            if (didRssi) {
                Serial.printf("[SCAN] CAD:%lums RSSI:%lums Total:%lums | Threat: %s\n",
                              cadDone - cycleStart,
                              cycleEnd - cadDone,
                              cycleEnd - cycleStart,
                              threatLevelStr(combinedThreat));
                scannerPrintCSV(localResult);
                Serial.printf("[SCAN] Peak: %.1f MHz @ %.1f dBm (%lu ms)\n",
                              localResult.peakFreq, localResult.peakRSSI,
                              localResult.sweepTimeMs);

                // 902-928 MHz US band peak analysis
                {
                    int startBin = (int)((902.0f - SCAN_FREQ_START) / SCAN_FREQ_STEP);
                    int endBin   = (int)((928.0f - SCAN_FREQ_START) / SCAN_FREQ_STEP);
                    if (endBin >= SCAN_BIN_COUNT) endBin = SCAN_BIN_COUNT - 1;
                    int bandBins = endBin - startBin + 1;

                    float nf = -120.0f;
                    for (int step = startBin; step <= endBin; step += 7) {
                        float candidate = localResult.rssi[step];
                        int below = 0, equal = 0;
                        for (int j = startBin; j <= endBin; j++) {
                            if (localResult.rssi[j] < candidate) below++;
                            else if (localResult.rssi[j] == candidate) equal++;
                        }
                        if (below <= bandBins / 2 && (below + equal) > bandBins / 2) {
                            nf = candidate;
                            break;
                        }
                    }

                    float relThresh = nf + 15.0f;
                    float absThresh = -85.0f;
                    float thresh = (relThresh > absThresh) ? relThresh : absThresh;

                    int elrsPeaks = 0;
                    float bestFreq = 0, bestRssi = -200;
                    for (int i = startBin + 1; i < endBin; i++) {
                        if (localResult.rssi[i] > thresh &&
                            localResult.rssi[i] > localResult.rssi[i-1] &&
                            localResult.rssi[i] > localResult.rssi[i+1]) {
                            elrsPeaks++;
                            if (localResult.rssi[i] > bestRssi) {
                                bestRssi = localResult.rssi[i];
                                bestFreq = SCAN_FREQ_START + (i * SCAN_FREQ_STEP);
                            }
                        }
                    }
                    if (elrsPeaks > 0) {
                        Serial.printf("[SCAN-PEAKS] 902-928: %d peaks, best %.1f MHz @ %.1f dBm (NF:%.0f)\n",
                                      elrsPeaks, bestFreq, bestRssi, nf);
                    }
                }
            } else {
                Serial.printf("[SCAN] CAD:%lums | Threat: %s\n",
                              cadDone - cycleStart, threatLevelStr(combinedThreat));
            }

            // Phase E: per-band visibility — subConf (sub-GHz confirmed CAD,
            // time-gated), sub24Conf (2.4 GHz confirmed CAD, LR1121 only),
            // fastConf (sub-GHz fast-confirmed CAD, no time gate). subConf and
            // sub24Conf together replace the aggregate `conf` field that mixed
            // both bands and made LR1121 debugging blind.
            int sub24ConfLog = 0;
#ifdef BOARD_T3S3_LR1121
            sub24ConfLog = cadFsk.band24.confirmedCadCount;
#endif
            if (cadFsk.subGHz.anchor.valid) {
                Serial.printf("[CAD] cycle=%u subConf=%d sub24Conf=%d fastConf=%d taps=%d div=%d persDiv=%d vel=%d sustainedCycles=%d score=%d fast=%d confirm=%d anchor=%.1fMHz SF%u hits=%u\n",
                              sweepNum,
                              cadFsk.subGHz.confirmedCadCount,
                              sub24ConfLog,
                              cadFsk.subGHz.fastConfirmedCadCount,
                              cadFsk.totalActiveTaps, cadFsk.diversityCount,
                              cadFsk.persistentDiversityCount,
                              cadFsk.diversityVelocity,
                              cadFsk.sustainedCycles,
                              detectionEngineGetScore(),
                              detectionEngineGetFastScore(),
                              detectionEngineGetConfirmScore(),
                              cadFsk.subGHz.anchor.frequency,
                              cadFsk.subGHz.anchor.sf,
                              cadFsk.subGHz.anchor.consecutiveHits);
            } else {
                Serial.printf("[CAD] cycle=%u subConf=%d sub24Conf=%d fastConf=%d taps=%d div=%d persDiv=%d vel=%d sustainedCycles=%d score=%d fast=%d confirm=%d anchor=none\n",
                              sweepNum,
                              cadFsk.subGHz.confirmedCadCount,
                              sub24ConfLog,
                              cadFsk.subGHz.fastConfirmedCadCount,
                              cadFsk.totalActiveTaps, cadFsk.diversityCount,
                              cadFsk.persistentDiversityCount,
                              cadFsk.diversityVelocity,
                              cadFsk.sustainedCycles,
                              detectionEngineGetScore(),
                              detectionEngineGetFastScore(),
                              detectionEngineGetConfirmScore());
            }

            xSemaphoreGive(serialMutex);
        }
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
void loop() {
    // Print stack stats once after 30 seconds
    static bool statsPrinted = false;
    if (!statsPrinted && millis() > 30000) {
        printStackStats();
        statsPrinted = true;
    }

    // Periodic heap monitoring — detect memory leaks over time
    static unsigned long lastHeapPrint = 0;
    if (millis() - lastHeapPrint > 300000) {
        if (xSemaphoreTake(serialMutex, pdMS_TO_TICKS(50)) == pdTRUE) {
            Serial.printf("[HEAP] Free: %u bytes (min: %u)\n",
                          ESP.getFreeHeap(), ESP.getMinFreeHeap());
            xSemaphoreGive(serialMutex);
        }
        lastHeapPrint = millis();
    }

    vTaskDelay(pdMS_TO_TICKS(1000));
}

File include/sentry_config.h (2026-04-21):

#ifndef SENTRY_CONFIG_H
#define SENTRY_CONFIG_H

#include <stdint.h>

// =====================================================================
//  SENTRY-RF Configuration — All tunable detection constants
//  Adjust these for field calibration without hunting through code.
//  Hardware constants (pins, SPI, I2C) remain in board_config.h.
//  FreeRTOS task config remains in task_config.h.
// =====================================================================

// ── Phase H: Operational modes ────────────────────────────────────────
// STANDARD:   default — full CAD + RSSI + WiFi + OLED + buzzer + LED
// COVERT:     RF scanning only; WiFi deinitialized, OLED off, buzzer
//             and LED suppressed. Serial + SD logging stay active.
// HIGH_ALERT: CAD every cycle; RSSI sweep skipped except every
//             HIGH_ALERT_RSSI_INTERVAL_MS. Buzzer fires immediately on
//             any WARNING/CRITICAL event (no reminder debounce).
enum OperatingMode : uint8_t {
    MODE_STANDARD   = 0,
    MODE_COVERT     = 1,
    MODE_HIGH_ALERT = 2
};

// RSSI sweep period while in HIGH_ALERT (ms). Still runs periodically as
// a sanity check; the normal RSSI_SWEEP_INTERVAL_MS (8000) is replaced by
// this larger value to free scan budget for back-to-back CAD cycles.
#define HIGH_ALERT_RSSI_INTERVAL_MS  10000

// ── RSSI Detection Thresholds ─────────────────────────────────────────
static const float PEAK_THRESHOLD_DB     = 10.0f;  // dB above noise floor for peak extraction
static const float PEAK_ABS_FLOOR_DBM    = -85.0f; // dBm minimum for RSSI peak
static const int   MAX_PEAKS             = 8;       // max peaks extracted per sweep

// NOTE: ANTENNA_CHECK_THRESHOLD_DBM lives in board_config.h — noise floor
// differs per chipset (SX1262 ~-110 dBm, LR1121 ~-127 dBm) so the threshold
// must be board-specific to avoid false positives.

// Variance floor for the antenna self-test. This is a SANITY gate, not the
// primary discriminator — bare SMA stubs in strong RF can still show 15-20 dB
// variance due to frequency-selective pickup. 3 dB just catches completely
// dead reception. The per-board ANTENNA_CHECK_THRESHOLD_DBM in board_config.h
// is the real discriminator. Variance is logged for operator diagnostics.
static const float ANTENNA_CHECK_VARIANCE_DB = 3.0f;

// ── Band Energy Trending (902-928 MHz) ────────────────────────────────
static const int   BAND_ENERGY_HISTORY   = 10;      // sweeps in rolling average
static const float BAND_ENERGY_THRESH_DB = 8.0f;    // dB above baseline (5.0 caused bench false WARNING)

// ── RSSI Persistence ──────────────────────────────────────────────────
static const int   MAX_TRACKED           = 8;       // max tracked persistent signals
static const float TRACK_FREQ_TOLERANCE  = 0.2f;    // MHz — +/-200 kHz for matching
static const int   PERSIST_THRESHOLD     = 3;       // consecutive sweeps to confirm
static const int   MAX_PROTO_TRACKED     = 14;      // max tracked protocol signatures

// ── Threat Timing ─────────────────────────────────────────────────────
static const unsigned long COOLDOWN_MS   = 5000;    // ms before threat decays one level (was 15000)

// ── Scan Pacing (Phase F: wall-clock timers) ──────────────────────────
// Replaces the cycle-count gates used pre-Phase-F. Each period must be
// strictly greater than that board's short-cycle wall time for the
// timer to actually skip cycles — otherwise the gate fires every
// iteration and degrades into "no gate".
//
// LR24_CAD_PERIOD_MS is only consumed inside #ifdef BOARD_T3S3_LR1121
// blocks in cad_scanner.cpp, so it does NOT need a per-board branch
// here. SX1262 targets never reach the 2.4 GHz code path.
#define LR24_CAD_PERIOD_MS       6000

// RSSI_SWEEP_INTERVAL_MS is consumed in shared loRaScanTask code in
// main.cpp. Both SX1262 and LR1121 need a period strictly greater than
// their long-cycle time (cycle-with-sweep), otherwise the timer expires
// during the same iteration and the gate degrades to "fire every cycle".
// Measured long cycles: LR1121 ~4.3 s, SX1262 ~3.9 s. 8000 ms leaves
// comfortable headroom on both boards and produces roughly the old
// every-3rd-cycle cadence at each board's native tempo. Also: the timer
// is advanced AFTER scannerSweep() completes (see main.cpp) so the
// period measures sweep-end → next-fire-start, not start → start.
#define RSSI_SWEEP_INTERVAL_MS   8000

// ── Rapid-Clear Path ──────────────────────────────────────────────────
// Rapid-clear: force CLEAR after this many ms of candidate-CLEAR silence.
// Ported to the candidate FSM in Phase G.1b — previously owned by the
// legacy assessThreat() path. See detection_engine.cpp rapidClearSinceMs.
static const unsigned long RAPID_CLEAR_CLEAN_MS = 5000;
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

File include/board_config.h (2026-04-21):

#ifndef BOARD_CONFIG_H
#define BOARD_CONFIG_H

#include <stdint.h>

// ============================================================
// SENTRY-RF Board Pin Configuration
// All hardware pin assignments live here — never hardcode pins
// in source files. Use these symbols everywhere.
// ============================================================

#ifdef BOARD_T3S3
// ----- LilyGo T3S3 -----

// SX1262 LoRa SPI
static const int PIN_LORA_SCK  = 5;
static const int PIN_LORA_MISO = 3;
static const int PIN_LORA_MOSI = 6;
static const int PIN_LORA_CS   = 7;
static const int PIN_LORA_RST  = 8;
static const int PIN_LORA_DIO1 = 33;
static const int PIN_LORA_BUSY = 34;

// OLED SSD1306 I2C
static const int PIN_OLED_SDA = 18;
static const int PIN_OLED_SCL = 17;
static const int PIN_OLED_RST = -1;  // T3S3 has no OLED reset pin
static const int PIN_OLED_VEXT = -1; // T3S3 has no Vext control

// Compass QMC5883L I2C — connected via QWIIC connector (GPIO 10/21)
static const int PIN_COMPASS_SDA = 21;
static const int PIN_COMPASS_SCL = 10;

// GPS UART1
static const int PIN_GPS_RX = 44;
static const int PIN_GPS_TX = 43;

// SD card SPI — separate bus from LoRa (T3S3 v1.3 hardware doc)
static const int PIN_SD_CS   = 13;
static const int PIN_SD_SCK  = 14;
static const int PIN_SD_MISO = 2;
static const int PIN_SD_MOSI = 11;

// Status LED and button
static const int PIN_LED  = 37;
static const int PIN_BOOT = 0;   // BOOT button, active LOW

// Buzzer
static const int PIN_BUZZER = 16;  // GPIO 16 — PWM-capable, on header
static const bool HAS_BUZZER = true;

// Board capabilities
static const bool HAS_OLED_RST  = false;
static const bool HAS_OLED_VEXT = false;
static const bool HAS_TCXO      = false;
static const bool HAS_PSRAM     = true;
static const bool HAS_SD_CARD   = true;
static const bool HAS_COMPASS   = true;
static const bool HAS_LR1121    = false;
static const bool HAS_24GHZ     = false;
static const bool WIFI_ENABLED  = true;

// Phase M: BLE Remote ID scanning (ASTM F3411 BLE). All three boards are
// ESP32-S3-based with BLE 5.0, so this is enabled on every target. The
// BLE stack shares the 2.4 GHz radio with WiFi — the BLE scan task uses
// a 10% duty cycle (50ms window / 500ms interval) to minimize WiFi impact.
#define HAS_BLE_RID 1

// Antenna boot self-test peak threshold — primary discriminator.
// With antenna connected we expect ambient 915 MHz pickup above -95 dBm in
// any populated area; bare SMA stubs top out around -105 to -110 dBm even
// near strong emitters. -100 gives ~8 dB margin below worst-case stub pickup.
static const float ANTENNA_CHECK_THRESHOLD_DBM = -100.0f;

#elif defined(BOARD_HELTEC_V3)
// ----- Heltec WiFi LoRa 32 V3 -----

// SX1262 LoRa SPI
static const int PIN_LORA_SCK  = 9;
static const int PIN_LORA_MISO = 11;
static const int PIN_LORA_MOSI = 10;
static const int PIN_LORA_CS   = 8;
static const int PIN_LORA_RST  = 12;
static const int PIN_LORA_DIO1 = 14;
static const int PIN_LORA_BUSY = 13;

// OLED SSD1306 I2C
static const int PIN_OLED_SDA = 17;
static const int PIN_OLED_SCL = 18;
static const int PIN_OLED_RST = 21;   // Must pulse LOW 50ms then HIGH
static const int PIN_OLED_VEXT = 36;  // Set LOW to power OLED

// GPS UART1
static const int PIN_GPS_RX = 46;
static const int PIN_GPS_TX = 45;

// Status LED and button
static const int PIN_LED  = 35;
static const int PIN_BOOT = 0;   // BOOT button, active LOW

// Buzzer
static const int PIN_BUZZER = 47;  // GPIO 47 — PWM-capable
static const bool HAS_BUZZER = true;

// Board capabilities
static const bool HAS_OLED_RST  = true;
static const bool HAS_OLED_VEXT = true;
static const bool HAS_TCXO      = true;  // Must call setTCXO(1.8) before begin()
static const bool HAS_PSRAM     = false;
static const bool HAS_SD_CARD   = false;
static const bool HAS_COMPASS   = false;
static const bool HAS_LR1121    = false;
static const bool HAS_24GHZ     = false;
static const bool WIFI_ENABLED  = true;

// Phase M: BLE Remote ID scanning — see comment in BOARD_T3S3 block.
#define HAS_BLE_RID 1

// Antenna boot self-test peak threshold — same SX1262 chipset as T3S3
static const float ANTENNA_CHECK_THRESHOLD_DBM = -100.0f;

#elif defined(BOARD_T3S3_LR1121)
// ----- LilyGo T3S3 with LR1121 (dual-band: sub-GHz + 2.4 GHz) -----
// Identical pin mapping to T3S3 SX1262 — only the radio chip differs

// LR1121 LoRa SPI (same SPI bus as T3S3 SX1262, but IRQ is DIO9 not DIO1)
static const int PIN_LORA_SCK  = 5;
static const int PIN_LORA_MISO = 3;
static const int PIN_LORA_MOSI = 6;
static const int PIN_LORA_CS   = 7;
static const int PIN_LORA_RST  = 8;
static const int PIN_LORA_DIO1 = 36;   // LR1121 uses DIO9 (GPIO 36) as IRQ, not DIO1
static const int PIN_LORA_BUSY = 34;
static const float LR1121_TCXO_VOLTAGE = 3.0f;  // LR1121 TCXO is 3.0V (2.85-3.15V range)

// OLED SSD1306 I2C
static const int PIN_OLED_SDA = 18;
static const int PIN_OLED_SCL = 17;
static const int PIN_OLED_RST = -1;
static const int PIN_OLED_VEXT = -1;
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

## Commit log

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2026-03-20 Sprint 4: GNSS integrity monitoring — jamming/spoofing detection with MON-HW, NAV-STATUS, NAV-SAT auto callbacks, C/N0 analysis, UART buffer hardening
    [display.cpp, gps_manager.cpp, main.cpp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]
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2026-03-20 Fix calibration timer bug in displayTask — use dedicated calDisplayStartMs instead of peakTimestamp
    [main.cpp]
2026-03-20 Sprint 10: UI overhaul — custom splash logo, dashboard summary screen, display fixes, v1.0.0
    - Custom 128x64 bitmap boot splash (2-second display)
    - Dashboard summary screen: threat level, mini spectrum, GPS/jam/spoof, battery, WiFi mode
    - 6 screens on SX1262, 7 on LR1121 (adds 2.4 GHz spectrum)
    - Battery monitoring via GPIO 1 ADC
    - Display overflow fixes: GPS coords 5dp, shortened dashboard labels, peak text positioning
    - Jam/AGC show "---"/"--" when MON-HW data not yet received
    - Button debounce: 100ms minimum hold, ghost press filtering
    - WiFi AP password updated
    - v1.0.0 — feature complete
    [display.cpp, main.cpp]
2026-03-20 Sprint 11: Field hardening — GPS_MIN_CNO=15, MON-HW fast-path removal, boot counter, heap monitoring, README overhaul, v1.1.0
    - GPS_MIN_CNO raised to 15 for production (was 6 for indoor bench testing)
    - Removed isAlreadyConfigured() fast path — always run configureUBX() to ensure MON-HW/NAV-STATUS/NAV-SAT message output is enabled
    - RTC boot counter for stability monitoring
    - Periodic heap leak detection (every 5 minutes, prints free + min-ever heap)
    - Comprehensive README.md: hardware tables, wiring, quick start, capabilities, limitations
    - v1.1.0 field-ready release
    NOTE: MON-HW jammingState still reads 0 — may require polling fallback or MON-HW2 on M10. Needs further investigation.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
    [gps_manager.cpp, main.cpp]
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2026-03-27 Add audible buzzer alert system with intelligent suppression
    Buzzer Manager (new):
    - Non-blocking tone pattern player using ESP32 LEDC PWM (channel 1)
    - 7 distinct tone patterns: self-test, RF advisory/warning, GNSS warning,
    Remote ID detect, critical sustained, all-clear descending
    - Volume control via duty cycle (default 50%)
    - Ascending 3-tone self-test beep on boot
    Alert Handler (rewritten):
    - Escalation-only alerting: buzzer fires on threat level increase only
    - ADVISORY = silent (prevents alert fatigue from ISM band traffic)
    - WARNING/CRITICAL = audible with source-specific patterns
    - 30-second reminder beep for unacknowledged sustained threats
    - ALL_CLEAR descending tone on de-esca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
    [alert_handler.cpp, board_config.h, buzzer_manager.cpp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]
2026-03-27 Fix screen rotation tearing: frozen renderScreen, 100ms refresh
    - Capture currentScreen into local renderScreen before render phase
    so screen index can't change between clearDisplay and display()
    - Reduced vTaskDelay from 200ms to 100ms (10 Hz) for snappier updates
    - Clear 3-phase loop: input → snapshot → render → delay
    - Updated calibration screen help text for new button gestures
    [main.cpp]
2026-03-27 Fix LED (off at ADVISORY), faster boot, screen rotation debug
    LED behavior:
    - CLEAR + ADVISORY = LED OFF (ambient ISM traffic doesn't light LED)
    - WARNING = fast blink (confirmed drone signal)
    - CRITICAL = solid ON
    - Previously ADVISORY caused slow blink which appeared "always on"
    Boot time reduced:
    - Serial settle: 1000ms → 500ms
    - GPS CDC settle: 2000ms → 500ms
    - Total boot: ~13s → ~9s (GPS timeout still ~6s when no module)
    Screen rotation:
    - Added [DISPLAY] debug print showing screen index and ms since last
    - Confirmed 5-second auto-rotate is working correctly
    [alert_handler.cpp, gps_manager.cpp, main.cpp]
2026-03-27 Fix LED, boot time, screen rendering rate
    LED behavior (rewritten):
    - LED OFF for CLEAR and ADVISORY (was blinking at ADVISORY)
    - LED blinks only at WARNING, solid at CRITICAL
    - Cleaner state tracking with explicit ledOn flag
    - Fixes "LED always on" caused by ambient ISM triggering ADVISORY
    Boot time:
    - Serial delay 1000ms → 300ms
    - GPS CDC settle 2000ms → 500ms
    - Splash reduced to 1000ms
    - Added "Initializing..." OLED message during hardware init
    (user sees status instead of static splash during GPS timeout)
    - Boot marker: "SENTRY-RF v1.2.0-FIX4" for flash verification
    Screen rendering:
    - Render rate reduced from 10 Hz to 2 Hz (500ms between renders)
    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
    [alert_handler.cpp, display.cpp, main.cpp]
2026-03-27 Fix boot splash, I2C speed, LED threshold
    Boot:
    - Splash logo stays on screen during entire hardware init sequence
    - Removed "Initializing..." overlay that replaced the splash
    - No delay after splash — init starts immediately, splash persists
    - I2C clock set to 400kHz (was default 100kHz)
    - 4x faster display() transfers: ~20ms instead of ~82ms
    - Should eliminate visible sectioned/phased screen updates
    LED:
    - Only activates at CRITICAL level (was WARNING)
    - Ambient ISM traffic reaches WARNING via persistence tracking
    but WARNING is not a confirmed drone — only CRITICAL is
    - Added [LED] debug logging to serial for diagnostics
    - Boot blink test (2 quick blinks) to veri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
    [alert_handler.cpp, display.cpp, main.cpp]
2026-03-27 Move display to Core 0 (fixes screen tearing), LED 5s CRITICAL hold
    Screen tearing root cause:
    - LoRa scan task (priority 3, Core 1) uses delayMicroseconds()
    busy-wait for 2.4s per sweep, starving the display task (priority 1,
    Core 1) of CPU time. The OLED I2C transfer got split across multiple
    10ms gaps between sweeps, causing visible sectioned updates.
    - Fix: moved displayTask from Core 1 to Core 0 where GPS and WiFi
    tasks run with short burst patterns, giving display uncontested
    I2C bus access for clean full-frame updates.
    - Only activates after CRITICAL has been sustained for 5+ continuous
    seconds. Brief ambient spikes to CRITICAL are filtered out.
    - Boot self-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
    [alert_handler.cpp, main.cpp]
2026-03-27 v1.2.1: Disable LED until field-tested, display on Core 0, splash fix
    - Disabled all LED control — digitalWrite(PIN_LED, LOW) only.
    - Root cause: ambient 868 MHz ISM traffic escalates detection engine
    to WARNING/CRITICAL, triggering the LED on bench without real drones.
    - LED behavior will be re-enabled after field testing with real drones
    establishes thresholds that don't false-alarm on ambient.
    - Removed boot blink test (300ms of delays removed from boot).
    Display:
    - Task moved to Core 0 (previous commit) — LoRa sweep on Core 1
    was starving display of CPU time, causing sectioned screen updates.
    - Splash stays on screen during entire hardware init.
    - I2C at 400kHz for fast f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
    [alert_handler.cpp, main.cpp]
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2026-03-30 CAD detection engine v2: fishing pole scan-and-verify architecture
    - SX1262 FSK↔LoRa mode switching via low-level SPI SetPacketType command
    (bypasses RadioLib begin() which causes -707 chip reset failure)
    - Scan all 6 LoRa spreading factors (SF6-SF12 at BW500) covering all
    ELRS packet rates from 25Hz to 200Hz
    - Tap-and-verify algorithm: CAD hits tracked as taps, confirmed after
    3 consecutive cycles, expired after 3 consecutive misses
    - Ambient CAD filter: environmental LoRa sources recorded during 20-cycle
    warmup excluded from confirmed detection counts
    - Post-warmup ambient catch: taps first seen during warmup but confirmed
    later are retroactively classified as infrastructure
    -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
    [cad_scanner.cpp, gps_manager.cpp, main.cpp]
2026-03-31 Sprint 12: Fix CAD detection and optimize scan strategy
    ROOT CAUSE FIX: After raw SPI packet type switch from FSK to LoRa,
    RadioLib's internal codingRate/ldrOptimize fields remained zeroed from
    beginFSK() init. setSpreadingFactor() passed these zeroed values to
    setModulationParams(), producing invalid LoRa modem config that broke
    CAD detection entirely (0% hit rate). Fix: call setCodingRate(5) before
    setSpreadingFactor(6) to properly initialize all modem params.
    Boot test went from 0/1384 (0.0%) to 4/1384 (0.3%) — CAD now detects
    ELRS preambles. The 0.3% rate matches theoretical prediction for SF6
    BW500 8-symbol preamble (~1ms) across 80 FHSS channels at 130 Hz.
    Scan strategy improvement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
    [cad_scanner.cpp, main.cpp]
2026-03-31 Sprint 12b: CAD-as-discriminator threat escalation + band energy trending
    Redesign threat assessment: CAD is now a discriminator, not a primary
    detector. One CAD tap corroborated with persistent RSSI in 902-928 MHz
    = CRITICAL. This accepts the physics reality that a single-channel
    scanner gets ~0.3% CAD hit rate against 80-channel FHSS, while RSSI
    reliably detects the aggregate energy every cycle.
    New escalation rules:
    HIGH = confirmed CAD (3+ hits) OR any CAD activity + persistent RSSI
    MEDIUM = persistent RSSI in US band OR band energy elevated OR strong CAD
    LOW = RSSI in EU overlap band without CAD (unchanged)
    Changes:
    1. assessThreat() rewritten with CAD+RSSI corroboration logic
    2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
    [cad_scanner.cpp, main.cpp]
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2026-03-31 Sprint 1A: Ambient CAD tap warmup filter + US-band-only RSSI persistence
    Warmup filter (20 cycles, ~50s): records LoRa taps with 2+ consecutive
    hits during boot as ambient infrastructure (LoRaWAN gateways, Meshtastic
    nodes). After warmup, ambient taps are excluded from ALL counts that feed
    threat escalation (confirmed, strongPending, totalActive).
    Added isAmbient field to CadTap struct for per-tap visibility. AmbientTap
    struct tracks frequency, SF, and firstSeenCycle. Post-warmup catch handles
    taps first seen during warmup that take extra cycles to confirm.
    Fixed false WARNING on baseline: countPersistentProtocolUS() now only
    counts protocol matches with minFreqSeen >= 902 MHz. Previously,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
    [cad_scanner.cpp]
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2026-04-01 Sprint 2B: Centralized config, rapid-clear path, reduced cooldown
    Part 1 — sentry_config.h: All tunable detection constants centralized
    in one file. Removed local definitions from cad_scanner.h/cpp,
    detection_engine.cpp, ambient_filter.h, gnss_integrity.cpp, alert_handler.cpp,
    and main.cpp. Field calibration now requires editing one file.
    Part 2 — Field thresholds: COOLDOWN_MS 30s→15s (45s max decay vs 90s),
    AMBIENT_AUTOLEARN_MS 10s→60s (prevents absorbing drone frequencies),
    BAND_ENERGY_THRESH_DB 3→5 dB (margin for outdoor thermal variation).
    Part 3 — Rapid-clear path: After 4 consecutive clean cycles (no confirmed
    CAD, no strong pending), threat jumps directly to CLEAR regard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
    [alert_handler.cpp, cad_scanner.cpp, main.cpp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]
2026-04-01 Sprint 2B-fix: Post-warmup state reset + live-tap threat assessment
    Root cause: after warmup guard lifted, RSSI persistence counters and
    recentHitCount had accumulated ambient signals during warmup, causing
    immediate CRITICAL on first post-warmup cycle.
    Fixes:
    - Post-warmup one-time reset: clear all RSSI persistence trackers,
    band energy history, proto trackers, and tracked signals when warmup
    transitions from active to complete. Drone signals rebuild in seconds.
    - assessThreat uses totalActiveTaps (live per-cycle) instead of
    recentHits (30s rolling buffer) for medium/high confidence — the 30s
    buffer accumulates ambient hits on LoRa-rich bench.
    - mediumConfidence requires rssiPers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
    [sentry_config.h]
2026-04-01 Frequency diversity detection engine — replace hit counting with FHSS spread
    Architecture rethink: the discriminator for FHSS drones isn't HOW MANY
    CAD hits occur, it's HOW MANY DISTINCT FREQUENCIES produce hits within
    a short time window. Drones hit many frequencies (FHSS); infrastructure
    hits the same 1-3 frequencies repeatedly.
    Implementation:
    - FrequencyDiversityTracker replaces recentHitTimestamps ring buffer
    - Records distinct freq/SF slots with ±200kHz deduplication
    - 3-second sliding window (short enough to prevent ambient accumulation)
    - diversityCount exposed in CadFskResult, feeds assessThreat()
    Threat assessment rewritten:
    HIGH = diversity >= CRITICAL(8) OR (diversity >= W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
    [cad_scanner.cpp, main.cpp, sentry_config.h]
2026-04-02 Sprint 6: Field test prep — JSONL logging, analysis script, test protocol
    Part 1: GPS_MIN_CNO centralized in sentry_config.h (already 15 for field).
    Part 2: JSONL field test logging alongside legacy CSV on SD card.
    - field_NNNN.jsonl written per cycle with: timestamp, cycle, threat,
    diversity, confirmed, taps, peak freq/RSSI, GPS lat/lon/fix/sv,
    GNSS jam/spoof/cno_sd
    - cadDiversity, cadConfirmed, cadTotalTaps added to SystemState
    - Graceful fallback if no SD card present
    Part 3: Python analysis script (tools/analyze_field_test.py).
    - Loads JSONL, computes Pd/Pfa, time-to-WARNING/CRITICAL
    - Diversity histogram, threat level distribution
    - Supports --baseline-end, --jam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
    [Battery Compartment.3mf, Battery Compartment.FCStd, Display Button.3mf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]
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2026-04-02 Correct field test distances (660m not 3.3km), update README v1.4.0
    CRITICAL FIX: JJ was positioned near the drive start point, not at
    the compound 2.8km away. Actual max detection distance is 637m at
    158 mW, not 3.3km. All field test results and analysis corrected.
    Corrected distances: 0-660m drive test (was 2.8-3.3km).
    Signal at 637m: -66 dBm with 42 dB margin above sensitivity.
    Scan probability (not sensitivity) remains the Pd bottleneck.
    GPS coordinates stripped from all committed files for privacy.
    README rewritten with:
    - Field test results front and center (89% Pd at 200m, 637m max)
    - Frequency diversity as primary detection description
    - Updated threat levels with field-cali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
    [field_analysis.py]
2026-04-03 Sprint 1/5: FSK Phase 3 fix — move after switchToFSK()
    Restructured Phase 3 (Crossfire/FrSky FSK detection) to run AFTER
    switchToFSK() instead of before. This eliminates the LoRa→FSK→LoRa
    sandwich that corrupted RadioLib's internal cached modem parameters
    and inflated CAD false hits.
    New sequence: LoRa CAD (Phases 1-2) → switchToFSK() → Phase 3 (FSK
    scan) → restore RSSI params. All FSK operations happen in a clean
    FSK→FSK→FSK sequence with no LoRa state involved.
    Phase 3 no longer does its own SPI mode switch — it reconfigures
    the already-active FSK mode for Crossfire parameters (85.1 kbps,
    25 kHz deviation, 117.3 kHz BW), scans 4 rotating channels + re-checks
    existing FS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
    [cad_scanner.cpp]
2026-04-03 Sprint 3/5: Band energy re-integration — 8 dB threshold, ADVISORY only, EU band
    Re-integrated bandEnergyElevated as ADVISORY-level indicator (was
    disconnected in Sprint 2C due to bench false alarms).
    - Threshold raised from 5.0 to 8.0 dB (normal variation is 2-4 dB)
    - Feeds lowConfidence (ADVISORY) only, never WARNING/CRITICAL
    - Added EU 868 band energy tracker (860-870 MHz) alongside US 902-928
    - Refactored updateBandEnergy into updateBandEnergyRegion for both bands
    - Combined flag: bandEnergyElevated = US || EU
    - Fixed stale variable names in post-warmup reset and init
    All three targets build clean.
    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
    [sentry_config.h]
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2026-04-03 Sprint 5/5: Weighted confidence scoring replaces boolean threat logic
    Replaced the boolean highConfidence/mediumConfidence/lowConfidence
    conditions (patched across 6+ sprints) with a weighted scoring system.
    Each detection source contributes a configurable weight:
    Diversity: 8 per distinct frequency (div=3 → score=24 → WARNING)
    Confirmed CAD: 15 per tap
    Confirmed FSK: 12 per tap
    RSSI persistent: 10 (US band), 5 (EU band)
    Band energy: 5
    GNSS anomaly: 15
    2.4 GHz: 10
    Score thresholds: ADVISORY=8, WARNING=24, CRITICAL=40
    Calibrated to match previous boolean behavior:
    div=3 → 24 → WARNING (same as DIVERSITY_WARNING=3)
    div=5 → 40 → CRITICAL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
    [data_logger.cpp, main.cpp, sentry_config.h]
2026-04-03 Code review fixes: 5 issues from Sprint 1-5 review
    Issue 1 (Sprint 1): setRxBoostedGainMode moved AFTER Phase 3 FSK param
    restore. Previously called before Phase 3, which could reset boosted
    gain when setRxBandwidth writes to the same register bank.
    Issue 7 (Sprint 3): EU band energy bin range tightened from 0-50 to
    15-50 (863-870 MHz). Bins 0-15 (860-863) are outside EU ISM band.
    Issue 11 (Sprint 4): Pursuit mode now checks which SFs have active taps.
    Only reduces channels for INACTIVE SFs. Previously reduced SF9-12
    unconditionally, risking loss of drones on those SFs.
    Issue 14 (Sprint 5): Removed orphaned DIVERSITY_CRITICAL constant.
    DIVERSITY_WARNING retained (used by pursuit mode), do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
    [cad_scanner.cpp, sentry_config.h]
2026-04-03 Nice-to-fix items from code review
    Issue 2: FSK param error checking — setBitRate(85.1) checked, scan
    skipped if rejected. Restructured from goto to if-else for clean flow.
    Issue 3: FSK threshold lowered from -50 to -70 dBm for field use.
    Crossfire at 100m is ~-60 to -70 dBm; -50 was bench-only.
    Issue 12: Pursuit mode now logs [PURSUIT] Activated/Deactivated to
    serial on state transitions. Operator can see when pursuit fires.
    Issue 17: WiFi Remote ID wired into confidence scoring. wifiScanTask
    sets systemState.remoteIdDetected on RID beacon parse. Detection engine
    adds WEIGHT_REMOTE_ID (20) when RID active within last 10 seconds.
    systemState gains remoteIdDetected and remoteIdLastMs fie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
    [cad_scanner.cpp, sentry_config.h, wifi_scanner.cpp]
2026-04-04 Revert FSK threshold to -50 dBm for bench testing
    Field threshold (-70 dBm) causes immediate CRITICAL on bench from
    ambient ISM energy. Bench ambient is -60 to -70 dBm on Crossfire
    frequencies, producing FSK false positives that inflate score to 60+.
    -50 dBm is bench-safe. Change to -70 before field deployment.
    [sentry_config.h]
2026-04-05 Housekeeping: fix stale version string, update known issues tracker
    - Replace hardcoded "v1.2.0-FIX4" banner in setup() with FW_NAME/FW_VERSION
    - Mark GPS_MIN_CNO, FSK Phase 3, buzzer, band energy, confidence scoring as RESOLVED
    - Add FSK bench/field threshold toggle and boot banner fix as new entries
    - Update tracker date to April 5, 2026
    [main.cpp]
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2026-04-06 AAD Sprint 1.1: Fix persistence gate — sustained diversity instead of per-slot
    Per-slot consecutiveHits filtered drones along with infrastructure because
    FHSS doesn't hit the same frequency in consecutive 2.5s scan cycles.
    New approach: track how many consecutive cycles have raw diversity >= 3
    (sustainedDiversityCycles). When sustained for 2+ cycles, ALL current
    diversity qualifies as persistent. LoRaWAN can't sustain div>=3 across
    consecutive cycles; FHSS drones sustain div=5-15+ every cycle.
    Per-slot consecutiveHits kept for future use but not used for the gate.
    Velocity now tracks sustained-threshold crossings instead of per-slot.
    Serial output adds sustainedCycles=N metric.
    Co-Autho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
    [cad_scanner.cpp, main.cpp, sentry_config.h]
2026-04-06 Fix cooldown hysteresis: prune confirmed taps on sustained-diversity drop
    When sustainedDiversityCycles drops from >=3 to 0 (drone departed),
    aggressively deactivate all non-ambient taps. This prevents confirmed
    CAD taps (conf=11, score=100) from lingering 30+ seconds after the
    drone leaves due to occasional ambient hits resetting their decay timer.
    [cad_scanner.cpp]
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2026-04-06 Update README and BUILD_GUIDE for v1.5.1
    Complete README rewrite reflecting current detection architecture:
    - AAD sustained-diversity persistence gate
    - Confidence scoring with fast-detect bonus
    - Bench-validated performance metrics (5.1s WARNING, 7.4s CRITICAL, 10s CLEAR)
    - Field test results (89% Pd at 200m, 637m max range)
    - Full protocol detection table
    - Configuration reference with all AAD constants
    - Link to JUH-MAK-IN JAMMER companion tool
    BUILD_GUIDE updated:
    - v1.5.1 boot output and serial format
    - Buzzer wiring for both boards
    - Serial output field reference table
    - Updated first boot checklist (buzzer, LED, persDiv verification)
    - Board-specific notes for T3S3 and Heltec V3
    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
    [main.cpp]
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2026-04-06 v1.5.3: 30-min soak 0.00% FP, ELRS CRITICAL in 11.2s
    Persistence gate raised from 3 to 5 cycles — eliminates false
    CRITICAL from ambient LoRa that sustained div>=3 for 4 cycles in
    the 28-min dual-device soak test. Max observed ambient sustained=2
    with new threshold, giving a margin of 3 cycles.
    Fast-detect bonus now requires sustainedCycles > PERSISTENCE_MIN_CONSECUTIVE
    (6+ cycles) before firing, adding a second guard against ambient
    barely crossing the persistence gate.
    GPS serial output rate-limited from every 10ms to every 5s, reducing
    log file size from 28MB to 2.16MB over 30 minutes and preventing
    serial buffer overflow that cut the previous soak test short at 28 min.
    Validation:
    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
    [sentry_config.h]
2026-04-06 Field deployment config: FSK threshold -70 dBm
    FSK_DETECT_THRESHOLD_DBM changed from -50 (bench-safe) to -70 (field
    sensitivity). Required for detecting Crossfire/FrSky at distance.
    GPS_MIN_CNO was already at 15 (field value) — no change needed.
    Do not push: revert to -50 for bench testing.
    [sentry_config.h]
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2026-04-10 LR1121 T3S3: full CAD scanner port + dual-band + diversity gate
    Board bring-up:
    - Fix PERSISTENCE_MIN_CONSECUTIVE for LR1121 (pin DIO9=36 not DIO1=33)
    - Add LR1121_TCXO_VOLTAGE = 3.0V (LR1121 uses 3.0V, not 1.8V)
    - Fix platformio.ini for t3s3_lr1121: 4MB flash + default.csv partition
    - Increase LoRa task stack to 16KB for LR1121 driver
    - Bump USB CDC startup delay to 500ms
    Radio init (rf_scanner.cpp):
    - Set RF switch table (DIO5/DIO6) before beginGFSK
    - Use 7-arg beginGFSK(freq, br, dev, rxBw, pwr, preamble, tcxo) signature
    - Max freq deviation 200 kHz (LR1121 limit, SX1262 allows 234.3)
    - Call startReceive() per-bin in sweep — LR1121 drops to standby on setFrequency
    - Add LR1121_RSSI sub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
    [board_config.h, cad_scanner.cpp, display.cpp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]
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2026-04-11 feat(boot): antenna self-test + fatal error screen + soft-warn
    - scannerAntennaCheck() reads 10 RSSI bins at boot to detect
    missing sub-GHz antenna. Soft-warn only (no halt) per Codex P1
    review — passive RSSI detection false-fails in RF-quiet environments.
    - displayFatalError() and displayWarning() extracted to display.cpp
    for consistent OLED error/warning screens with version header.
    - Per-board ANTENNA_CHECK_THRESHOLD_DBM in board_config.h:
    SX1262/Heltec: -100 dBm, LR1121: -122 dBm (quieter noise floor).
    - T2.3: boot banner print order verified, version visible before
    any init that can fail.
    Known limitation: LR1121 antenna check has ~7 dB separation between
    "no antenna" and "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
    [board_config.h, display.cpp, main.cpp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]
2026-04-11 feat(boot): human-readable error messages for radio init failures
    Add formatRadioError() lookup table in src/error_messages.cpp that
    maps RadioLib error codes to short operator-friendly strings.
    Initial coverage (per SPEC T2.2 + PLAN R7 scope discipline — only
    codes the SPEC explicitly names):
    -2 CHIP_NOT_FOUND -> "Radio chip not found"
    -12 INVALID_FREQUENCY -> "Invalid frequency"
    -102 INVALID_FREQUENCY_DEVIATION -> "Invalid freq dev"
    -707 SPI_CMD_FAILED -> "SPI command failed"
    default fallback -> "Err: %d"
    main.cpp radio HW init and scanner init error paths now display
    the human-readable label on the OLED fatal error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
    [main.cpp]
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
